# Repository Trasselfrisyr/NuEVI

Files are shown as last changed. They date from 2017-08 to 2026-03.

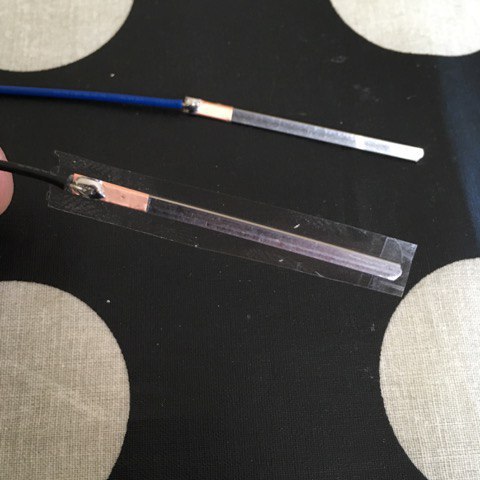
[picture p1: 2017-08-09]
hardware/bitesensor/bitesensor05.jpg

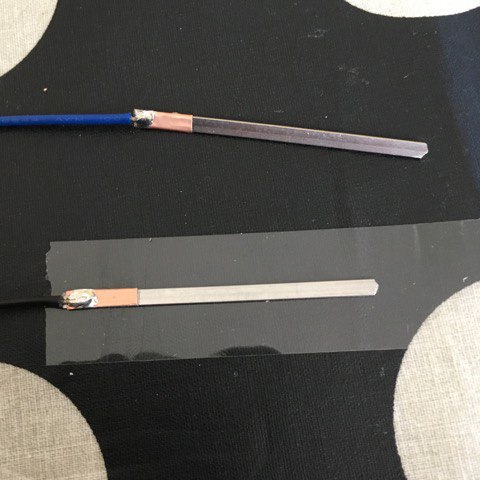
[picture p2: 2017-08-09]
hardware/bitesensor/bitesensor04.jpg

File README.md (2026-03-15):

### ⚠️ ORIGINAL REPO HAS BEEN MOVED TO BERGLUNDINST ORGANISATION ⚠️

This repository exists for archival purposes. Please update any references/links to https://github.com/berglundinst/NuEVI instead.

# NuEVI
A project by wind controller enthusiasts wanting to save the endangered Electronic Valve Instrument.

Follow the project at https://hackaday.io/project/25756-diy-evi-style-windcontroller

## Building NuEVI

NuEVI is easiest to build using the Arduino IDE. You will also need to download and install
[Teensyduino](https://www.pjrc.com/teensy/td_download.html) to build for and upload to the Teensy.

### Libraries

A few libraries need to be added that are not part of the default Arduino install. These can be
added directly via the Library Manager in the Arduino IDE:
* Adafruit MPR121
* Adafruit GFX
* Adafruit SSD1306 (version 1.2.9 or above)
* NuEVI also includes on the [Filters](https://github.com/JonHub/Filters) library by Jonathan Driscoll, but that is no longer an external dependency.

### Compile options

Open NuEVI.ino in the Arduino IDE. Under "Tools -> Board", select "Teensy 3.2 / 3.1". Then set
"Tools -> USB Type" to "MIDI".

### Building and uploading

Connect the NuEVI via USB to your computer, open the Teensy application and make sure the "Auto"
option is selected (the green round icon). In Arduino IDE, select "Sketch -> Verify/Compile" and
once that is complete press the reset button on the Teensy chip (you have to remove the top cover
on the NuEVI to access this). Upon resetting, it should upload the new firmware onto the NuEVI.

After uploading new firmware, you may need to reset the config memory of the NuEVI. To do this, press
and hold the MENU and ENTER buttons while turning on the NuEVI. Note that this resets all sensor calibrations too. For new versions this should not be neccessary, as value and version checks are in place.

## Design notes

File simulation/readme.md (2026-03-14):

# Simulator for NuEVI

This is a simple SDL2 based simulator that runs the NuEVI firmware compiled for MacOS. This is for testing the menu and is not supposed to produce any midi events.

## Requirements

* [SDL2.framework](https://www.libsdl.org/download-2.0.php) must be installed on your machine in /Library/Frameworks/.
* You probably need to have XCode and XCodes command line tools installed as well, but using brew to install make and clang might be enough.

[Dear Imgui](https://github.com/ocornut/imgui) is pulled in as an git submodule. Run `git submodule init --update` to get the code. The code is tested with tag v1.70 of ImGui, so if you run into problems make sure that is the checked out version.

## Know limitations

Currently only some input is simulated, and the default values are not based on real hardware. There is also a limitation on some keyboards on how many buttons can be pressed at the same time. This means that all menu functions cannot be tested.

## Future plans

* Add simulation for all inputs
* Show MIDI status in UI
* Add in-app log window
* Fake real breath input by keypress

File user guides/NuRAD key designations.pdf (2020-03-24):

Key designation chart

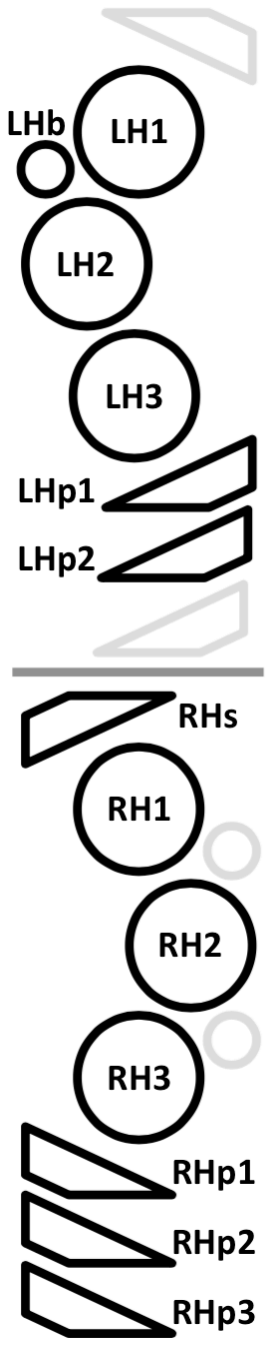
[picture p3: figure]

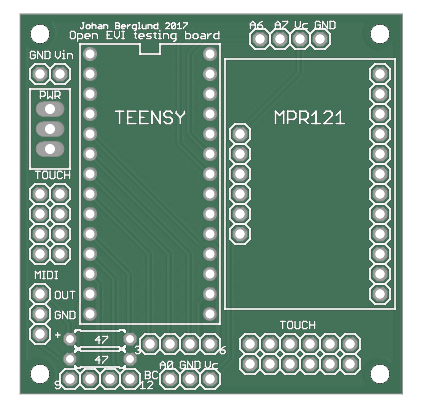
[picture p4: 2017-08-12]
hardware/devboard/devboardprevpic.png

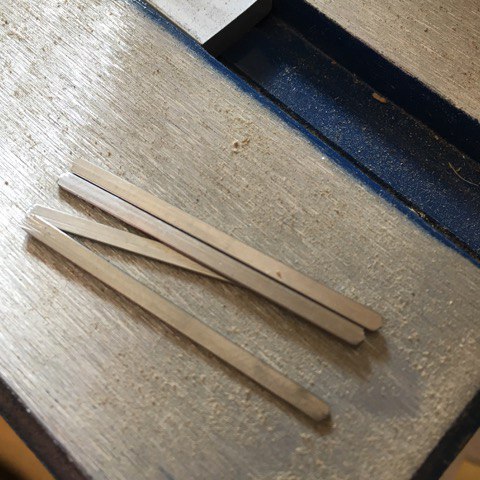
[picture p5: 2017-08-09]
hardware/bitesensor/bitesensor01.jpg

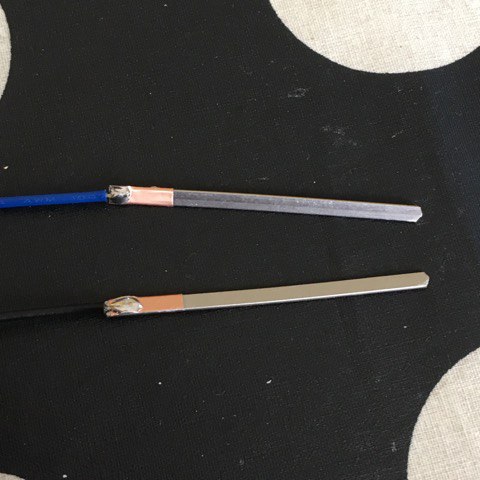
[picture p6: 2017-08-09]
hardware/bitesensor/bitesensor03.jpg

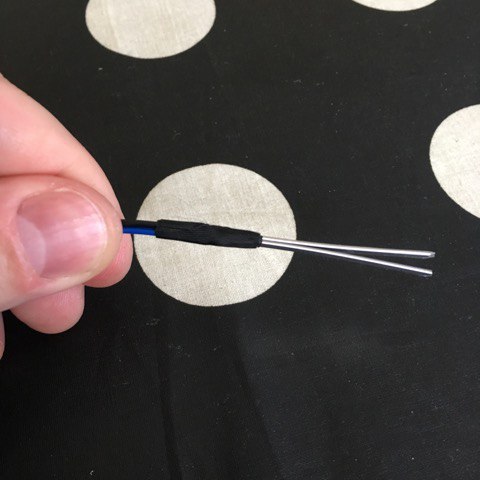
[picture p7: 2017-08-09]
hardware/bitesensor/bitesensor08.jpg

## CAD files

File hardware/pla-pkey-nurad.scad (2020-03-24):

w=8;        //key width, default 8
wc=10;      //mounting end outer diameter, default 10
l=15;       //key length (range normally increase in steps of 5)
hght=3;     //key height, default 3,3.5 and 4
angl=25;    //key end angle, default 25
estp=1.5;    //end step before angle, default 0.5
noext=0;    //set to 1 to get just the round part   

// 20/3,26/3.5,32/4 sk: 15/3 (estp 1.5)

 module prism(l, w, h){
       polyhedron(
               points=[[0,0,0], [l,0,0], [l,w,0], [0,w,0], [0,w,h], [l,w,h]],
               faces=[[0,1,2,3],[5,4,3,2],[0,4,5,1],[0,3,4],[5,2,1]]
               );
   }    
  
difference(){
    translate([0,0,0]) cylinder(h=hght,r=wc/2,,$fn=100);
    translate([0,0,hght-2]) cylinder(h=2.2,r1=1.6,r2=3.2,$fn=100);
    translate([0,0,-1]) cylinder(h=hght+5,r=1.6,$fn=100);
    //translate([-8,-8,0]) cube([16,2,3]);
    
}
if (!noext){
difference(){
    translate([-w/2,-l+1,0]) cube([w,l,hght]);
    translate([0,0,hght-2]) cylinder(h=2.2,r1=1.6,r2=3.2,$fn=100);
    translate([0,0,-1]) cylinder(h=hght+5,r=1.6,$fn=100); 
    translate([w/2-1,-l,hght]) rotate([180,0,90]) prism(l,1,1);  
    translate([-w/2-0.001,-l,hght-1]) rotate([90,0,90]) prism(l,1,1); 
    //translate([-w/2,-l+5.5,hght]) rotate([160,0,0])prism(w,15,15);
    translate([-w/2,-l,estp]) rotate([angl,0,0])cube(40,40,40);
}
}

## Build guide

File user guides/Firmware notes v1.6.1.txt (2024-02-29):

Firmware v1.6.1 notes

* Added min glide level setting GLIDE MIN and renamed GLIDE LMT to GLIDE MAX. Makes it possible to have a minimum glide other than zero. Also enables you to set up a range of glide CC in either direction to work within (setting min level higher than max level makes levels go opposite direction). 

Example for use is with Craftsynth 2.0 where the CC#5 glide control is divided in two ranges on the same CC, on either side of the 63 center value.

* Some improvements to CV portamento handling.

* Added support for a revised circuitry of power switch and charger board on LiPo/WL models. New BAT TYPE setting for this is LP2. If your controller has this revised circuitry, using LP2 instead of LP1 setting (previously named LIP setting) will change battery related messages in the display to make more sense for this setup. To know if your controller has got this revised circuitry, check switch behavior. If back position is ”off”, mid position is ”on” and front position is ”on+wireless” then you should use this new type setting. If positions are ”battery power off/USB power on” (back position), ”charge” (middle position) and ”battery power on” (front position), then the original LP1 setting should be used. 

* Added enable setting for the FastPatch function. Default is off, so if you are already using FastPatch, make sure to set this setting to ON. You find the new setting in EXTRAS – FASTPATCH. The advantage of having this default off is that holding the controller the "wrong way" (i.e. touching keys that control FastPatch) while operating menu buttons will no longer be a problem.

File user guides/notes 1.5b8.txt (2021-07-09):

NuEVI and NuRAD Firmware 1.5b8 Notes

1.5b1:

* Improved polyphonic play functions. Rotator menu is now replaced with a Poly Play menu where you find a variety of harmonization options, including three rotator setups. (Se separate manual page).

* Automatic sensor calibration when performing factory restore (so do mind that you don’t touch sensors when you do the reset).

* I2C communications speed issue solved.

* Adjustable MIDI CC time intervals for the breath messages, from 3ms to 15ms. For wireless play, lower setting than the default 6ms is not recommended. (BR INTERV setting in SETUP BR menu).

* Improved touch sensor reading equalization for NuRAD, for more coherent sensitivity between keys.

* Minor fix for NuRAD SAX fingering (LH2+RH2 now plays Bb).

* Gate hold function now works on NuRAD too.

1.5b2:

* Adjustment setting for thumb lever (for optimizing thumb portamento control). By setting THR (level of push force to activate) and MAX (level of push force to achieve maximum set portamento) values close to eachother at the desired point of activation, the new glide limit setting to desired rate will create a switching type set rate controller (similar to Crumar EVI glide key). With THR and MAX setup with separation to taste, a continous control up to level set by glide limit is achieved.

* Glide setting SWO, SWitching Only, sending only Glide on/off (CC#65) for use with synths where glide rate CC#5 is used in non standard ways, for example some DSI/Sequential synths like the Prophet REV2 or Prophet 12 where glide rates are set individually for each oscillator.

* Glide limit setting for portamento. Doubles as setting for portamento level sent using pinky key/mod key in GLD mode. (Can be changed both in menu and in GLD mode.)

* Setting of level for LVL, LVP and GLD now reqires touching both pinky/mod and third trill/RHp3 for setting mode activation, this to avoid accidental change of setting when pinky/mod key is touched.

* Rate of setting movement up and down for LVL, LVP and GLD has been adjusted. Became very much too fast after the timing issues were solved in 1.5b1

* A short delay before note offs in legato transitions is added to make playback of recorded midi behave correctly (keeping note on and note off from being registered on the same timestamp).

1.5b3:

* AUTOCAL is available for each ADJUST menu page. With cursor on THR or MAX bar, press UP and DOWN buttons at the same time (and keep off the sensors being calibrated). AUTOCAL will be displayed for two seconds, then updated settings will be shown.

1.5b4:

* Changed the destination setup for bite and lever to be less confusing and more powerful (custom CCs now possible). The VIB CTL item in the VIBRATO menu is now removed, and in SETUP CTL menu you will find BITE CTL, BITE CC, LEVER CTL and LEVER CC. 

BITE CTL and LEVER CTL can both be set to any of these destinations:
	OFF - no destination active for this controller
	VIB - vibrato
	GLD - glide/portamento (defined by GLIDE MOD and GLIDE LMT settings)
	CC  - custom CC output (defined in GLIDE CC and LEVER CC settings)

Settings in GLIDE CC and LEVER CC are only used when corresponding control is set to CC in its CTL setting as described above.

1.5b5:

* Changed names for ADJUST page titles (to shorten) and added numerical value readouts for THR and MAX settings.

* Corrected start position for rotators and added reset to first position when activated and on roller release (from top five octaves like for the otf key change).

1.5b6

* Added EVR to NuEVI fingering menu, for reversed roller action.

* Rebooting to program mode now possible when stuck at boot due to wrong version of firmware installed (NuEVI vs NuRAD version).

* Removed possibility to change portamento limit using pinky/mod key when in GLD setting (it was always getting altered in play or handling). This might come back if I find a better way to do it.

* Support for a CME WIDI Master Bluetooth MIDI board connected to Teensy underside pads. With this mod, if present it will be powered up by touching pinky/mod key and pressing enter in MIDI meny (what previously controlled the "slow midi" function that now is replaced by the CC interval menu item). "WIDI" will be indicated in the display below the MIDI channel number and the WIDI board will be powered up. Teensy pad connections: GND to GND (blue) of WIDI, 31 (TX2) via 47 ohm resistor to signal (green) of WIDI, 33 via 47 ohm resistor to power (red) of WIDI. 27 and 28 jumpered to indicate that the WIDI is connected.  

1.5b7:

* Added three new settings in EXTRAS MENU – CV TUNE, CV SCALE and CV EC LFO. The first two allow for software tuning of the CV output for 1V/Oct when using NuEVI CV, NuEVI Plus or NuEVI/NuRAD with external CV box or module. Also makes more simple versions of the CV boards possible (no potentiometers for adjustment). The CV EC LFO setting controls a new CV LFO vibrato function for the extra controller (lip sensor). It can be set to OFF (no extra controller LFO vibrato) or values 1 through 8, which represent vibrato freq from 4.5Hz to 8Hz. Default value is 3 (5.5Hz).

1.5b8:

* New quarter tone setting for Pinky Key (NuEVI) and Mod Key (NuRAD) – QTN. This makes the Pinky/Mod key a key for playing one quarter tone down using pitchbend (MIDI) or directly affecting the built in note CV output (using CV module or NuEVI CV/Plus). Pitch bend range for MIDI synth needs to be two semitones up/dn (or compensated for in pitch bend divider setting in the controller to make the resulting range two semitones up/dn). On NuRAD, it is recommended to set the 3rd LH Pinky key (EXTRA PKEY setting) to mirror MOD key for playablility.

* Changes to extra controller harmonics settings (experimental). Reverse direction options (ending with an ‘R’) available following the ones going up. This can be used with experimental mouthpieces where increased lip tension creates less touched sensor area.

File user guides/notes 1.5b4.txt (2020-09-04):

NuEVI and NuRAD Firmware 1.5b4 Notes

1.5b1:

* Improved polyphonic play functions. Rotator menu is now replaced with a Poly Play menu where you find a variety of harmonization options, including three rotator setups. (Se separate manual page).

* Automatic sensor calibration when performing factory restore (so do mind that you don’t touch sensors when you do the reset).

* I2C communications speed issue solved.

* Adjustable MIDI CC time intervals for the breath messages, from 3ms to 15ms. For wireless play, lower setting than the default 6ms is not recommended. (BR INTERV setting in SETUP BR menu).

* Improved touch sensor reading equalization for NuRAD, for more coherent sensitivity between keys.

* Minor fix for NuRAD SAX fingering (LH2+RH2 now plays Bb).

* Gate hold function now works on NuRAD too.

1.5b2:

* Adjustment setting for thumb lever (for optimizing thumb portamento control). By setting THR (level of push force to activate) and MAX (level of push force to achieve maximum set portamento) values close to eachother at the desired point of activation, the new glide limit setting to desired rate will create a switching type set rate controller (similar to Crumar EVI glide key). With THR and MAX setup with separation to taste, a continous control up to level set by glide limit is achieved.

* Glide setting SWO, SWitching Only, sending only Glide on/off (CC#65) for use with synths where glide rate CC#5 is used in non standard ways, for example some DSI/Sequential synths like the Prophet REV2 or Prophet 12 where glide rates are set individually for each oscillator.

* Glide limit setting for portamento. Doubles as setting for portamento level sent using pinky key/mod key in GLD mode. (Can be changed both in menu and in GLD mode.)

* Setting of level for LVL, LVP and GLD now reqires touching both pinky/mod and third trill/RHp3 for setting mode activation, this to avoid accidental change of setting when pinky/mod key is touched.

* Rate of setting movement up and down for LVL, LVP and GLD has been adjusted. Became very much too fast after the timing issues were solved in 1.5b1

* A short delay before note offs in legato transitions is added to make playback of recorded midi behave correctly (keeping note on and note off from being registered on the same timestamp).

1.5b3:

* AUTOCAL is available for each ADJUST menu page. With cursor on THR or MAX bar, press UP and DOWN buttons at the same time (and keep off the sensors being calibrated). AUTOCAL will be displayed for two seconds, then updated settings will be shown.

[removed for now - needs work] * Experimental breath controlled harmonic series (BRTH HARM and BR HM SEL settings). Like the lip sensor harmonics function, this shifts the fingered note up the harmonic series. For improved switching speed, try turning down the key deglitch time. (If this function is to be kept, I will probably need to tweak it quite a bit. Tongueing into higher notes and releasing them does not work well currently.)

1.5b4:

* Changed the destination setup for bite and lever to be less confusing and more powerful (custom CCs now possible). The VIB CTL item in the VIBRATO menu is now removed, and in SETUP CTL menu you will find BITE CTL, BITE CC, LEVER CTL and LEVER CC. 

BITE CTL and LEVER CTL can both be set to any of these destinations:
	OFF - no destination active for this controller
	VIB - vibrato
	GLD - glide/portamento (defined by GLIDE MOD and GLIDE LMT settings)
	CC  - custom CC output (defined in GLIDE CC and LEVER CC settings)

Settings in GLIDE CC and LEVER CC are only used when corresponding control is set to CC in its CTL setting as described above.

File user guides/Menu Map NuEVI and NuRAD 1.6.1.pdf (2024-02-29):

### Menu Map NuEVI/NuRAD 1.6.1

| | | Values | Default | Comment
TRANSPOSE | | | C> to >C< to <C | >C< | -12 to +12 semitones
OCTAVE | | | -3 to +3 | 0
MIDI CH | | | 1 to 16 | 1
POLY PLAY
| POLY MODE | | OFF | OFF | All poly functions disabled.
| | | MGR | | Major Gospel Root – a gospel type triad voicing
| | | MGD | | Major Gospel Dominant – same as MGR, but with a dominant on V instead of an inversion of the root
| | | MA9 | | Major add9 – pop style add9 harmonization
| | | MND | | minor Dorian – jazz type minor
| | | MNA | | minor Aeolian – classical minor
| | | MNH | | minor 4-voice Hip – a more hip dorian minor
| | | FWC | | Four Way Close – old school block chord harmony
| | | RTA | | Rotator A
| | | RTB | | Rotator B
| | | RTC | | Rotator C
| HMZ KEY | | C to B | C | Selects the key you are playing in for the key based harmonizations.
| OTF KEY | | ON/OFF | OFF | On the fly switching of played key by releasing rollers while not blowing.
| HMZ LIMIT | | 2 to 5 | 5 | Limit number of notes in harmonization. Applies to the key based harmonizations only.
| FWC TYPE | | 6 | 6 | Type of block chord for the Four Way Close harmonization
| | | m6
| | | 7
| | | m7
| FWC LOCKH | | ON/OFF | OFF | "Lock Hands" (double melody) adds another melody note one octave down for the FWC.
| FWC DROP2 | | ON/OFF | OFF | "Drop 2" moves the second note (the one below melody note) one octave down for the FWC.
| PRIORITY | | HI/LO | HI | Sets which note will get priority when playing mono patches
| ROTATOR A
| | RTA PARAL | -24 to +24 | | Fixed interval second note of rotator A
| | RTA ROT 1 | -24 to +24 | | First rotated third note of rotator A
| | RTA ROT 2 | -24 to +24 | | Second rotated third note of rotator A
| | RTA ROT 3 | -24 to +24 | | Third rotated third note of rotator A
| ROTATOR B

| | | Values | Default | Comment
| | RTB PARAL | -24 to +24 | | Fixed interval second note of rotator B
| | RTB ROT 1 | -24 to +24 | | First rotated third note of rotator B
| | RTB ROT 2 | -24 to +24 | | Second rotated third note of rotator B
| | RTB ROT 3 | -24 to +24 | | Third rotated third note of rotator B
| ROTATOR C
| | RTC PARAL | -24 to +24 | | Fixed interval second note of rotator C
| | RTC ROT 1 | -24 to +24 | | First rotated third note of rotator C
| | RTC ROT 2 | -24 to +24 | | Second rotated third note of rotator C
| | RTC ROT 3 | -24 to +24 | | Third rotated third note of rotator C
SETUP BR
| BRTH CC A | | OFF | BR
| | | MW | | Mod Wheel, CC#1
| | | BR | | Breath Controller, CC#2
| | | VL | | Volume, CC#10
| | | EX | | Expression, CC#11
| | | MW+ | | Mod Wheel, Hi-Res MIDI
| | | BR+ | | Breath Controller, Hi-Res MIDI
| | | VL+ | | Volume, Hi-Res MIDI
| | | EX+ | | Expression, Hi-Res MIDI
| | | CF | | Filter Cutoff, CC#74
| | | UNO | | UNO Synth, CC#20
| BRTH CC B | | OFF, 1 to 127 | OFF
| CC B RISE | | 1x to 10x | 1x
| BREATH AT | | ON/OFF | OFF | Aftertouch
| VELOCITY | | DYN, 1 to 127 | | Note on velocity
| CURVE | | -4 to LIN to +4, S1, S2, Z1, Z2 | LIN | Breath curve
| VEL DELAY | | OFF, 1ms to 30ms | 20ms | Wait time before sampling breath level for note on velocity
| VEL BOOST | | OFF, 1 to 9 | | Boost factor to compensate lower vel delay settings than 20ms
| BR INTERV | | 3 to 15 | 6 | MIDI CC send interval for breath. 6ms or higher for WL.
SETUP CTL
| BITE CTL | | OFF | GLD | No destination active for this controller
| | | VIB | | Vibrato

| | Values | Default | Comment
| | GLD | | Glide/portamento (defined by GLIDE MOD and GLIDE LMT settings)
| | CC | | Custom CC output (defined in BITE CC settings)
BITE CC | | 0 to 127 | | CC number for bite (sent if CC is selected in BITE CTL)
LEVER CTL | | OFF | VIB | No destination active for this controller
| | VIB | | Vibrato
| | GLD | | Glide/portamento (defined by GLIDE MOD and GLIDE LMT settings)
| | CC | | Custom CC output (defined in LEVER CC settings)
LEVER CC | | 0 to 127 | | CC number for bite (sent if CC is selected in LEVER CTL)
GLIDE MOD | | OFF | ON | Glide/portamento disabled
| | ON | | Send glide amount CC
| | SW | | Send CC for glide amount and on/of
| | SEL | | Roland SE/02 linear (on/off)
| | SEE | | Roland SE/02 exponential (on/off)
| | SWO | | Glide switching on/off only
GLIDE MAX | | 0 to 127 | | Max level for glide amount CC
GLIDE MIN | | 0 to 127 | | Min level for glide amount CC
VIBRATO
| DEPTH | OFF, 1 to 9 | 4 | Main vibrato level control. OFF disables manual vibrato completely.
| RETURN | 0 to 4 | 2 | Vibrato auto return level (do not use 0 value with PneuBite system)
| DIRECTION | NRM/REV | NRM | Vibrato controller direction, normal or reversed
| SENSE LVR | 1 to 12 | | Lever sensitivity setting for vibrato
| SQUELCH L | 1 to 30 | | Lever squelch setting (noise threshold)
| SENSE BTE | 1 to 12 | | Bite sensitivity setting for vibrato
| SQUELCH B | 1 to 30 | | Bite squelch setting (noise threshold)
EXCT CC A | | OFF | MW
| | MW | | Mod Wheel, CC#1
| | FP | | Foot Pedal, CC#4
| | CF | | Filter Cutoff, CC#74
| | SP | | Sustain Pedal, CC#64
EXCT CC B | | OFF, 1 to 127 | OFF
EXCT HARM | | OFF, 1 to 6 | OFF | Use Extra Controller (Lip Sensor) for going up or down in harmonic series, set range
HARM SEL | | HM1 | HM1 | Harmonics 1

| | Values | Default | Comment
| | HM2 | | Harmonics 2 (7th harmonic not excluded)
| | 5TH | | 5ths and octaves, up
| | OCT | | Octaves, up
| | H1R | | Harmonics 1, down/reverse
| | H2R | | Harmonics 2 (7th harmonic not excluded), down/reverse
| | 5TR | | 5ths and octaves, down/reverse
| | OCR | | Octaves, down/reverse
| DEGLITCH | OFF, 1-70ms | 20 | Fingering deglitch time
| PINKY/MOD KEY | -12 to -1 | PBD | Semitones down
| | PBD | | Pitch bend divider (MIDI EVI legacy function)
| | +1 to +12 | | Semitones up
| | ECB | | Extra controller B CC sent as momentary switch 0/127 value
| | ECS | | Extra controller momentary switching from A to B CC output
| | LVL | | Level setting by pinky key+first or second trill key
| | LVP | | Same as LVL, but stored level value is sent at power on
| | GLD | | Glide control using pinky key. Set level using glide limit setting.
| | ECH | | Momentary extra controller harmonics activation
| | QTN | | Quarter tone down (using MIDI pitch bend)
| LEVEL CC | AT, 1 to 127 | | CC number for level control
| EXTRA KEY (RAD) | OFF, -12 to -1, MOD, 1 to 12 | | Setting for LH pinky key 3 on NuRAD
| FINGERING (EVI) | EVI | EVI | EVI fingering
| | EVR | | EVI fingering with reversed roller action
| | TPT | | Trumpet (experimental) Rollers controlling harmonics, K4 switching between harmonic series version
| | HRN | | Double horn (experimental). Rollers controlling harmonics, K4 switching between horns
| FINGERING (RAD) | EWI | EWI | Standard EWI fingering
| | EWX | | Extended EWI fingering
| | SAX | | Sax fingering (allow low fingers to stay on keys)
| | EVI | | EVI fingering
| | EVR | | EVI fingering with reversed roller action
| ROLLRMODE | 1 to 4 | 2 | 1 = Legacy, 2 = Release mem, 3 = Touched pair+release mem, 4 = Bonus octave on top
| PITCHBEND | OFF, 1/1 to 1/12 | 1/1 | Pitchbend output control, disable or divide output to limit range
ADJUST | | | | UP+DOWN buttons together for automatic calibration when THR or MAX bar is flashing

| | Values | Default | Comment
| BREATH | THR/MAX
| LEVER | THR/MAX
| TOUCH | THR | | (Note reverse sns indicator movement)
| LIP/EC | THR/MAX
| BEND | THR/MAX
| BITE | THR/MAX
EXTRAS
| LEGACY PB | ON/OFF | OFF | Enable MIDI EVI legacy controls using pitchbenders up+down for activation
| LEGACY BR | ON/OFF | OFF | Enable MIDI EVI legacy controls using negative breath (sucking) for activation
| GATE HOLD | ON/OFF | OFF | Enable gate hold function (touch all rollers and switch on/off with pitch bend up/down)
| 3RD TRILL | +4/+3 | 4 | Semitones for EVI third trill key
| BCAS MODE | ON/OFF | OFF | Set legacy instant controls to not require touching pitch bend up for patch change
| DAC OUT | BRTH/PTCH | PTCH | Set DAC output mode. For using built in or external CV board, use PTCH (pitch) setting.
| BAT TYPE | ALK, NMH, LIP, LP2 | ALK | Set battery type for correct indication of battery level
| FAST BOOT | ON/OFF | OFF | Enable faster startup of the NuEVI/NuRAD
| FASTPATCH | ON/OFF | OFF | Enable FastPatch function
| CV TUNE | -99 to +99 | | Set tuning for note CV output
| CV SCALE | -99 to +99 | | Set scaling for note CV output
| CV EC LFO | OFF, 1 to 8 | 3 | Set rate of LFO vibrato controlled by lip sensor (4.5Hz to 8Hz)
| WL POWER | 0, -6, -12, -18 | | Send command to Panda system, 0 is full power
| WL CHAN | 4 to 80 | | Send command to Panda system, start channel search at this channel#
ABOUT | | | | Display version number and battery charge level

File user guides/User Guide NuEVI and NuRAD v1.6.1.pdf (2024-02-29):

# User Guide

## NuEVI and NuRAD Firmware v.1.6.1

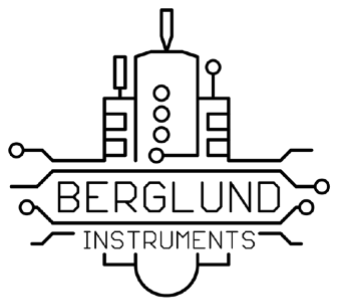
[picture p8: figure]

Johan Berglund
2023-03-29
NuEVI and NuRAD User Guide | 1

## Origins

The Electronic Valve Instrument was invented back in the early 1970s by Nyle Steiner. The first production instruments were using mechanical switches in a handset connected to an analog synthesizer module, and they were sold from 1975 to 1979 by the Steiner-Parker company. When the company had dissolved, the instrument was produced by Crumar.

In the mid 80s, Steiner designed and built a number of instruments with a more complex synthesizer and touch sensing for the keys. They were referred to as Steinerphones, and and came in both brass and woodwind variety.

In 1987 a new type of EVI was licensed and sold by AKAI. This new version together with its woodwind counterpart released at the same time, the EWI, was using touch sensing for the finger controls and a programmable synth module capable of sending MIDI for controlling other synthesizers. The Akai EVI was discontinued due to not selling as well as the EWI that is still made by AKAI in new incarnations.

For a while Nyle Steiner did conversions of then current model EWIs into EVIs, until in 1998 when he started building and selling the MIDI EVI he had developed. The MIDI EVI was built to work as a controller for MIDI equipped synthesizers, with no sound synthesis capability of its own. For several years this has been the controller/instrument of choice for EVI players, even when the newer EWIs got alternative EVI fingering settings.

In recent years the MIDI EVI has become hard to come by. Steiner has moved on to many other projects and interests, and so very few new EVIs are being built. In 2012 he posted a YouTube video demonstrating a prototype for an Arduino based EVI that people could build themselves. In 2017 it was still unclear when the Arduino EVI kit would be available. As the only available EVI would be in kit form and not available as a pre-built instrument, some EVI players started to get a bit concerned about the future of the EVI. With no new instruments being built, the EVI would eventually die. In hope to prevent this, EVI player Steve Anderson initiated a project aiming to create a new EVI. After teaming up with Johan Berglund moving forward with the project, the NuEVI was born.

As popularity of the NuEVI grew, EWI players started to get in touch, wanting an EWI counterpart to the NuEVI. When development was initiated for this new EWI, a number of factors pointed to the RAD EWI as the suitable version to modernize and build for people. The original RAD MIDI EWI was made by Nyle in 2004, for saxophone and EWI player Michael Brecker. The RAD EWI featured a new, radical, redesign putting the keys for left and right hands side by side, and having handles attached so it could be played without the use of a neck strap. Michael Brecker was very pleased with this new controller and used it on tour. No additional RAD EWIs were made though, and the controller could have become just this one-off mythical beast.

Development of the NuRAD was done in parallel with building NuEVIs and while it took more than a year to get it all ready, some ideas for the NuRAD would also be available as optional features for the NuEVI, the PneuBite in particular. The PneuBite is based on the bite sensor in the vintage Steiner Master’s Touch system, and rather than measuring capacitance between two strips of metal, it senses the air pressure in a closed system where squeezing or bending the mouthpiece will alter the pressure. As an improvement over the original, a pressure valve is added, allowing for equalization to ambient air pressure.

## Contents

Instrument overview | 5
Holding and controls | 7
Connections | 11
Power | 12
Settings | 15
TRANSPOSE | 15
OCTAVE | 15
MIDI CH | 15
POLY PLAY | 16
SETUP BR | 19
SETUP CTL | 23
ADJUST | 32
EXTRAS | 36
Patch selection | 40
FastPatch selection | 40
All notes off | 41
Special key | 42
Gate Hold | 44
Legacy instant controls | 45
Nyle’s program button functions | 46
Pitch bend pad adjustment | 48
Pinky Key adjustment (NuRAD) | 48
Battery check | 48
Battery replacement (AAA and AA) | 49
Firmware updates | 49
Factory restore | 50
Fingering charts (NuRAD) | 51
Fingering chart (NuEVI) | 53
Wireless MIDI (option) | 54
Troubleshooting tips | 55

## Instrument Overview

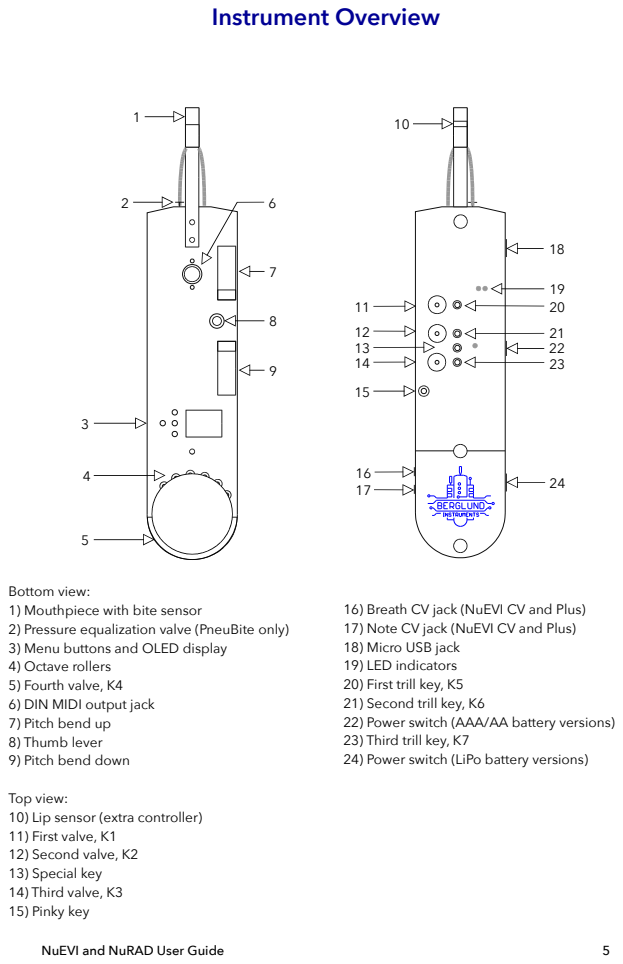
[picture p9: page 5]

Bottom view:
1) Mouthpiece with bite sensor
2) Pressure equalization valve (PneuBite only)
3) Menu buttons and OLED display
4) Octave rollers
5) Fourth valve, K4
6) DIN MIDI output jack
7) Pitch bend up
8) Thumb lever
9) Pitch bend down

16) Breath CV jack (NuEVI CV and Plus)
17) Note CV jack (NuEVI CV and Plus)
18) Micro USB jack
19) LED indicators
20) First trill key, K5
21) Second trill key, K6
22) Power switch (AAA/AA battery versions)
23) Third trill key, K7
24) Power switch (LiPo battery versions)

Top view:
10) Lip sensor (extra controller)
11) First valve, K1
12) Second valve, K2
13) Special key
14) Third valve, K3
15) Pinky key

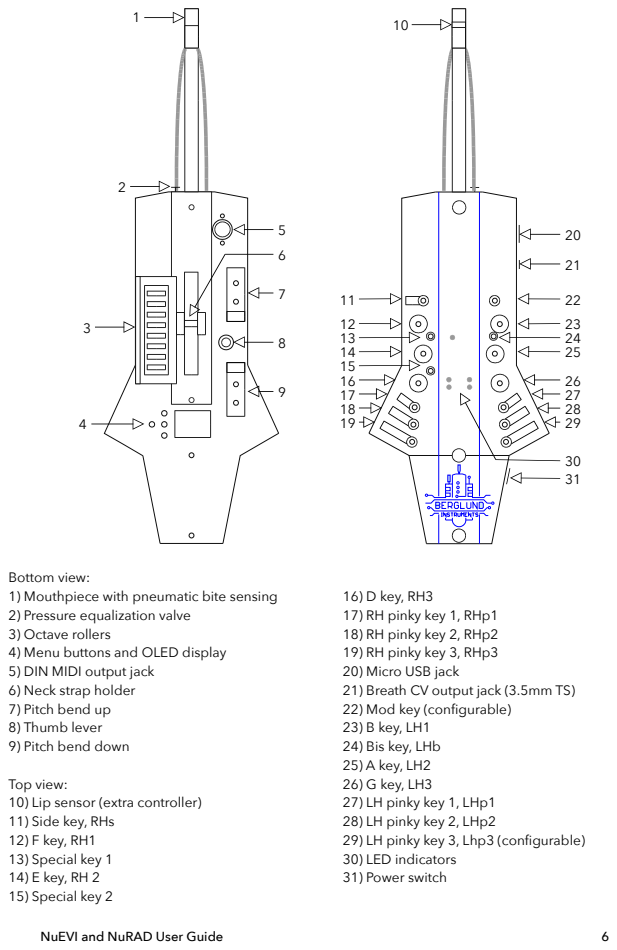
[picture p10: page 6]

Bottom view:
1) Mouthpiece with pneumatic bite sensing
2) Pressure equalization valve
3) Octave rollers
4) Menu buttons and OLED display
5) DIN MIDI output jack
6) Neck strap holder
7) Pitch bend up
8) Thumb lever
9) Pitch bend down

16) D key, RH3
17) RH pinky key 1, RHp1
18) RH pinky key 2, RHp2
19) RH pinky key 3, RHp3
20) Micro USB jack
21) Breath CV output jack (3.5mm TS)
22) Mod key (configurable)
23) B key, LH1
24) Bis key, LHb
25) A key, LH2
26) G key, LH3
27) LH pinky key 1, LHp1
28) LH pinky key 2, LHp2
29) LH pinky key 3, Lhp3 (configurable)
30) LED indicators
31) Power switch

Top view:
10) Lip sensor (extra controller)
11) Side key, RHs
12) F key, RH1
13) Special key 1
14) E key, RH 2
15) Special key 2

## Holding and controls

The way you are holding your instrument will affect both comfort and performance. For both the NuEVI and the NuRAD there are a couple of things to note regarding this. One common mistake for example is to place the thumb controlling the octaves on just one roller at a time, when the correct octave positions are between rollers, touching two at a time. Getting these things right from the beginning will help getting you faster to the point where the instrument feels like an extension of yourself in your musical expression.

The NuEVI canister is held with left hand in a way that the thumb is more or less vertical onto the rollers. Index finger should be free to touch and release the fourth valve, a.k.a. K4, a.k.a. the half octave key that is black arc in the front of the main body. The other fingers grip around the canister without touching the fourth valve.

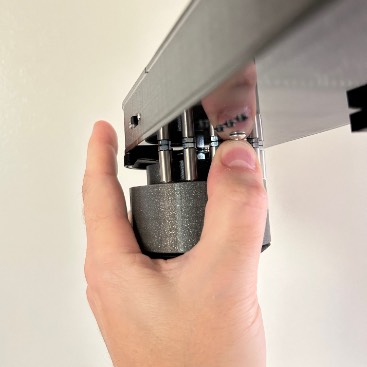
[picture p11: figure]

Right hand thumb is placed between the two pitch bend pads and on top of the (vibrato) lever. Make sure it’s not too easy to be touching the pitch benders inadvertently while playing, yet not too hard to reach the pitch benders when you want to use them.
Loosen the screws and adjust if needed. Be
careful not to over tighten as the benders are

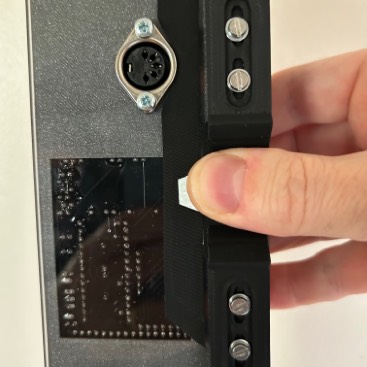
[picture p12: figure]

plastic. In some cases there is an additional pad behind the thumb lever. That’s an extension of the extra controller sensor routing. Usually the extra controller is actuated with the lip sensor, but if using the optional mouthpieces available, the lip sensor is removed and instead this pad can be used. If the standard bite type mouthpiece is installed, both the lip sensor and the touch pad can be used.

The NuRAD can be used either with a neck strap or with handles. The handles can be removed if using neck strap. To remove the handle, put the NuRAD up side down on your lap or on a soft surface. Snap the handle out of the slot in the back of the instrument, then slide the handle out of first one side, then the other. Note the way it is oriented for when you decide to put it back. The handle bends down a bit at the sides. To reinstall the handle, start with the sides, then snap it in place in the slot.

When holding the NuRAD, either with or without the handles, preferably use an angle of about 45° out from the body. This makes the balance right and it also reduces the possibility of liquid (spittle) going onto the instrument body. Like with the NuEVI, the pitch benders should be adjusted so that they are easily reached when playing, but not easily touched by accident. As the hand is moving around more on the NuRAD reaching for keys, the benders usually need to be placed a bit further away from the thumb.

The mouthpiece has three sensors. The primary one is the breath pressure sensor. It controls note on/off and the continuous control value for breath sent to the synthesizer. The breath sensor system is of the closed kind. That means no air is flowing through the instrument when it is played. Instead you let air slip out by the sides of the mouthpiece when blowing into it. The second mouthpiece sensor is the bite sensor. This is configurable to provide bite vibrato like on the Akai EWI or to control portamento (glide). A slight bite or bend to the mouthpiece will increase the glide time. When released, it goes back to zero/no glide. Third, there’s the extra controller sensor on top of the mouthpiece. This is a lip sensor that is touch sensitive and it can be set to control modulation, growl or sustain (hold).

If the PneuBite system is installed (standard on NuRAD and on most NuEVI from late 2022 and forward), make sure to press the valve below the bite sensor tube every time you pick up your instrument to play. This is especially important if you are using the bite sensor for portamento control. The system is sensitive to factors as ambient air pressure and temperature, so pressing the valve button before a playing session ensures the pressure level in the system is right and the bite response is as accurate as possible. After a couple of minutes of playing in normal room temperature, the pressure is slightly higher due to air expansion when mouthpiece is heated by body temperature. Therefore, the calibrated threshold setting in the portamento adjustment menu is set a bit above the pre-warmup reading, allowing it to rise a bit when warmed up without going over the threshold activating the portamento. The bite sensor LED is a good tool for monitoring the bite. If you pressed the valve before the session, but after a minute of playing the LED is glowing faintly even if you are not applying bite pressure or bending to the mouthpiece, you should raise the THR setting for the portamento slightly (see adjustment section).

On the NuEVI the the right hand has controls both on top of the instrument and on the bottom. Topside, there are three main valves (-2, -1 and -3 semitones), three trill keys (+2, +1 and +4 semitones), a ”special key” between two of the trill keys for chord and interval functions, and a configurable pinky key. The keys are all activated by touch. On the bottom there are two touch sensitive pitch bend plates, behind and in front of the thumb. They are proportional and send pitch bend up and down in response to how much you let your thumb press against them. Between the pitch bend pads, there is a vibrato lever. This also sends pitch bend control to your synthesizer, but in a manner focused on vibrato. The lever senses position change. A forward movement triggers a slight pitch bend down followed by a return to zero when the movement stops. The movement back will then trigger a slight pitch bend up, followed by return to zero when movement stops. This creates a very violin like vibrato in a way that will feel natural to the player. A slight shaking hand motion back and forth with your thumb kept on the lever will produce this.

Left hand controls octaves and the fourth valve (perfect fifth, -5 semitones). Octaves are controlled using the thumb rollers. Let your thumb rest between two rollers. Rotate your hand while holding the canister and let your thumb move along the arc of rollers to change octaves. Octaves go from -3 (thumb left of leftmost roller, not touching it), to -2 (touching only the leftmost roller), -1 (between the first two rollers) and all the way up to +3 (between the two last rollers). Your index finger controls the fourth valve (-5 semitones).

On the NuRAD there is a similar, but slightly different setup. Topside, there are three main keys, three pinky keys, a side key and a ”special key” (consisting of two keys to be touched simultaneously to activate) for chord and interval functions. On the bottom there are two pitch bend pads and a lever like on the NuEVI, but for NuRAD it can be useful to have the lever control portamento instead of vibrato.

Left hand top controls are three main keys, a bis key, two standard pinky keys, one configurable pinky key and a configurable side key called the mod key. Octaves are controlled using the thumb rollers on the bottom side. Let your thumb rest between two rollers. Swipe your thumb up and down over the rollers to change octaves.

## Connections

The NuRAD/NuEVI has two main ways of connecting to synthesizers and computers. The first is using the standard DIN MIDI OUT jack, connecting using a standard MIDI cable to the MIDI IN of a hardware synth or computer MIDI interface. The second way is by using the Micro USB port on the side of the NuRAD/NuEVI. Using a standard Micro USB charge/sync cable, you can connect the controller to any computer or MIDI USB host hardware supporting class compliant MIDI over USB. The instrument will be recognized by your system as ”NuRAD MIDI” or ”NuEVI MIDI”. Using a Lightning to USB Camera Adapter, you can even connect your NuRAD/NuEVI directly to an iPad or iPhone and use it with soft synth apps. The Micro USB connection will also power the NuRAD/ NuEVI when the battery switch is in the back most position (battery power off). The low power requirement of the NuRAD/NuEVI makes it possible to run it from any computer USB port, USB charger (please use quality ones and don’t put your instrument at risk) or even from your iPad. Mind that switching between USB power and battery power will switch the controller off and on again.

NuRAD model also features a of 3.5 mm mono jack for supplying breath pressure CV to analog synths. Breath CV is 0V–5V and is produced by the Teensy microcontroller with a fast 0.5ms update interval. Breath THR and MAX adjustment settings do have effect on this output, as it is not coming directly from the sensor.

NuEVI CV and NuEVI Plus has two 3.5 mm mono jacks in the front that will provide 1v/oct pitch CV and 0–10V breath CV (Eurorack levels). Tuning settings for the pitch CV are found in the EXTRAS menu.

## Power

Depending on your model you may have either a battery holder for AAA or AA batteries, or a built in LiPo power system. To monitor the battery power, the battery voltage will be indicated top right in the display when the main menu is activated. Values over 4.9V will indicate that the instrument is powered over USB, and below that it will indicate it as battery voltage. Normal voltage for a set of new alkaline batteries will be about 4.6V. The value will drop as the batteries are being used, giving a hint of the current battery condition. Below 3.8V they are due to be replaced, and the indicator will say BAT LOW. If you are using NiMH rechargeable batteries or the optional LiPo built in rechargeable battery, change the battery type setting in the EXTRAS menu to corresponding type. This will set the right threshold value for BAT LOW indication (3.6V for NiMH and 3.7V for LiPo). Going into the ABOUT menu, you will also see the set battery type and a rough approximation of remaining battery percentage.

To replace alkaline or NiMh batteries, make sure the NuEVI or NuRAD is switched off and disconnected from USB or DIN MIDI, then unscrew the frontmost thumbscrew on top of the controller and loosen the one at the back of the battery compartment slightly. Slide the lid forward and lift it off the controller. Replace the batteries (3xAAA or 3xAA depending on model, alkaline or NiMH) and slide the lid back in place. Get the front thumbscrew in place first, then tighten both screws. Only finger gripping power should be applied. Do not use pliers or similar tools or you will most certainly scratch the plastics of your instrument.

For the LiPo system, here’s the deal. First of all, LiPo batteries can be really nasty if you do bad stuff to them, so don't ever puncture or otherwise put the

LiPo cell in any kind of extreme situation with heat, water, fire, etc. Now, this cell used in the NuEVI is small (1500mAh, 3.7V), and it has protection against over voltage, short circuit and under voltage, and we are charging it with a relatively small current (<430mA), so normal use should be all safe. And of course, the LiPo cell should be recycled in a proper way if for any reason replaced or retired, not ever just thrown in the bin.

With the LiPo battery solution installed, the NuEVI or NuRAD has three positions on the power slide switch instead of two. (Original version, use LP1 setting in EXTRAS – BAT TYPE for correct representation in display.)

The switch positions are:

[ • ] [ ] [ ]

Leftmost position – Power ON from battery, battery time 20+ hrs

[ ] [ • ] [ ]

Mid position – Power OFF, battery charge when USB is connected to a USB power adapter (500mA or higher) Charges to 80% in 3.5hrs, 100% in 5.5–6 hrs. The red LED in the battery compartment is lit until the battery is fully charged.

[ ] [ ] [ • ]

Rightmost position – Battery power off, power ON from USB if connected (no charging, low power consumption)

As of late March 2023 there is also a revised version of the LiPo wiring for charger and power switch. The main advantage of this is having one of the switch positions controlling power to the wireless board (if installed). It can also charge independent of switch setting, but the low current draw USB only power mode is no longer available. (If you have this configuration in your controller, make sure to use LP2 setting in BAT TYPE menu.)

The switch positions for the revised version are:

[ • ] [ ] [ ]

Leftmost position – Power ON, Wireless ON

[ ] [ • ] [ ]

Mid position – Power ON, Wireless OFF

[ ] [ ] [ • ]

Rightmost position – Power OFF

For models with AAA or AA battery holder, the power switch has two positions: Left for battery power and right for USB power if connected. (Use ALK or NMH settings in BAT TYPE menu for correct display of status of alkaline and NiMh batteries respectively.)

## Settings

To simplify configuration, the NuRAD and NuEVI have been equipped with an OLED display and four navigation buttons. The middle buttons are MENU/ BACK (left) and ENTER (right), and the buttons above and below are the buttons for UP and DOWN selection. When not used for configuration or patch viewing, the display will be shut off to conserve power. Pressing MENU will activate the display and the main menu. A flashing cursor will indicate items, and ENTER will select the indicated item. Menu items directly controlling a setting will trigger a square being shown on the right in the display, with the adjustable value flashing inside it. Press UP and DOWN to select the desired value and then press ENTER or MENU to select that value and store it in non-volatile memory. The controller will remember this setting even if it is switched off. To make a temporary change that will not be stored, leave the menu open with the value flashing. After a while, the menu will shut off and the setting will not be stored.

TRANSPOSE
This menu item allows you to transpose the instrument up or down twelve semitones. Factory default transposition is C.

OCTAVE
This menu item changes the octave transposition of the instrument. Values go from -3 to + 3, with +0 as factory default.

MIDI CH
This menu item selects the active MIDI channel, 1 through 16, for both DIN MIDI and USB MIDI. Factory default is MIDI channel 1.

POLY PLAY

In the Poly Play menu you configure everything having to do with polyphonic playing functions.

POLY PLAY – POLY MODE

Here you select harmonization or rotator setup to be activated by holding MOD key (NuRAD) or Pinky Key (NuEVI) and touching Special Key(s). Deactivate by just touching Special Key(s). Chords contributed by Bert Lochs.

OFF – disables all Special Key functionality, including the Parallel Chord, Slur Sustain, Slur Sostenuto and Sub Octave functions (see Special Key section). MGR – Major Gospel Root – a gospel type triad voicing
MGD – Major Gospel Dominant – same as MGR, but with a dominant on V instead of an inversion of the root
MA9 – Major add9 – pop style add9 harmonization
MND – minor Dorian – jazz type minor
MNA – minor Aeolian – classical minor
MNH – minor 4-voice Hip – a more hip dorian minor
FWC – Four Way Close – old school block chord harmony (with additional options further down in the Poly Play menu)
RTA – Rotator A
RTB – Rotator B
RTC - Rotator C

POLY PLAY – HMZ KEY

Selects the key you are playing in for the key based harmonizations.

POLY PLAY – OTF KEY

Enables on the fly key change for the key based harmonizers. To change key on the fly while playing, finger the key (not blowing) and briefly lift your thumb off the rollers (when in octave two or higher). Key change on the fly will not be stored when powered off.

POLY PLAY – HMZ LIMIT

Limits the number of voices to be played, starting elimination from lowest note and up. Applies to the key based harmonizations only, not Rotator, Parallel Chord or Slur Sustain.

POLY PLAY – FWC TYPE

Type of block chord for the Four Way Close harmonization. (6, m6, 7 or m7)

POLY PLAY – FWC LOCKH

"Lock Hands" (double melody) adds another melody note one octave down for the Four Way Close harmonizations. (OFF/ON)

POLY PLAY – FWC DROP2

"Drop 2" moves the second note (the one below melody note) one octave down for the FWC. (OFF/ON)

POLY PLAY – PRIORITY

Sets which note will get priority when playing mono patches (sounds really great to layer a mono patch with a poly patch for use with with the Poly Play functions). HI will play the melody note as the mono lead and LO will play the rotated note or last note of other poly modes.

POLY PLAY – ROTATOR A, ROTATOR B, ROTATOR C

RTx PARAL
RTx ROT 1
RTx ROT 2
RTx ROT 3

This last section of settings the poly play menu is for the three rotators. They create a three note chord using the melody note, a fixed interval parallel note and a third note taken from a rotating selection of four notes. For every new note triggered, the rotation is advanced one step, and a new combination of notes is played. For each af the three selectable rotator setups you can configure the fixed interval with RTx PARAL and the four intervals to be rotated for the third note with RTx ROT 1 to RTx ROT4, where x represents rotators A through C.

Setting an interval to 0 disables the note output for that interval. For the rotated intervals, this also means it is skipped, moving on to the next note. This means you can have rotation between only two or three notes instead of four, or create a set interval or chord with no rotation.

Rotator original idea by Robby Kilgore.

SETUP BR

Menu for settings related to breath control.

SETUP BR - BRTH CC A

Sets the MIDI CC to be sent to represent the breath data.

OFF – No breath CC data is sent.
MW – Breath data is sent as CC#1 (Mod Wheel)
BR – Breath data is sent as CC#2 (Breath, factory default)
VL – Breath data is sent as CC#7 (Volume)
EX – Breath data is sent as CC#11 (Expression)
MW+ – High res breath data is sent on CC#1 and CC#33 (Hi-res Mod Wheel)* BR+ – High resolution breath data is sent on CC#2 and CC#34 (Hi-res Breath)* VL+ – High resolution breath data is sent on CC#7 and CC#39 (Hi-res Volume)* EX+ – High res breath data is sent on CC#11 and CC#43 (Hi-res Expression)* CF – Breath data is sent as CC#74 (Filter Cutoff)
UNO – Breath data is sent as CC#20 (for use with IK Multimedia UNO Synth)

*) Hi-res MIDI is very often not supported in the receiving end, i.e. synths or DAWs. It also uses more MIDI bandwidth. In most cases you are better off with the regular CC signal. In cases where smoothing is not implemented in the receiving end, Hi-res CC can be a way to get less stepping in the filter control. As an example, the Minibrute gets stepping in the sound when the filter cutoff is controlled with Aftertouch, but a smooth sound when the filter is controlled by high resolution Modulation Wheel data.

SETUP BR – BRTHCC B

Secondary MIDI CC for breath data. Can be set to any CC between 1 and 127 and be used together with CC A or on its own with CC A set to OFF.

SETUP BR – CC B RISE

Multiplier to faster reach top value for CC B compared to CC A. For example if you want to control amplifier (VCA) value with CC B and have it reach full value at 25% of full breath, while CC A controls filter (VCF) cutoff in normal fashion, set the CC B RISE to 4x.
1x – 10x (in steps of one)

SETUP BR - BREATH AT

Controls wether or not breath data should be sent as Aftertouch (Channel Pressure).
OFF - No Aftertouch breath data is sent (factory default)
ON - Breath data is sent as Aftertouch.

SETUP BR - VELOCITY

Note velocity can be set to follow the initial breath value dynamically (DYN) or to a fixed value (1 to 127). When fixed value is used, the velocity sample delay is also bypassed for optimal timing of note on vs rising breath signal.

SETUP BR - CURVE

This sets the breath sensor to control signal transfer curve. See curve diagram for a graphical representation of each curve.

-4 to -1 curves are more responsive (faster rising) in the low pressure end.
+1 to +4 curves are more responsive (faster rising) in the high pressure end. LIN is a straight linear signal transfer.
S curves have a faster transition in the middle and is less responsive in the low and high pressure ends.
Z curves have a slower transition in the middle and is more responsive in the low and high pressure ends.

The LIN curve is factory default.

SETUP BR - VEL DELAY

The time it takes for a tongued note to reach its attack peak is generally about 20ms. Normally, that’s the amount of time the NuRAD waits until it samples the breath pressure level to set the note velocity. However, there are situations where we would want to adjust that delay. For example, if we are using a high THR value for the breath sensor, some of the rising time will occur before the THR is reached and the delay time starts. Also, if the connected synthesizer is not responding to velocity, setting the delay shorter will increase the response time. Even if the synth responds to velocity, you can experiment with cutting down the delay time and compensating for lower velocity values with the VEL BIAS setting.

OFF – No velocity sample delay.

1 – Lowest delay setting
20 (factory default)
30 – Highest delay setting

SETUP BR - VEL BOOST

This setting helps boosting velocity values. Useful for compensating short velocity sample delay settings and for situations where you want to reach high velocity levels faster in relation to breath level.

OFF – Velocity bias disabled (factory default) 1 – Lowest setting
9 – Highest setting

SETUP BR - BR INTERV

Interval between breath messages sent. If your synth is not keeping up with the MIDI stream from your controller, try increasing the interval. Values below 6ms are not recommended for wireless use, and this is set as default value. Settings go from 3ms to 15ms.

SETUP CTR

Menu for settings related to controllers in general.

SETUP CTR - BITE CTL

Sets control destination for bite sensor.

OFF – No destination active for this controller
VIB – Vibrato
GLD – Glide/portamento (defined by GLIDE MOD and GLIDE LMT settings) CC – Custom CC output (defined in BITE CC settings)

SETUP CTR - BITE CC

CC number for bite (sent if CC is selected in BITE CTL).

### 0 to 127

SETUP CTR - LEVER CTL

Sets control destination for thumb lever.

OFF – No destination active for this controller
VIB – Vibrato
GLD – Glide/portamento (defined by GLIDE MOD and GLIDE LMT settings) CC – Custom CC output (defined in BITE CC settings)

SETUP CTR - LEVER CC

CC number for lever (sent if CC is selected in LEVER CTL).

### 0 to 127

SETUP CTR - GLIDE MOD

Settings for the portamento/glide function (controlled by the bite sensor).

OFF – No portamento CC data is sent.
ON – Portamento Time (CC#5) is sent.
SW – Portamento Time (CC#5) and Portamento Switch (CC#65) is sent. (default) SEL – Roland SE-02 linear mode.
SEE – Roland SE-02 exponential mode.
SWO – Switching only (CC#65 is sent for glide on/off).

SETUP CTR - GLIDE MAX

Max level for glide amount CC. Especially useful when triggering glide with pinky/mod key.

### 0 to 127

SETUP CTR - GLIDE MIN

MIN level for glide amount CC.

### 0 to 127

SETUP CTR - VIBRATO

Menu for vibrato settings.

SETUP CTR - VIBRATO - DEPTH
Main vibrato level control. OFF disables manual vibrato completely.

OFF – Vibrato lever disabled.
1 – Lowest vibrato depth setting
9 – Highest vibrato depth setting

The factory default setting is 4. Vibrato depth is also depending on the vibrato sensitivity settings. After fine tuning the lever and bite sensitivity for a smooth vibrato response, you may want to revisit the depth setting.

SETUP CTR - VIBRATO - RETURN

This setting lets you adjust the speed of the automatic return to zero for the vibrato. Values go from 0 to 4, where 4 is the fastest return and 0 is no automatic return, i.e. the vibrato lever will work as a conventional pitch stick. Normal EWI/EVI behavior is auto return, and the default setting is 2. Setting 0 is not recommended with bite sensor vibrato.

SETUP CTR - VIBRATO - DIRECTION

This setting lets you set the direction of the vibrato. For most people this should be kept to the default setting NRM (normal), where the pitch will fall in response to thumb movement in direction away from the mouthpiece, or rise in response to bite when bite sensor is used for vibrato. Setting REV will simply switch directions.

SETUP CTR - VIBRATO – SENSE LVR

This setting controls vibrato lever sensitivity. As individual vibrato sensors may vary in values a bit, this setting will help adjusting the sensitivity to get the best result. Setting values go from 1 to 12, where 12 is the most sensitive.

SETUP CTR - VIBRATO – SQUELCH L

This setting helps eliminate pitch bend MIDI chatter for when vibrato is not touched and idle. Setting it too high makes the vibrato lever require an unnecessary amount of movement before initiating vibrato, and with the setting too low the natural sensor noise will cause MIDI chatter around zero. To find the right setting, use a MIDI monitor software on your computer or other device. It should not be showing pitch bend activity when idle, yet be set close enough to this limit to allow good sensitivity when lever is touched slightly. When you are pleased with the setting, press ENTER or MENU to save it. Setting values go from 1 to 30, where 12 is the factory default.

SETUP CTR - VIBRATO – SENSE BTE

This setting controls vibrato sensitivity. As individual vibrato sensors may vary in values a bit, this setting will help adjusting the sensitivity to get the best result. Setting values go from 1 to 12, where 12 is the most sensitive.

SETUP CTR - VIBRATO – SQUELCH B

This setting helps eliminate pitch bend MIDI chatter for when bite vibrato is not touched and idle. Setting it too high makes the bite sensor require an unnecessary amount of movement before initiating vibrato, and with the setting too low the natural sensor noise will cause MIDI chatter around zero. To find the right setting, use a MIDI monitor software on your computer or other device. It should not be showing pitch bend activity when idle. When you are pleased with the setting, press ENTER or MENU to save it. Setting values go from 1 to 30, where 10 is the factory default.

SETUP CTR – EXCT CC A

The extra controller (lip sensor and/or touch pad) can be disabled or set to control transmission of selected MIDI CC data.

OFF – Extra controller is disabled.
MW – Mod Wheel (CC#1) data is sent. Disabled if breath data is sent over CC#1. FP – Foot Pedal (CC#4) data is sent. Growl on some synth patches. (default)
CF – Filter Cutoff (CC#74) data is sent.
SP – Sustain pedal (CC#64). Holds fingered notes until controller is released.

SETUP CTR – EXCT CC B

Secondary CC value to be sent with extra controller. Can be sent together with main CC for extra controller, or switched using mod key (see mod key settings). Values from 1 to 127. Default OFF.

SETUP CTR – EXCT HARM

To use the lip sensor extra controller for going through the harmonic series, set this to the range you want. A larger range makes it harder to control, as the touch sensitivity of the lip sensor is divided into the number of steps added. Values from 1 to 6. Default OFF.

SETUP CTR – HARM SEL

The harmonic series can be set up in a number of ways, going both up (best option for using the lip sensor) or down (useful for example with a custom experimental mouthpiece sensing amount of lip pressed against it).

HM1 – Harmonics 1
HM2 – Harmonics 2 (7th harmonic not excluded)
5TH – 5ths and octaves, up
OCT – Octaves, up
H1R – Harmonics 1, down/reverse
H2R – Harmonics 2 (7th harmonic not excluded), down/reverse 5TR – 5ths and octaves, down/reverse
OCR – Octaves, down/reverse

SETUP CTR - DEGLITCH

To reduce glitching when fingerings are changed, the deglitching function waits some milliseconds before considering a fingering “done” and settled. Beginners will probably feel the need to increase the deglitch setting, while virtuoso players could feel the need to reduce the setting.

OFF – Deglitching disabled

### 1 ms – Lowest deglitch setting

### 20 ms (factory default)

### 70 ms – Highest deglitch setting

SETUP CTR – MOD KEY / PINKY KEY

The mod key (LH side key) is the NuRAD equivalent of the NuEVI pinky key. The standard and legacy behavior of the NuEVI pinky key is to set the pitch bend signal to half its value while the key is pressed. In NuEVI and NuRAD, we have added the possibility to instead use this key for instant transposition (an adjustable trill key if you like) or as a control for synth volume or portamento, as well as some other functions.

- 12 – Transpose one octave down when mod key is held
- 1 – Transpose one semitone down when mod key is held
PBD – Pitch Bend Divide, PB and vibrato level is half value when mod key is held +1 – Transpose one semitone up when mod key is held
+ 12 – Transpose one octave up when mod key is held
ECB – Send on/off (0/127) for CC set in Extra Controller CC B setting
ECS – Switch between main and secondary CC to be sent using Extra Controller LVL – Level control. Set with 1st and 2nd RH pinky keys (RAD) or trill keys (EVI) LVP – Like above but current level is transmitted on power up.
GLD – Momentarily sends the the set glide limit amount as static glide level. ECH – Momentary extra controller harmonics activation.
QTN – Quarter tone down (using MIDI pitch bend)

When setting LVL/LVP, the breath and glide LEDs crossfade between them to indicate setting. All breath LED is 127 (max) and all glide LED is 0 (min).

PBD is factory default pinky key setting, as it is the legacy function of this key.

SETUP CTR – LEVEL CC

CC to be sent using pinky key level controls LVL and LVP. 1 to 127, default OFF.

SETUP CTR – EXTRA PKEY (NuRAD only)

Settings for the customizable extra LH pinky key, the LHp3.

OFF – LHp3 disabled
-12 – 12 semitones (1 octave) down
-1 – One semitone down
MOD – Use LHp3 as a secondary mod key (see MOD KEY above) +1 – One semitone up
+12 – 12 semitones (1 octave) up

SETUP CTR – FINGERING

Selects fingering mode. (See separate charts for details on NuRAD fingerings.)

EWI – Standard EWI fingering. Flexible, as it allows all keys to affect pitch at all times.
EWX – Extended EWI fingering. Releasing LH1 or touching RHp3 does octave shift where applicable, increasing range above and below the octave breaks. SAX – Saxophone fingering. Keys below relevant specified fingerings do not have effect on note selection. (Only LHp2 and RHs are always active for -1 and +1)
EVI – Electronic Valve Instrument fingering adapted for EWI. EVR – EVI fingering with reversed octave rollers.

On the NuEVI, the fingering menu offers the possibility of reversed roller action or a couple of experimental harmonic series based settings.

EVI – EVI fingering
EVR – EVI fingering with reversed roller action
TPT – Trumpet (experimental) Rollers controlling harmonics, K4 switching between harmonic series version
HRN – Double horn (experimental). Rollers controlling harmonics, K4 switching between horns

SETUP CTR – ROLLRMODE

Sets the way the controller handles octave rollers. Mode 1 = Highest touched roller, no release memory (legacy style); Mode 2 = Highest touched roller, release memory (default); Mode 3 = Touched roller pair, release memory. Mode 4 = Touched roller pair, release memory, bonus octave on top.

SETUP CTR - PITCH BEND

The pitch bend signal can be divided to work with synthesizers that are not able to set the pitch bend range low enough to fit this kind of instrument. As an example, if a synth has a set pitch bend range of 12 semitones up and down, setting the pitch bend divider to 1/12 will limit the range to just a semitone up and down. The OFF setting will disable the pitch bend pads. Vibrato depth follows the pitch bend divider setting. If the pitch bend pads are disabled, the vibrato will still work at 1/1 range.

OFF – No pitch bend data is sent.
1/1 – Full pitch bend range. (factory default) 1/2 – Half pitch bend range. ..
1/12 - A twelfth of the pitch bend range.

ADJUST

Selecting this menu item enters the sensor adjustment screen. Here you can monitor sensor reading values and change the threshold and maximum (sensitivity) values for the sensors. Scroll through the various sensors using UP and DOWN buttons and press ENTER to move the cursor to THR and MAX items, where UP and DOWN buttons increase and decrease the values (the indicator bar for the setting is moved right or left). Note that the MAX setting can never be set lower than the THR setting. A moving pixel (SNS) indicates the current sensor reading. Where several sensors are involved, a pixel for each sensor will be shown. Also note that the intensive updating of the OLED display while using the SETUP menu will interfere with the transmission of MIDI CC data. For that reason, the ADJUST menu is to be used for setup only, not to be activated during normal play. To perform an automatic calibration of any sensor page, press enter to move the cursor to THR or MAX bar, then press up and down buttons simultaneously. Make sure to keep fingers off the sensors when doing this.

ADJUST - BREATH

THR level sets the amount of pressure needed to trigger a note and start sending breath MIDI data. The breath indicator LED (blue) will light up when pressure is over threshold. If the LED is always lit, even when you are not blowing into the mouthpiece, you need to raise the THR setting until the LED turns off.

MAX sets the pressure level that should correspond to full signal output. This setting is of course to your individual preference, and with different settings of the breath to signal transfer curve (SETUP BR - CURVE) you may want to adjust this too.

ADJUST - LEVER

THR level sets the amount of forward thumb pressure on the lever needed to start sending control data. The portamento indicator LED (red) will light up when input is over threshold in case the lever is set up to control portamento. If the LED is always lit, even when you are not actuating the lever, you need to raise the THR setting until the LED turns off.

MAX sets the actuation level corresponding to full signal output.

ADJUST - TOUCH

THR sets the threshold for the keys and the octave rollers. When all keys and rollers are untouched, the SNS dots should all be to the right of the THR line. Keys touched one at a time, one of the dots should go left of the THR line. This both verifies connectivity and correctly set THR level.

ADJUST - LIP/EC

The extra controller, activated in the SETUP CTR menu, is the lip or embouchure sensor on top of the mouthpiece. It is a proportional touch controller, working much in the same fashion as the pitch bend pads.

THR sets the threshold for the lip touch sensor. Make sure the SNS indicator dot is to the left of the THR line when sensor is not touched.

MAX sets the lip touch corresponding to full controller signal output.

ADJUST - BEND

THR sets the threshold for the pitch bend touch pads. Make sure both of the SNS indicator dots are to the left of the THR line, or you will have issues with your pitch bend signal.

MAX sets the amount of finger pressure against pitch bend touch pads required for full signal output. When adjusting this setting, move your thumb up and down onto the pads to find a good setting. Note that what should be sent as full pitch bend signal is controlled in the SETUP CTR - PITCH BEND menu.

The sensor MAX setting should always be set so the SNS reading is reaching the MAX line when the pads are fully touched.

ADJUST - BITE

THR level sets the amount of bite or bend action on the mouthpiece needed to start sending portamento control data. The portamento indicator LED (red) will light up when bite input is over threshold in case the bite sensor is set up to control portamento. If the LED is always lit, even when you are not biting or bending the mouthpiece, you need to raise the THR setting until the LED turns off. If PneuBite system is installed, remember to press the valve button before calibration and put the THR level a bit higher than just right of the idle sensor reading to have some margin for rising value due to temperature change.

MAX sets the bite or bending level corresponding to full portamento signal output.

When using bite for vibrato, the bite adjustment is not relevant, but the SNS dot can still be a good indicator to check proper bite sensor response.

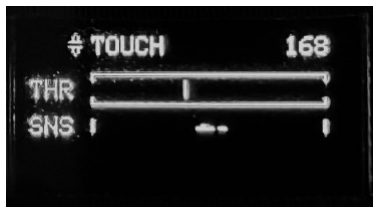
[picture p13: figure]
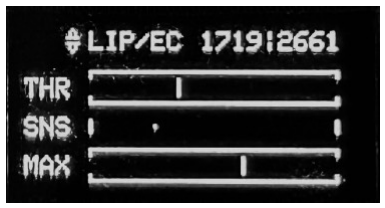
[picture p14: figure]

Typical settings. Note that for the touch sensor adjustment the THR bar is to the left of the sensor dot cluster, as the values go lower when sensors are touched. For the other sensors the dots move right on actuation, and the THR and MAX bars should be on the right of idle reading sensor dots.

EXTRAS

Various settings.

EXTRAS – LEGACY PB

ON/OFF switching for the legacy instant controls where both pitch benders are used. (See Legacy Controls section.)

EXTRAS – LEGACY BR

ON/OFF switching for the legacy instant controls where negative breath is used. (See Legacy Controls section.)

EXTRAS – GATE HOLD

Setting to disable the Gate Hold functionality to avoid accidental activation. (See Gate Hold section for details on using the Gate Hold function.)

EXTRAS – 3RD TRILL (NuEVI)

This setting controls the behavior of the 3rd trill key. Available options are +3 or +4 (default) semitones. As a hidden extra, the interval that is not selected here can be achieved by touching third valve key and third trill key at the same time. A mechanical mod making this practical is to mount a metal lip onto the trill key, making it protrude just above and behind the third valve key.

EXTRAS – BCAS MODE

This setting changes the behavior of the legacy instant controls, to not require touching pitch bend up for patch change. Only has effect when LEGACY BR is ON.

EXTRAS – DAC OUT

This setting controls the DAC output channel. The available options are:

BRTH - Output the breath sensor signal.
PTCH - Output note pitch (v/Oct).

For NuEVI Plus, NuEVI CV or standard NuEVI or NuRAD with CV box or module, the PTCH option should be selected.

EXTRAS – BAT TYPE

To have the battery voltage monitoring correctly representing the battery type used in the controller, use the corresponding setting.

ALK – Alkaline batteries (100% at 4.6V, LOW BAT at 3.8V)
NMH – NiMH rechargeable batteries (100% at 3.9V, LOW BAT at 3.6V)
LP1 – LiPo rechargeable battery (100% at 4.3V, LOW BAT at 3.7V)
LP2 – LiPo with revised wiring, this setting allows indication of charge status in menu and about screen.

EXTRAS – FAST BOOT

Enabling this setting will make the NuEVI start up as fast as possible when powered on.

EXTRAS – FASTPATCH

This setting enables use of the FastPatch function (see section on FastPatch selection).

EXTRAS – CV TUNE

Tuning of the CV output for 1V/Oct when using NuEVI CV, NuEVI Plus or NuEVI/NuRAD with external CV box or module. Modules usually ship with a suggested tuned value to enter here.

EXTRAS – CV SCALE

Scaling of the CV output for 1V/Oct when using NuEVI CV, NuEVI Plus or NuEVI/NuRAD with external CV box or module. Modules usually ship with a suggested tuned value to enter here.

EXTRAS – CV EC LFO

The CV EC LFO setting controls a CV LFO vibrato function for the extra controller (lip sensor). It can be set to OFF (no extra controller LFO vibrato) or values 1 through 8, which represent vibrato frequency from 4.5Hz to 8Hz. Default value is 3 (5.5Hz).

EXTRAS – WL POWER

To set the radio power of the optional midiBeam wireless kit, select a value in this menu and press enter. This should be done with the wireless receiver linked up (steady glowing LEDs on TX and RX). The available values are 0, -6, -12 and -18 dBm. 0 is the highest setting, and is the default setting in the midiBeam. NuEVI does not store the setting (it is only kept in the midiBeam) so the menu will always start on 0 when selected.

EXTRAS – WL CHANNEL

To set the radio channel of the midiBeam wireless transmitter, select a value in this menu and press enter. Available values are 4-80. After changing this, the transmitter and receiver will need to be paired again as the connection will be lost. Note that this is just an “initial channel” that the midiBeam will use, during pairing it will determine what the best channel is. The value is also not stored by NuEVI, so the menu will always start at 4 (the default midiBeam channel).

Before changing any of the wireless settings, please read through the midiBeam user guide describing these settings. This is available at http://pandamidi.com/support.

## Patch selection

Pressing the ENTER button when the display is off will show the currently selected patch number on the display for a couple of seconds. Pressing UP or DOWN changes the patch number. You can hold the button pressed to get a faster scrolling through the numbers. Pressing the UP or DOWN button when the display is switched off will directly enter the patch view mode and step the patch number up or down.

The patch number will be remembered by the controller even when powered off. Holding ENTER button while powering up the NuEVI/NuRAD will have it send a program change for the current patch selected.

## FastPatch selection

You can store up to seven patch numbers that can be instantly recalled by holding a combination of trill keys (NuEVI) or LH1, LH2 and LH3 keys (NuRAD) when pressing any of the buttons ENTER, UP or DOWN from display sleep or patch view state. (Just reach with your LH thumb without looking.) If no patch number is stored for the selected memory slot, the selection will be ignored, and the current patch number will be displayed.

To use this function, first make sure it is enabled in the EXTRAS – FASTPATCH setting. It is disabled by factory default.

To save a patch number into a memory slot, use UP and DOWN to select the patch you want to store (no trill keys touched). From display sleep, finger the key combination you want to use as memory slot, press and hold MENU, then immediately press ENTER while still holding MENU. The display will briefly indicate that the FastPatch has been set.
To clear a FastPatch memory slot, finger the key combination for the slot, press and hold MENU, then immediately press UP while still holding MENU. The display will briefly indicate that the FastPatch slot has been cleared.

Mind that accidentally touching trill keys/LH keys when using UP, DOWN or ENTER for patch selection will recall a FastPatch or just display the current patch if no FastPatch is set for that slot, so keep fingers off the trills if you are just doing regular patch selection.

## All notes off

Should a situation of stuck notes occur, a ”midi panic” or “all notes off” can be sent by pressing and holding the ENTER button, then the MENU button while still holding ENTER, from display off state. Big friendly letters on the display will also tell you not to panic.

## Special key

Introduced with the Steiner MIDI EVI, the special key added the possibility to play chords and intervals. This has been implemented in the NuEVI and NuRAD too. On NuRAD the special key has been divided into two keys to be touched at the same time, to lessen the risk of accidental activation.

To use special key functions, make sure POLY MODE in the POLY PLAY menu is not set to OFF.

The first function is slur sustain. To activate this, touch the Special key while holding a finger on LH pinky key 1 (NuRAD) or K4 (NuEVI arc key, fourth valve). Slur sustain will send a sustain (hold) pedal on command when a new note is tongued, keep it held as long as new notes are slurred, building chords by slurring and holding them until breath is released. A new chord can then be started by tonguing a new note. The latest chord or interval played will be stored for use with the parallel chord or interval function.

Parallel chord or interval is activated by touching the Special key while holding RH pinky key 1 (NuRAD) or K5 (NuEVI, first trill key). If no chord or interval has been stored by slur sustain, a default interval of a perfect fifth below the played note is used. Activating slur sustain will switch the parallel chord function off and any intervals or chords slurred will then overwrite the previously stored chord.

The sub octave double function is activated by touching the Special key while holding RH pinky key 2 (NuRAD) or K1 (NuEVI, first valve). This adds a note played one octave down from played note(s). This can be used in combination with slur sustain or parallel chord functions.

A new addition to the special key functions is slur sostenuto. It is activated by touching the Special key while holding LH pinky key 2 (NuRAD) or K2 (NuEVI, second valve). When activated, first note (or chord) will be locked in by MIDI sostenuto pedal and sound as long as following notes are slurred. Note that not all synthesizers support MIDI sostenuto. The slur sostenuto can be combined with parallel chord, sub octave double or harmonizer/rotator.

Last but not least there is the configurable poly play function that is activated by touching/holding MOD key (NuRAD) or Pinky Key (NuEVI) and then touching Special Key(s). In the POLY PLAY menu you can set this up to a number of alternative harmonizers and rotators. See the settings section for POLY PLAY for all the different options here.

When in any of these polyphonic modes, the orange LED on the Teensy will be flashing instead of glowing steadily.

Touching only the special key(s) will switch off any active special key functions.

## Gate Hold

A trick for getting smooth attacks on some synths, where you don’t need velocity values, is to keep notes always on and control the volume/filter with breath only. A way to do this is to change the breath THR value to be just slightly below the idle reading. This is a bit unpractical though, so we put in a little bonus thing to make it easier.

First make sure GATE HOLD setting in EXTRAS menu is ON, then continue below.

To activate Gate Hold on the NuEVI, grab the canister like a door knob, touching the side key and the bottom three rollers at the same time. Then touch the pitch bend up pad. On NuRAD, fold your thumb in to reach over all the uppermost rollers and touch pitch bend up pad. The Teensy LED will flicker fast to indicate activation, then keep flashing until deactivated.

To deactivate Gate Hold, do the same thing but with touching the pitch bend down pad. The LED will flicker three times to confirm.

## Legacy instant controls

The MIDI EVI was using fingering combinations to alter settings and send patch change commands. For advanced users this can still be a desired thing, so there’s support in the NuEVI for the most important parts.

Set this functionality on and off (default off) using the LEGACY PB setting in the EXTRAS menu.

When the legacy instant controls are activated, you can instantly recall a patch number by its respective MIDI note number. For example, by fingering middle C (any transpositions set are not active here) while not playing, you are selecting patch number 72. Touch both pitch bend pads at the same time to send the patch change command for the patch number you are fingering. The Teensy LED will flash once to confirm. Note that if that patch number is already the patch known as active in the NuEVI/NuRAD, the command will not be sent. To select patch numbers in the top and bottom end of the range 1 to 127, add the pinky/MOD key to your fingering.

Using MIDI channel switching can be useful for switching between synths or patches in performances. To instantly select a MIDI channel number, you can finger it using middle C and upwards chromatically, where mid C represents MIDI channel #1, touch the lip sensor with your lip, then touch both pitch bend pads at the same time. The Teensy LED will flash once to confirm. Note that a MIDI setting selected this way will not be remembered after powering off, unless you go into the MIDI CH menu to confirm the change. This way, if you have no idea why you suddenly can’t get a sound (because you accidentally managed to switch to some other MIDI channel) a power cycle will get you back in business.

Another way to trig the instant controls is to apply a gentle sucking (negative air pressure) to the mouthpiece, while touching pitch bend up, instead of touching both PB pads. To activate this functionality, go to LEGACY BR setting in the EXTRAS menu. Using the sucking together with pitch bend down, Nyle has added the legacy program button control (see below).

Yet another alternative way for patch number selection is to finger the number like above, then lock it in by momentarily touching the pinky key. Send mid range values by touching first valve and first trill keys at the same time, top and bottom range values by touching second valve and second trill keys at the same time.

## Nyle’s program button functions

I have added the equivalent of the vintage MIDI EVI programming button. It is activated by holding the down pitch bend and sucking. The legacy breath activate feature must be on for this to work.

Implemented so far:
1. Middle octave position (c72). Ability to assign midi breath parameters, midi volume, midi aftertouch, midi breath, midi expression and velocity.
1v - midi volume
2v - midi aftertouch
3v - midi breath controller
side button (4v) - midi expression

1tr - note on velocity
2. Lowest octave position (c36). Ability to increment - decrement and send midi patch change commands.
F29 - decrement and send patch change
G31 - increment and send patch change
E28 - subtract 10 and send patch change
F#30 - add 10 and send patch change
When NuEVI is turned on, Incr - Decr starts from whatever patch number is stored in EEPROM.
3v - send reverb amount cc91, value determined by pinky pitch latch. C36 equals zero. Vintage EVI never had this reverb send feature; I put it in here just because my own setup takes advantage of it.

I still want to add a C36 (open with no keys) All Notes OFF command but have not done it yet.

Pinky pitch latch works exactly the same as it does on the vintage midi evi. When not blowing, just press pinky key momentarily while holding a note fingering. The note and octave position will determine a value and store it in ram memory (latch). This value can then be assigned to a parameter using the programming button.

Note: Calling patch changes randomly by fingering is not part of this programming button feature and does not use the pitch latch. You simply suck with no pitch bend applied and a patch is sent according to which note you are holding. This simulates the missing patch change button that is also on the vintage midi EVI.

Nyle

## Pitch bend pad adjustment

The pitch bend pads can be loosened using a screwdriver and slightly shifted in distance from the thumb rest. Find the placement that makes most sense to you and tighten the screws. Don’t over-tighten, as you could cause damage to the conductive plastic of the pitch bend pads if you do. If the pad is not moving or wiggling when pressed against from the thumb rest position, you should be good to go.

## Pinky key adjustment (NuRAD)

The pinky keys can be also be loosened using a screwdriver (Philips) and rotated into favored positions. They can also be replaced with slightly longer or shorter keys, thinner/wider ones or ”blind” keys if you want to remove a key that you are not using. The keys are printed in conductive PLA plastic from a parametric 3D model where these values can easily be altered for printing of custom sized keys. The design file will be available for free on demand if you want to print your own keys, or Berglund Instruments can supply these keys already printed.

## Battery check

When the main menu is activated, the battery voltage will be indicated top right of the display. Values over 4.9V will indicate that the instrument is
powered over USB, and below that it will indicate it as battery voltage. Normal voltage for a set of new alkaline batteries will be about 4.6V. The value will drop as the batteries are being used, giving a hint of the current battery condition.

Below 3.8V they are due to be replaced, and the indicator will say BAT LOW. If you are using NiMH rechargeable batteries or the optional LiPo built in rechargeable battery , change the battery type setting in the EXTRAS menu to corresponding type. This will set the right threshold value for BAT LOW indication (3.6V for NiMH and 3.7V for LiPo).

Going into the ABOUT menu, you will also see the set battery type and a rough approximation of remaining battery percentage.

## Battery replacement (AAA and AA)

With the NuRAD/NuEVI switched off and disconnected from USB or DIN MIDI, unscrew the frontmost thumbscrew on top of the controller and loosen the one at the back of the battery compartment slightly. Slide the lid forward and lift it off the controller. Replace the batteries (3xAAA or 3xAA, Alkaline or NiMH type) and slide the lid back in place. Get the front thumbscrew in place first, then tighten both screws. Only finger gripping power should be applied. Do not use pliers or similar tools or you will most certainly scratch the plastics of your instrument.

## Firmware updates

Updates for the NuRAD/NuEVI firmware are supplied in .hex format when new features or bug fixes are released. The current firmware version is shown in the NuRAD/NuEVI display while powering on. Firmware upload is done using a software tool called Teensy Loader. It can be downloaded from https://www.pjrc.com/teensy/loader.html, where you also find instructions for using the Teensy Loader to upload the .hex file. To restart the NuRAD/NuEVI in program mode, making it visible to the Teensy software, press all four buttons by the display simultaneously while the display is not active (or open the case slightly and press the program button on the Teensy). If you get a message in the Teensy loader app that the hex file you selected is too big, just ignore it and put your instrument in program mode. The board version will be recognized and the hex file can be uploaded. If the app is in Auto mode it will upload as soon as you get the instrument in program mode, otherwise you need to click Program and Reboot after the Teensy chip has been recognized and the Teensy picture in the app has gone from faded to normal. Firmware update releases for NuEVI and NuRAD (they have separate .hex files for update) are found at https://github.com/Trasselfrisyr/NuEVI/releases

## Factory restore

Only if you are sure this is what you need to do – to restore the factory default settings, including sensor adjustments, hold ENTER and MENU buttons when switching on the NuRAD. Do not touch keys/sensors. Release buttons when the orange LED glows steadily. Make sure you take notes or take photos of settings and sensor adjustments before doing this. Your sensor calibrations will be off target when reset, and you have to set them right to have a well performing controller. Note that some older instructions for firmware update mentions doing a factory reset. This is not needed anymore and should better be avoided.

## Fingering charts (NuRAD)

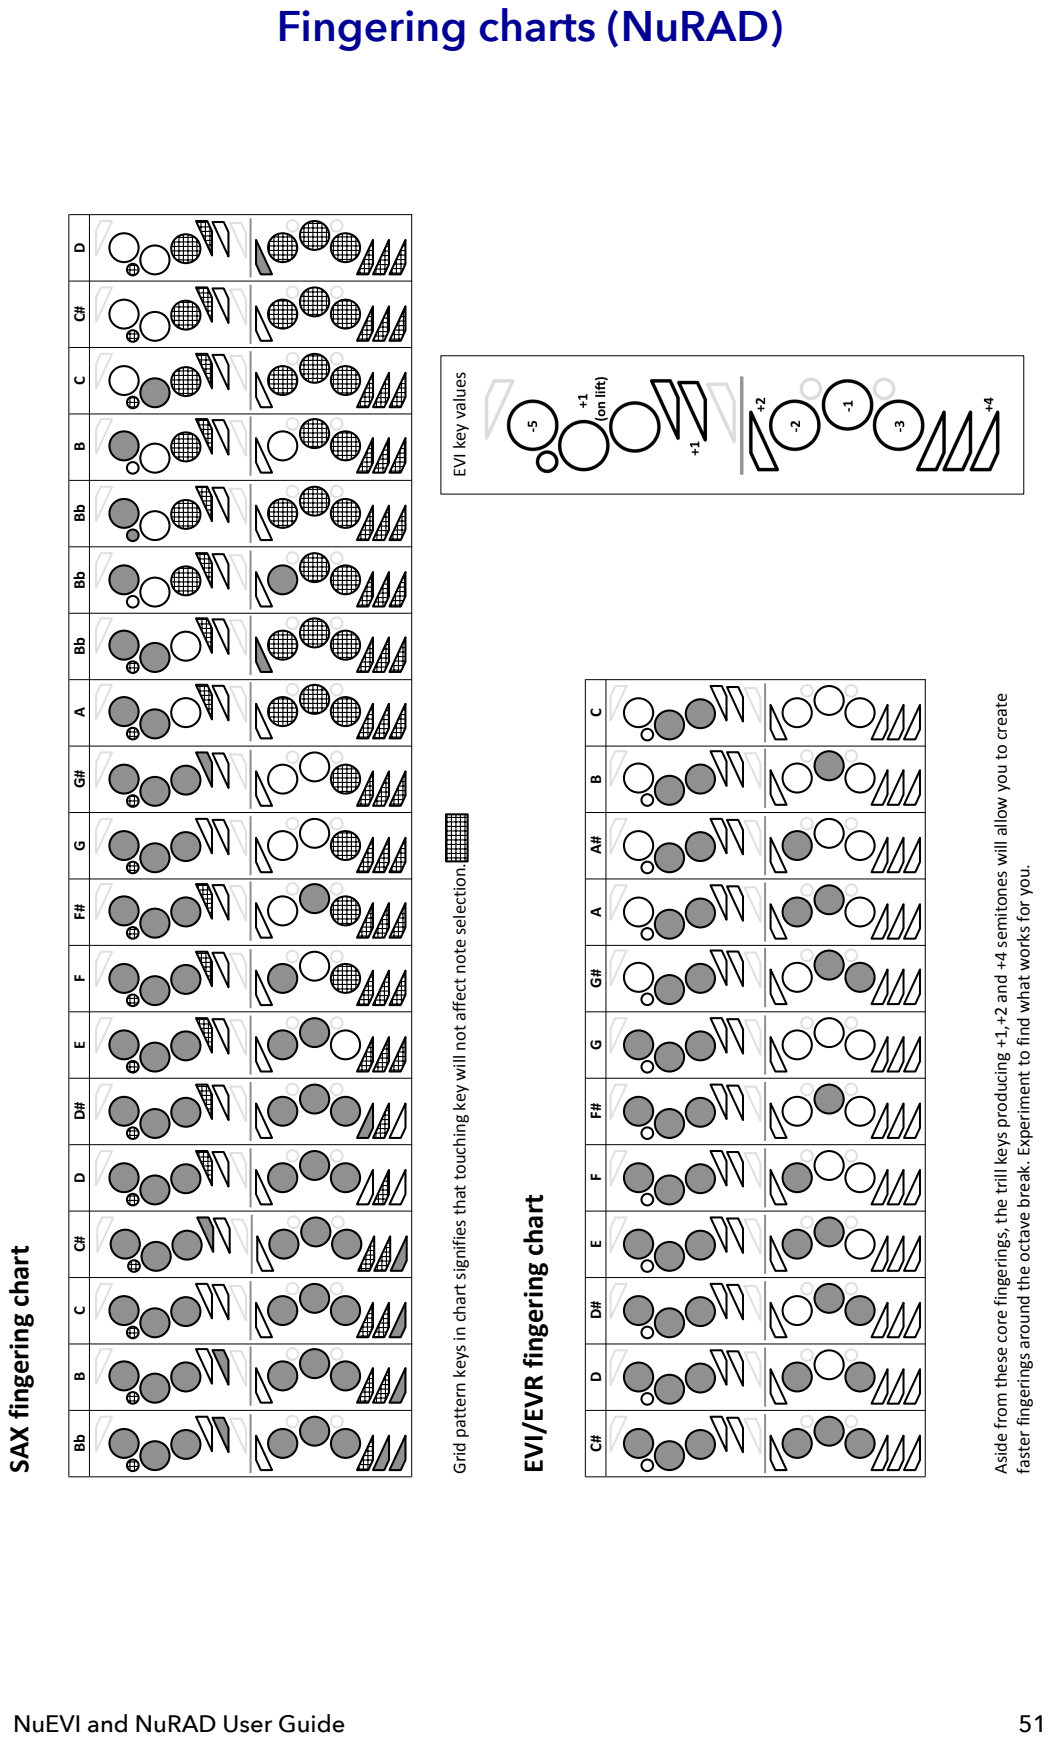
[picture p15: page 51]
NuEVI and NuRAD User Guide; 51 SAX fingering chart; Grid pattern keys in chart signifies that touching key will not affect note selection. EVI key values; EVI/EVR fingering chart; Aside from these core fingerings, the trill keys producing +1,+2 and +4 semitones will allow you to create faster fingerings around the octave break. Experiment to find what works for you.

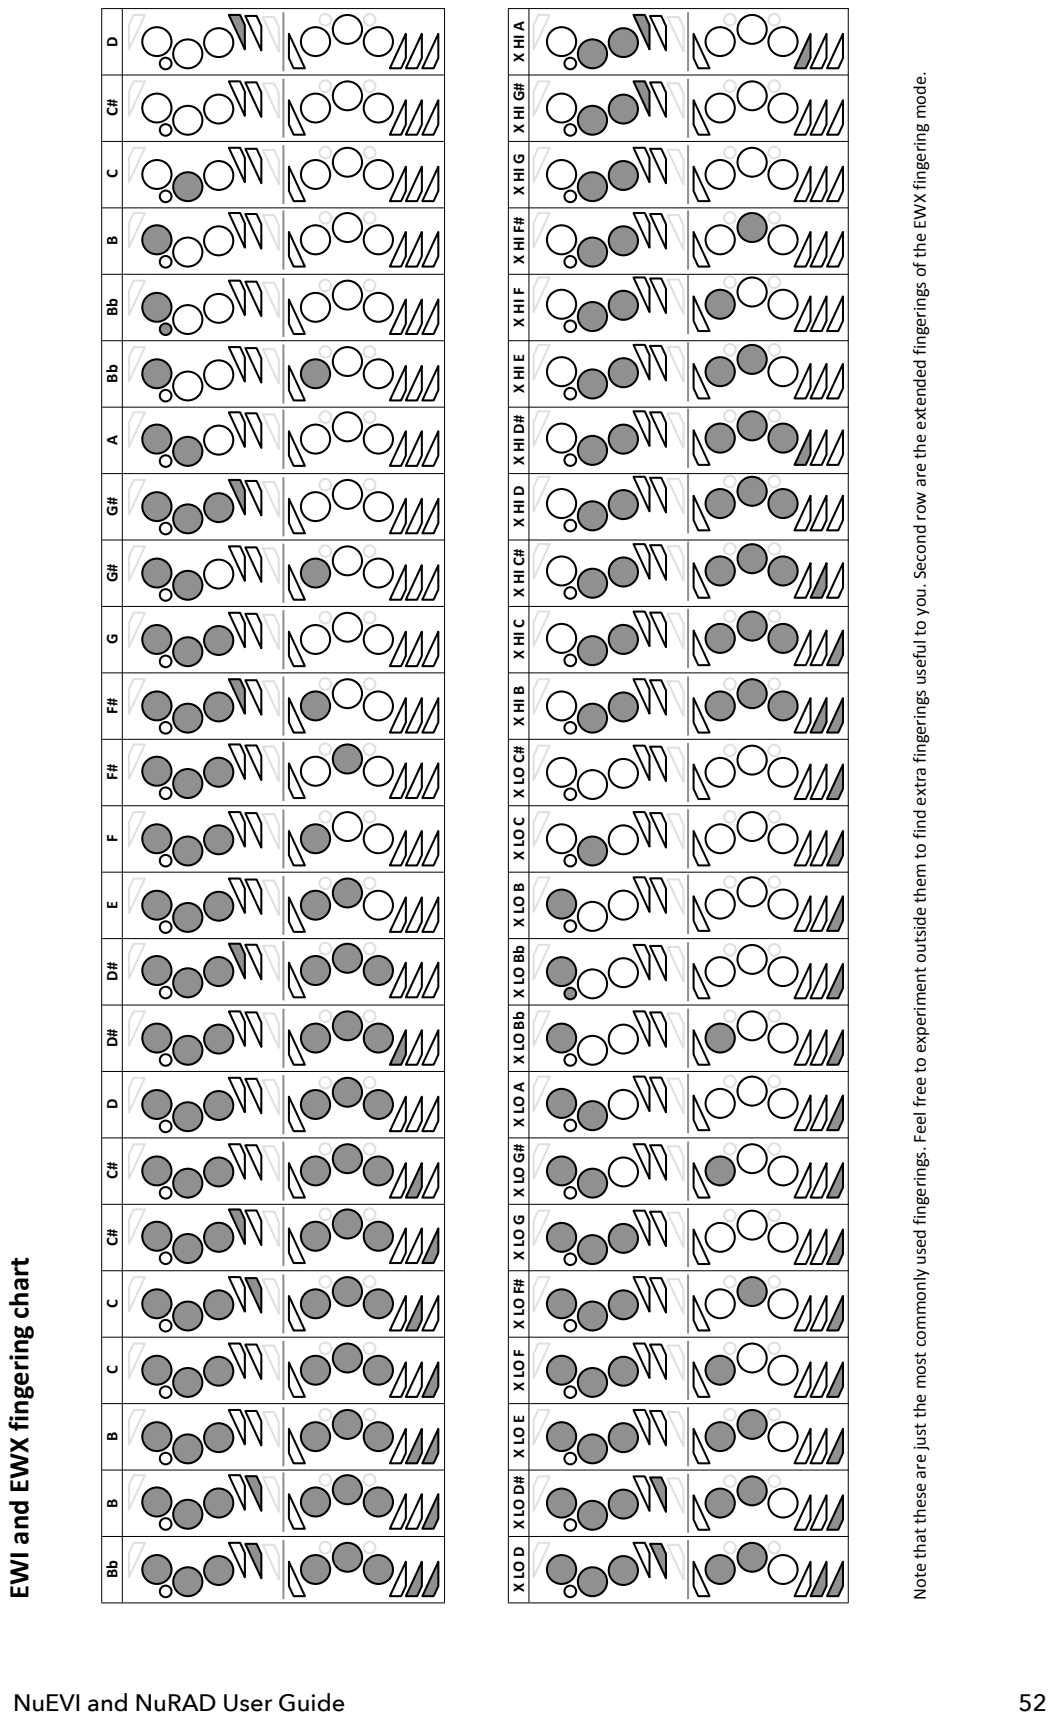
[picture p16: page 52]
NuEVI and NuRAD User Guide; 52 EWI and EWX fingering chart; Note that these are just the most commonly used fingerings. Feel free to experiment outside them to find extra fingerings useful to you. Second row are the extended fingerings of the EWX fingering mode.

## Fingering chart (NuEVI)

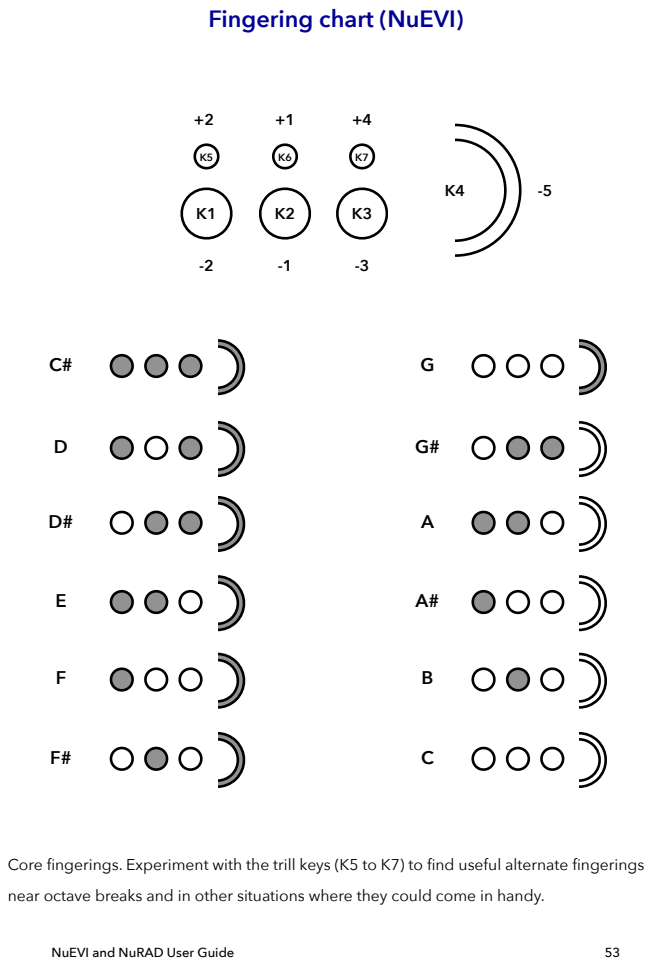
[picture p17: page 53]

Core fingerings. Experiment with the trill keys (K5 to K7) to find useful alternate fingerings
near octave breaks and in other situations where they could come in handy.

## Wireless MIDI (option)

The built-in wireless MIDI system that comes as an option for the NuRAD and NuEVI is the PandaMidi midiBeam. Just power the receiver using USB (from computer or standard USB charger) and switch the NuRAD on to get that link up (steady glowing LEDs on transmitter and receiver). MIDI is output both to the USB port (when connected to computer or tablet) and to the MIDI OUT DIN jack on the receiver box.

For NuRAD, if your mouthpiece protector has a little magnet on the top, the wireless card has been modded to feature a reed switch for pairing. To set the wireless to pairing mode, swipe the magnet over the position of the wireless card in the NuRAD (blinking red LED under LH keys) to make the LED blink faster, indicating pairing mode. Otherwise, if pairing should be needed, the top is easily opened using the back most thumb screw (press down onto top near the screw to relieve tension onto the screw and it will be easier). For NuEVI, to press the button on the transmitter, loosen the mid top screw a bit and then unscrew the back top screw. Tilt the lid up a bit and reach in with a finger to press the button on the receiver. The receiver is positioned at the back of the NuEVI, to the right seen from mouthpiece end.

## Troubleshooting tips

Problem: Intermittent small pitch bend messages are sent, especially when blowing into the mouthpiece.

Solution: The vibrato squelch is set too tight. Up the settings value a step or two. Also check pitch bend adjustment settings and make sure the idle sensor readings are not above THR line.

—

Problem: When using the optional wireless kit, some keys don’t respond properly.

Solution: With the handle loop removed and no natural ground through a cable, the lesser amount of reference grounding may be affecting the capacitive touch readings. Make sure you keep your thumb on the thumb lever and the metal strip on the roller assembly (both are ground points) while playing wirelessly, for better touch response. On NuEVI ground points are thumb lever and canister (bottom or grounding square). Also check the touch sense adjustments, and maybe try bringing the THR bar closer to the cluster of dots. You can use the touch sensor dots to monitor the touch response of each key and roller, to see how they respond with and without grounding.

—

Problem: I’m getting dropouts and hung notes when playing, or it stops sending MIDI completely.

Solution: Check your battery level and make sure you have fresh batteries.

—

Problem: When using wireless MIDI, the patches start randomly changing or notes get dropped. Or connection is lost, with the receiver LED blinking.

Solution: Batteries are getting low and not providing enough current for the transmission bursts. This can happen before LOW BAT is indicated for some battery types. Switch to fresh good quality batteries. Try re-pairing the MidiBeam set to find a channel with less interference. To enter pairing mode on the NuRAD, swipe a magnet over the area where the red MidiBeam LED is seen. On NuEVI, open the top just enough to reach the blue pairing button on the MidiBeam transmitter.

—

Problem: Bite vibrato or portamento stopped working since last time, and I didn’t do anything!

Solution: Ambient air pressure has probably changed since, shifting the bite sensor input out of range. Press the little valve button under the bite sensor tube where it enters the housing to equalize the pressure. It’s a good idea to do this before every playing session, just to make sure it’s right.

—

Problem: Using CV on NuEVI Plus, NuEVI CV or standard NuEVI or NuRAD with CV Box or module, both CV jacks send breath CV.

Solution: Check DAC MODE setting in EXTRAS menu. It should be set to PTCH, not BRTH.

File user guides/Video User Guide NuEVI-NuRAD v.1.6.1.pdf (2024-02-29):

# Video User Guide

## NuEVI and NuRAD

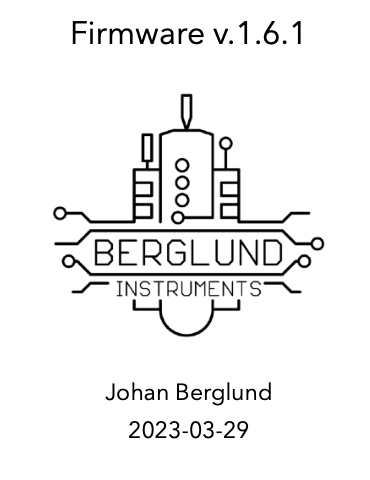
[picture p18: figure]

We recommend watching the Video User Guide (https://youtu.be/6Dkjk3b4stY&t=00) and following along with your instrument. It will help familiarize you with the menu and controls of the NuEVI and NuRAD; and give you insight into the many features and possibilities.

The entire video is about an hour and twenty minutes; You will find timestamps for each chapter in the video description.
(You may view it a chapter or two at a time.)

You can search specific topics by clicking the subjects in the menu below and going directly to that topic in the Video User Guide. (https://youtu.be/6Dkjk3b4stY&t=00)

Video Manual Written by Johan Berglund

Video Produced by Curt Sipe

NuEVI and NuRAD User Guide | 1

## Origins (https://youtu.be/6Dkjk3b4stY&t=00) Table of Content / Instrument Overview (https://youtu.be/6Dkjk3b4stY&t=250s) Holding and Controls (https://youtu.be/6Dkjk3b4stY&t=275s)

Roller Technique (https://youtu.be/6Dkjk3b4stY&t=287s)
NuEVI Playing Position (https://youtu.be/6Dkjk3b4stY&t=309s)
NuRAD / Handles or Neck Strap (https://youtu.be/6Dkjk3b4stY&t=384s) Mouthpiece Sensors (https://youtu.be/6Dkjk3b4stY&t=451s)
Pneubite System (https://youtu.be/6Dkjk3b4stY&t=508s)
NuEVI Controls Top & Bottom (https://youtu.be/6Dkjk3b4stY&t=585s) NuRAD Controls Top & Bottom (https://youtu.be/6Dkjk3b4stY&t=705s)

## Connections (https://youtu.be/6Dkjk3b4stY&t=758s)

Synthesizers and Computer (https://youtu.be/6Dkjk3b4stY&t=757s)
Analog Synthesizers
NuRAD (https://youtu.be/6Dkjk3b4stY&t=843s)
NuEVI (https://youtu.be/6Dkjk3b4stY&t=868s)

## Power (https://youtu.be/6Dkjk3b4stY&t=891s)

AAA & AA Battery Replacement (https://youtu.be/6Dkjk3b4stY&t=968s) Lip System (https://youtu.be/6Dkjk3b4stY&t=1012s)
LP1 System and Switch (https://youtu.be/6Dkjk3b4stY&t=1058s)
LP2 System and Switch (https://youtu.be/6Dkjk3b4stY&t=1114s)
AAA & AA System and Switch (https://youtu.be/6Dkjk3b4stY&t=1160s)

## Settings / OLED Display (https://youtu.be/6Dkjk3b4stY&t=1170s)

TRANSPOSE (https://youtu.be/6Dkjk3b4stY&t=1241s)
OCTAVE (https://youtu.be/6Dkjk3b4stY&t=1251s)

MIDI CHANNEL (https://youtu.be/6Dkjk3b4stY&t=1262s)

## POLY PLAY (https://youtu.be/6Dkjk3b4stY&t=1273s)

POLY MODE SETTINGS (https://youtu.be/6Dkjk3b4stY&t=1299s)
HMZ KEY (https://youtu.be/6Dkjk3b4stY&t=1374s)
OTF KEY (https://youtu.be/6Dkjk3b4stY&t=1383s)
HMZ LIMIT (https://youtu.be/6Dkjk3b4stY&t=1403s)
FWC TYPE (https://youtu.be/6Dkjk3b4stY&t=1418s)
FWC LOCKH (https://youtu.be/6Dkjk3b4stY&t=1428s)
FWC DROP2 (https://youtu.be/6Dkjk3b4stY&t=1441s)
PRIORITY (https://youtu.be/6Dkjk3b4stY&t=1454s)
ROTATOR A, ROTATOR B, ROTATOR C (https://youtu.be/6Dkjk3b4stY&t=1477s)

## SETUP BR (https://youtu.be/6Dkjk3b4stY&t=1544s)

BRTH CC A (https://youtu.be/6Dkjk3b4stY&t=1546s)
BRTH CC B (https://youtu.be/6Dkjk3b4stY&t=1677s)
CC B RISE (https://youtu.be/6Dkjk3b4stY&t=1694s)
BREATH AT (https://youtu.be/6Dkjk3b4stY&t=1727s)
VELOCITY (https://youtu.be/6Dkjk3b4stY&t=1745s)
CURVE (https://youtu.be/6Dkjk3b4stY&t=1769s)
VEL DELAY (https://youtu.be/6Dkjk3b4stY&t=1813s)
VEL BOOST (https://youtu.be/6Dkjk3b4stY&t=1876s)
BR INTERV (https://youtu.be/6Dkjk3b4stY&t=1903s)

## SETUP CTR (https://youtu.be/6Dkjk3b4stY&t=1925s)

BITE CTL (https://youtu.be/6Dkjk3b4stY&t=1931s)
BITE CC (https://youtu.be/6Dkjk3b4stY&t=1958s)
LEVER CTL (https://youtu.be/6Dkjk3b4stY&t=1968s)

LEVER CC (https://youtu.be/6Dkjk3b4stY&t=1994s)
GLIDE MOD (https://youtu.be/6Dkjk3b4stY&t=2005s)
GLIDE MAX (https://youtu.be/6Dkjk3b4stY&t=2047s)
GLIDE MIN (https://youtu.be/6Dkjk3b4stY&t=2061s)

## SET UP CTR - VIBRATO (https://youtu.be/6Dkjk3b4stY&t=2070s)

DEPTH (https://youtu.be/6Dkjk3b4stY&t=2076s)
RETURN (https://youtu.be/6Dkjk3b4stY&t=2108s)
DIRECTION (https://youtu.be/6Dkjk3b4stY&t=2138s)
SENSE LVR (https://youtu.be/6Dkjk3b4stY&t=2166s)
SQUELCH L (https://youtu.be/6Dkjk3b4stY&t=2188s)
SENSE BTE (https://youtu.be/6Dkjk3b4stY&t=2234s)
SQUELCH B (https://youtu.be/6Dkjk3b4stY&t=2254s)
EXCT CC A (https://youtu.be/6Dkjk3b4stY&t=2296s)
EXCT CC B (https://youtu.be/6Dkjk3b4stY&t=2342s)
EXCT HARM (https://youtu.be/6Dkjk3b4stY&t=2362s)
HARM SEL (https://youtu.be/6Dkjk3b4stY&t=2384s)
DEGLITCH (https://youtu.be/6Dkjk3b4stY&t=2435s)
MOD KEY / PINKY KEY (https://youtu.be/6Dkjk3b4stY&t=2467s)
LEVEL CC (https://youtu.be/6Dkjk3b4stY&t=2602s)
EXTRA PINKY KEY (NuRAD Only) (https://youtu.be/6Dkjk3b4stY&t=2616s) FINGERINGS (NuRAD) (https://youtu.be/6Dkjk3b4stY&t=2653s)
FINGERING (NuEVI) (https://youtu.be/6Dkjk3b4stY&t=2708s)
ROLLRMODE (https://youtu.be/6Dkjk3b4stY&t=2744s)
PITCH BEND (https://youtu.be/6Dkjk3b4stY&t=2774s)

## ADJUST (https://youtu.be/6Dkjk3b4stY&t=2824s)

BREATH (https://youtu.be/6Dkjk3b4stY&t=2900s)
LEVER (https://youtu.be/6Dkjk3b4stY&t=2938s)

TOUCH (https://youtu.be/6Dkjk3b4stY&t=2970s)
LIP / EC (https://youtu.be/6Dkjk3b4stY&t=2994s)
BEND (https://youtu.be/6Dkjk3b4stY&t=3027s)
BITE (https://youtu.be/6Dkjk3b4stY&t=3070s)

## EXTRAS

LEGACY PB (https://youtu.be/6Dkjk3b4stY&t=3153s)
LEGACY BR (https://youtu.be/6Dkjk3b4stY&t=3165s)
GATE HOLD (https://youtu.be/6Dkjk3b4stY&t=3175s)
3rd TRILL (https://youtu.be/6Dkjk3b4stY&t=3189s) (NuEVI)
BCAS MODE (https://youtu.be/6Dkjk3b4stY&t=3222s)
DAC OUT (https://youtu.be/6Dkjk3b4stY&t=3237s)
BAT TYPE (https://youtu.be/6Dkjk3b4stY&t=3266s)
FAST BOOT (https://youtu.be/6Dkjk3b4stY&t=3315s)
FAST PATCH (https://youtu.be/6Dkjk3b4stY&t=3322s)
CV TUNE (https://youtu.be/6Dkjk3b4stY&t=3333s)
CV SCALE (https://youtu.be/6Dkjk3b4stY&t=3355s)
CV EC LFO (https://youtu.be/6Dkjk3b4stY&t=3376s)
WL POWER (https://youtu.be/6Dkjk3b4stY&t=3406s)
WL CHANNEL (https://youtu.be/6Dkjk3b4stY&t=3443s)

Patch Selection (https://youtu.be/6Dkjk3b4stY&t=3490s) FastPatch Selection (https://youtu.be/6Dkjk3b4stY&t=3527s) ALL NOTES OFF (https://youtu.be/6Dkjk3b4stY&t=3624s) Special Key (https://youtu.be/6Dkjk3b4stY&t=3644s) Gate Hold (https://youtu.be/6Dkjk3b4stY&t=3844s) Legacy Instant Controls (https://youtu.be/6Dkjk3b4stY&t=3912s)

Nyle’s Program Button Functions (https://youtu.be/6Dkjk3b4stY&t=4079s) Pitch Bend Pad Adjustment (https://youtu.be/6Dkjk3b4stY&t=4242s) Pinky Key Adjustment (NuRAD) (https://youtu.be/6Dkjk3b4stY&t=4268s) Battery Check (https://youtu.be/6Dkjk3b4stY&t=4307s) Battery Replacement (AAA and AA) (https://youtu.be/6Dkjk3b4stY&t=4374s) Firmware Updates (https://youtu.be/6Dkjk3b4stY&t=4415s) Factory Restore (https://youtu.be/6Dkjk3b4stY&t=4520s) Fingering Charts (https://youtu.be/6Dkjk3b4stY&t=4566s) Troubleshooting Tips (https://youtu.be/6Dkjk3b4stY&t=4573s) www.curtsipe.com

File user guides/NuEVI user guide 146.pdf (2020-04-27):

# NuEVI

# user guide

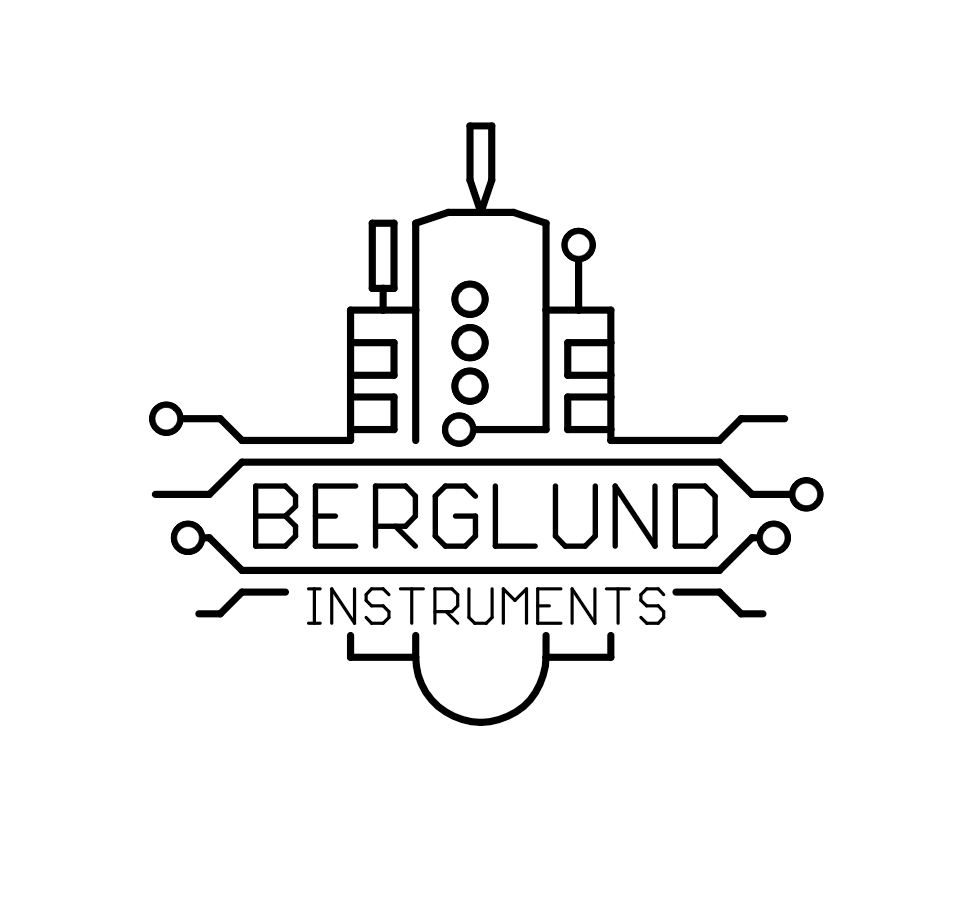
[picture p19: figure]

Firmware version 1.4.6
Johan Berglund 2020

Short history

The Electronic Valve Instrument was invented back in the early 1970s by Nyle Steiner. The first production instruments were using mechanical switches in a handset connected to an analog synthesizer module, and they were sold from 1975 to 1979 by the Steiner-Parker company. When the company had dissolved, the instrument was produced by Crumar.

In the mid 80s, Steiner designed and built a number of instruments with a more complex synthesizer and touch sensing for the keys. They were referred to as Steinerphones, and and came in both brass and woodwind variety.

In 1987 a new type of EVI was licensed and sold by AKAI. This new version together with its woodwind counterpart released at the same time, the EWI, was using touch sensing for the finger controls and a programmable synth module capable of sending MIDI for controlling other synthesizers. The Akai EVI was discontinued due to not selling as well as the EWI that is still made by AKAI in new incarnations.

For a while Nyle Steiner did conversions of then current model EWIs into EVIs, until in 1998 when he started building and selling the MIDI EVI he had developed. The MIDI EVI was built to work as a controller for MIDI equipped synthesizers, with no sound synthesis capability of its own. For several years this has been the controller/instrument of choice for EVI players, even when the newer EWIs got alternative EVI fingering settings.

In recent years the MIDI EVI has become hard to come by. Steiner has moved on to many other projects and interests, and so very few new EVIs are being built. In 2012 he posted a YouTube video demonstrating a prototype for an Arduino based EVI that people could build themselves. In 2017 it was still unclear when the Arduino EVI kit would be available. As the only available EVI would be in kit form and not available as a pre-built instrument, some EVI players started to get a bit concerned about the future of the EVI. With no new instruments being built, the EVI would eventually die. In hope to prevent this, EVI virtuoso Steve Anderson initiated a project aiming to create a new EVI.

Overview

The NuEVI is a valve instrument MIDI wind controller heavily based on Nyle Steiner’s MIDI EVI. While as far as possible being true to the playing aspects of the original, efforts have been made to take it further when it comes to ease of adjustment and setup. It is also able to send MIDI over USB, in addition to the standard DIN MIDI, making it easier to use with computers and tablets.

Controls

The mouthpiece has three sensors. The primary one is the breath pressure sensor. It controls note on/off and the continuos control value for breath sent to the synthesizer. The breath sensor system is of the closed kind. That means no air is flowing through the instrument when it is played. Instead you let air slip out by the sides of the mouthpiece when blowing into it. The second mouthpiece sensor is the bite sensor. This controls portamento (glide). A slight bite or bend to the mouthpiece will increase the glide time. When released, it goes back to zero/no glide. Third, there’s the extra controller sensor on top of the mouthpiece. This is a lip sensor that is touch sensitive and it can be set to control modulation, growl or sustain (hold).

The right hand has controls both on top of the instrument and on the bottom. Topside, there are three main valves (-2, -1 and -3 semitones), three trill keys (+2, +1 and +4 semitones), a ”special key” between two of the trill keys for chord and interval functions, and a 1/2 pitch bend key that will set pitch bend and vibrato values sent to 50% when held (can be configured to act as an adjustable trill key/transposition key instead). The keys are all activated by touch. On the bottom there are two touch sensitive pitch bend plates, behind and in front of the thumb. They are proportional and send pitch bend up and down in response to how much you let your thumb press against them. Between the pitch bend pads, there is a vibrato lever. This also sends pitch bend control to your synthesizer, but in a manner focused on vibrato. The lever senses position change. A forward movement triggers a slight pitch bend down followed by a return to zero when the movement stops. The movement back will then trigger a slight pitch bend up, followed by return to zero when movement stops. This creates a very violin like vibrato in a way that will feel natural to the player. A slight shaking hand motion back and forth with your thumb kept on the lever will produce this.

Left hand controls octaves and the fourth valve (perfect fifth, -5 semitones). Octaves are controlled using the thumb rollers. Let your thumb rest between two rollers. Rotate your hand while holding the canister and let your thumb move along the arc of rollers to change octaves. Octaves go from -3 (thumb left of leftmost roller, not touching it), to -2 (touching only the leftmost roller), -1 (between the first two rollers) and all the way up to +3 (between the two last rollers). Your index finger controls the fourth valve (-5 semitones), aka the side key. It is the arc in the front of the instrument, just above the canister.

Settings

To simplify configuration, the NuEVI has been equipped with an OLED display and four navigation buttons. The middle buttons are MENU/BACK (left) and ENTER (right), and the buttons above and below are the buttons for UP and DOWN selection. When not used for configuration or patch viewing, the display will be shut off to conserve power. Pressing MENU will activate the display and the main menu. A flashing cursor will indicate items, and ENTER will select the indicated item. Menu items directly controlling a setting will trigger a square being shown on the right in the display, with the adjustable value flashing inside it. Press UP and DOWN to select the desired value and then press ENTER or MENU to select that value and store it in non-volatile memory. The controller will remember this setting even if it is switched off. To make a temporary change that will not be stored, leave the menu open with the value flashing. After a while, the menu will shut off and the setting will not be stored.

TRANSPOSE

This menu item allows you to transpose the instrument up or down 12 semitones. Factory default transposition is C, +0 semitones.

OCTAVE

This menu item changes the octave transposition of the instrument. Values go from -3 to + 3, with +0 as factory default.

MIDI CH

This menu item selects the active MIDI channel, 1 through 16, for both DIN MIDI and USB MIDI. Factory default is MIDI channel 1.

If your synth can’t keep up with the density of breath CC from the NuEVI, you can reduce the density of those MIDI signals by touching the pinky key when pressing ENTER here. An ”S” in the lower right corner will indicate that this slower mode is activated.

ADJUST

Selecting this menu item enters the sensor adjustment screen. Here you can monitor sensor reading values and change the threshold and maximum (sensitivity) values for the sensors. Scroll through the various sensors using UP and DOWN buttons and press ENTER to move the cursor to THR and MAX items, where UP and DOWN buttons increase and decrease the values (the indicator bar for the setting is moved right or left). Note that the MAX setting can never be set lower than the THR setting. A moving pixel (SNS) indicates the current sensor reading. Where several sensors are involved, a pixel for each sensor will be shown. Also note that the intensive updating of the OLED display while using the SETUP menu will interfere with the transmission of MIDI CC data. For that reason, the ADJUST menu is to be used for setup only, not to be activated during normal play.

ADJUST - BREATH

THR level sets the amount of pressure needed to trigger a note and start sending breath MIDI data. The breath indicator LED will light up when pressure is over threshold. If the LED is always lit, even when you are not blowing into the mouthpiece, you need to raise the THR setting until the LED turns off.

MAX sets the pressure level that should correspond to full signal output. This setting is of course to your individual preference, and with different settings of the breath to signal transfer curve (SETUP BR - CURVE) you may want to adjust this too.

ADJUST - BITE

THR level sets the amount of bite or bend action on the mouthpiece needed to start sending portamento control data. The portamento indicator LED will light up when bite input is over threshold. If the LED is always lit, even when you are not biting or bending the mouthpiece, you need to raise the THR setting until the LED turns off.

MAX sets the bite or bending level corresponding to full portamento signal output.

On NuEVI plus model or special models with the pneumatic bite sensor, press the valve to equalize pressure, then set THR two or three millimeters higher than idle reading to compensate for thermal expansion of the air in the system when played.

ADJUST - PITCH BEND

THR sets the threshold for the pitch bend touch pads. Make sure both of the SNS indicator dots are to the left of the THR line, or you will have issues with your pitch bend signal.

MAX sets the amount of finger pressure against pitch bend touch pads required for full signal output. When adjusting this setting, move your thumb up and down onto the pads to find a good setting. Note that what should be sent as full pitch bend signal is controlled in the SETUP CTR - PITCH BEND menu. The sensor MAX setting should always be set so the SNS reading is reaching the MAX line when the pads are fully touched.

ADJUST - EXTRA CTR

The extra controller, activated in the SETUP CTR menu, is the lip or embouchure sensor on top of the mouthpiece. It is a proportional touch controller, working much in the same fashion as the pitch bend pads.

THR sets the threshold for the lip touch sensor. Make sure the SNS indicator dot is to the left of the THR line when sensor is not touched.

MAX sets the lip touch corresponding to full controller signal output.

ADJUST - TOUCH

THR sets the threshold for the main keys (K1 through K7) and the octave rollers. When all keys and rollers are untouched, the SNS dots should all be to the right of the THR line. Keys touched one at a time, one of the dots should go left of the THR line. This both verifies connectivity and correctly set THR level.

SETUP BR

Submenu for settings related to breath control.

SETUP BR - BRTH CC A

Sets the MIDI CC to be sent to represent the breath data.

OFF – No breath CC data is sent.
MW – Breath data is sent as CC#1 (Mod Wheel)
BR – Breath data is sent as CC#2 (Breath, factory default)
VL – Breath data is sent as CC#7 (Volume)
EX – Breath data is sent as CC#11 (Expression)
MW+ – High resolution breath data is sent on CC#1 and CC#33 (Hi-res Mod Wheel)* BR+ – High resolution breath data is sent on CC#2 and CC#34 (Hi-res Breath)*
VL+ – High resolution breath data is sent on CC#7 and CC#39 (Hi-res Volume)* EX+ – High resolution breath data is sent on CC#11 and CC#43 (Hi-res Expression)* CF – Breath data is sent as CC#74 (Filter Cutoff)
UNO – Breath data is sent as CC#20 (for use with IK Multimedia UNO Synth)

*) Hi-res MIDI is very often not supported in the receiving end, i.e. synths or DAWs. It also uses more MIDI bandwidth. In most cases you are better off with the regular CC signal. In cases where smoothing is not implemented in the receiving end, Hi-res CC can be a way to get less stepping in the filter control. As an example, the Minibrute gets stepping in the sound when the filter cutoff is controlled with Aftertouch, but a smooth sound when the filter is controlled by high resolution Modulation Wheel data.

SETUP BR – BRTH CC B

Secondary MIDI CC for breath data. Can be set to any CC between 1 and 127 and be used together with CC A or on its own with CC A set to OFF.

SETUP BR – CC B RISE

Multiplier to faster reach top value for CC A compared to CC B. For example if you want to control amplifier (VCA) value with CC B and have it reach full value at 25% of full breath, while CC A controls filter (VCF) cutoff in normal fashion, set the CC B RISE to 4x.

1x – 10x in steps of one.

SETUP BR - BREATH AT

Controls wether or not breath data should be sent as Aftertouch (Channel Pressure).

OFF - No Aftertouch breath data is sent (factory default)
ON - Breath data is sent as Aftertouch.

SETUP BR - VELOCITY

Note velocity can be set to follow the initial breath value dynamically (DYN) or to a fixed value (1 to 127). When fixed value is used, the velocity sample delay is also bypassed for optimal timing of note on vs rising breath signal.

SETUP BR - CURVE

This sets the breath sensor to control signal transfer curve. See curve diagram for a graphical representation of each curve.

-4 to -1 curves are more responsive (faster rising) in the low pressure end.
+1 to +4 curves are more responsive (faster rising) in the high pressure end.
LIN is a straight linear signal transfer.
S curves have a faster transition in the middle and is less responsive in the low and high pressure ends.
Z curves have a slower transition in the middle and is more responsive in the low and high pressure ends.

The LIN curve is factory default.

SETUP BR - VEL DELAY

The time it takes for a tongued note to reach its attack peak is generally about 20ms. Normally, that’s the amount of time the NuEVI waits until it samples the breath pressure level to set the note velocity. However, there are situations where we would want to adjust that delay. For example, if we are using a high THR value for the breath sensor, some of the rising time will occur before the THR is reached and the delay time starts. Also, if the connected synthesizer is not responding to velocity, setting the delay shorter will increase the response time. Even if the synth responds to velocity, you can experiment with cutting down the delay time and compensating for lower velocity values with the VEL BIAS setting. The value number is arbitrary, and 20ms is generally at setting 15.

OFF – No velocity sample delay.
1 – Lowest delay setting
2
3
15 (factory default)
30 – Highest delay setting

SETUP BR - VEL BOOST

This setting helps boosting velocity values. Useful for compensating short velocity sample delay settings and for situations where you want to reach high velocity levels faster in relation to breath level.

OFF – Velocity bias disabled (factory default)
1 – Lowest setting
9 – Highest setting

SETUP CTR

Submenu for settings related to controllers in general.

SETUP CTR - PORT/GLIDE

Settings for the portamento/glide function (controlled by the bite sensor).

OFF – No portamento CC data is sent.
ON – Portamento Time (CC#5) is sent.
SW – Portamento Time (CC#5) and Portamento Switch (CC#65) is sent. (factory default)

SETUP CTR – EXCT CC A

The extra controller can be disabled or set to control transmission of selected MIDI CC data.

OFF – extra controller is disabled.
MW – Modulation Wheel (CC#1) data is sent. Disabled if breath data is sent over CC#1. FP – Foot Pedal (CC#4) data is sent. Growl on some wind synth patches. (factory default) CF – Filter Cutoff (CC#74) data is sent.

SP – Sustain pedal (CC#64). Holds fingered notes until controller is released.

SETUP CTR – EXCT CC B

Secondary CC value to be sent with extra controller. Can be sent together with main CC for extra controller, or switched using pinky key (see pinky key settings). Values from 1 to 127. Default OFF.

SETUP CTR – EXCT HARM

To use the lip sensor extra controller for going through the harmonic series, set this to the range you want. A larger range makes it harder to control, as the touch sensitivity of the lip sensor is divided into the number of steps added. Values from 1 to 60. Default OFF.

SETUP CTR – HARM SEL

As default, the lip sensor harmonics are set up to use the natural harmonic series (omitting the first ”pedal” note), so for a C, it would go up G, C, E, G, Bb and C. This is the HMS setting. Alternative settings are 5TH (going up fifths and octaves), OCT (going up octaves), 5DN (going down fifths and octaves) and ODN (going down octaves).

SETUP CTR - VIBRATO

Menu for vibrato settings.

SETUP CTR - VIBRATO - CONTROL

This setting selects the controller to use for vibrato. Default it is set to use the thumb lever (LVR). Switching to bite sensor (BIT) will also move the portamento control to the thumb lever. They can both be controlling vibrato at the same time (BTH), in which case none of them controls portamento.

SETUP CTR - VIBRATO - DEPTH

This setting controls the vibrato depth.

OFF – Vibrato lever disabled.
1 – Lowest vibrato depth setting
9 – Highest vibrato depth setting

The factory default setting is 4.

Vibrato depth is also depending on the vibrato sensitivity setting. After fine tuning the sensitivity for a smooth vibrato response, you may want to revisit the depth setting.

SETUP CTR - VIBRATO - RETURN

This setting lets you adjust the speed of the automatic return to zero for the vibrato.

Values go from 0 to 4, where 4 is the fastest return and 0 is no automatic return, i.e. the vibrato lever will work as a conventional pitch stick. Normal EVI behaviour is auto return, and the default setting is 2.

SETUP CTR - VIBRATO - DIRECTION

This setting lets you set the direction of the vibrato. For most people this should be kept to the default setting NRM (normal), where the pitch will fall in response to thumb movement in direction away from the mouthpiece, or rise in response to bite when CONTROL is set to use the bite sensor.

SETUP CTR - VIBRATO – SENSE LVR

This setting controls vibrato lever sensitivity. As individual vibrato sensors may vary in values a bit, this setting will help adjusting the sensitivity to get the best result.

Setting values go from 1 to 12, where 12 is the most sensitive.

SETUP CTR - VIBRATO – SQUELCH L

This setting helps eliminate pitchbend MIDI chatter for when vibrato is not touched and idle. Setting it too high makes the vibrato lever require an unnecessary amount of movement before initiating vibrato, and with the setting too low the natural sensor noise will cause MIDI chatter around zero. To find the right setting, use a MIDI monitor software on your computer or other device. It should not be showing pitch bend activity when idle, yet be set close enough to this limit to allow good sensitivity when lever is touched slightly. When you are pleased with the setting, press ENTER or MENU to save it.

Setting values go from 1 to 30, where 12 is the factory default.

SETUP CTR - VIBRATO – SENSE BTE

This setting controls vibrato sensitivity. As individual vibrato sensors may vary in values a bit, this setting will help adjusting the sensitivity to get the best result.

Setting values go from 1 to 12, where 12 is the most sensitive.

SETUP CTR - VIBRATO – SQUELCH B

This setting helps eliminate pitchbend MIDI chatter for when bite vibrato is not touched and idle. Setting it too high makes the bite sensor require an unnecessary amount of movement before initiating vibrato, and with the setting too low the natural sensor noise will cause MIDI chatter around zero. To find the right setting, use a MIDI monitor software on your computer or other device. It should not be showing pitch bend activity when idle. When you are pleased with the setting, press ENTER or MENU to save it.

Setting values go from 1 to 30, where 10 is the factory default.

SETUP CTR - DEGLITCH

To reduce glitching when fingerings are changed, the deglitching function waits some milliseconds before considering a fingering “done” and settled. Beginners will probably feel the need to increase the deglitch setting, while virtuoso players could feel the need to reduce the setting.

OFF – Deglitching disabled
1 ms – Lowest deglitch setting
2 ms
20 ms (factory default)
70 ms – Highest deglitch setting

SETUP CTR – PINKY KEY

The standard and legacy behaviour of the pinky key is to set the pitch bend signal to half its value while the key is pressed. In the NuEVI, we have added the possibility to instead use the pinky key for instant transposition, or an adjustable trill key if you like.

- 12 – transpose one octave down when pinky key is held
- 1 – transpose one semitone down when pinky key is held
PBD – Pitch Bend Divide, PB and vibrato level is half value when pinky key is held +1 – transpose one semitone up when pinky key is held
+ 12 – transpose one octave up when pinky key is held
EC2 – send on/off (0/127) for CC set in Extra Controller CC2 setting
ECS – switch between main and secondary CC to be sent using Extra Controller LVL – Level control using pinky key. Change level with first and second trill keys.
LVP – Like above but current level is transmitted on power up.
GLD – Momentarily sends the the set level amount as static glide/portamento level.

When setting LVL/LVP or GLD level, the breath and glide LEDs crossfade between them to indicate setting. All breath LED is 127 (max) and all glide LED is 0 (min).

PBD is factory default pinky key setting, as it is the legacy function of this key.

SETUP CTR – LEVEL CC

CC to be sent using pinky key level controls LVL and LVP. 1 to 127, default OFF.

SETUP CTR - PITCH BEND

The pitch bend signal can be divided to work with synthesizers that are not able to set the pitch bend range low enough to fit this kind of instrument. As an example, if a synth has a set pitch bend range of 12 semitones up and down, setting the pitch bend divider to 1/12 will limit the range to just a semitone up and down. The OFF setting will disable the pitch bend pads. Vibrato depth follows the pitch bend divider setting. If the pitch bend pads are disabled, the vibrato will still work at 1/1 range.

OFF – No pitch bend data is sent.
1/1 – Full pitch bend range. (factory default)
1/2 – Half pitch bend range.
1/12 - A twelfth of the pitch bend range.

ROTATOR

Menu for setting the intervals of the rotator function. See separate section.

EXTRAS

Various settings.

EXTRAS – LEGACY PB

ON/OFF switching for the legacy instant controls where both pitch benders are used. (See Legacy Controls section).

EXTRAS – LEGACY BR

ON/OFF switching for the legacy instant controls where negative breath is used. (See Legacy Controls section).

EXTRAS – GATE HOLD

Setting to disable the Gate Hold functionality to avoid accidental activation.

EXTRAS – SPEC KEY

Setting to disable the Special Key functionality to avoid accidental activation.

EXTRAS – 3RD TRILL

This setting controls the behaviour of the 3rd trill key. Available options are +3 or +4 (default) semitones. As a hidden extra, the interval that is not selected here can be achieved by touching third valve key and third trill key at the same time. A mechanical mod making this practical is to mount a metal lip onto the trill key, making it protrude just above and behind the third valve key.

EXTRAS – BCAS MODE

This setting changes the behaviour of the legacy instant controls, to not require touching pitch bend up for patch change. Only has effect when LEGACY BR is ON.

EXTRAS – DAC MODE

This setting controls the DAC output channel. The available options are
BRTH - Output the breath sensor signal.
PTCH - Output note pitch (v/Oct). In this case, the breath signal will be output as a PWM signal on pin 20.

For NuEVI Plus, NuEVI CV or standard NuEVI with NuEVI CV Box, the PTCH option should be selected.

EXTRAS – BAT TYPE

To have the battery voltage monitoring correctly representing the battery type used in the controller, use the corresponding setting.

ALK – Alkaline batteries (100% at 4.6V, LOW BAT at 3.8V)
NMH – NiMH rechargable batteries (100% at 3.9V, LOW BAT at 3.6V)
LIP – LiPo rechargable battery (100% at 4.3V, LOW BAT at 3.7V)

At the time of writing LiPo power is not availabe yet for the NuEVI.

EXTRAS – FAST BOOT

Enabling this setting will make the NuEVI start up as fast as possible when powered on. Note that this will also make some of the sensor calibration routines less precise, and should only be used when you need to be able to restart quickly.

EXTRAS – WL POWER

To set the radio power of the optional midiBeam wireless kit, select a value in this menu and press enter. This should be done with the wireless receiver linked up (steady glowing LEDs on TX and RX). The available values are 0, -6, -12 and -18 dBm. 0 is the highest setting, and is the default setting in the midiBeam. NuEVI does not store the setting (it is only kept in the midiBeam) so the menu will always start on 0 when selected.

EXTRAS – WL CHANNEL

To set the radio channel of the midiBeam wireless transmitter, select a value in this menu and press enter. Available values are 4-80. After changing this, the transmitter and receiver will need to be paired again as the connection will be lost. Note that this is just an “initial channel” that the midiBeam will use, during pairing it will determine what the best channel is. The value is also not stored by NuEVI, so the menu will always start at 4 (the default midiBeam channel).

Before changing any of the wireless settings, please read through the midiBeam user guide describing these settings. This is available at http://pandamidi.com/support.

Patch selection

Pressing the ENTER button when the display is off will show the currently selected patch number on the display for a couple of seconds. Pressing UP or DOWN changes the patch number. You can hold the button pressed to get a faster scrolling through the numbers. Pressing the UP or DOWN button when the display is switched off will directly enter the patch view mode and step the patch number up or down.

The patch number will be remembered by the controller even when powered off. Holding ENTER button while powering up the NuEVI will have it send a program change for the current patch selected.

FastPatch selection

You can store up to seven patch numbers that can be instantly recalled by holding a combination of trill keys when pressing any of the buttons ENTER, UP or DOWN from display sleep or patch view state. (Just reach with your LH thumb without looking.) If no patch number is stored for the selected memory slot, the selection will be ignored, and the current patch number will be displayed.

To save a patch number into a memory slot, use UP and DOWN to select the patch you want to store (no trill keys touched). From display sleep, finger the trill key combination you want to use as memory slot, press and hold MENU, then immediatly press ENTER while still holding MENU. The display will briefly indicate that the FastPatch has been set.

To clear a FastPatch memory slot, finger the trill key combination for the slot, press and hold MENU, then immediatly press UP while still holding MENU. The display will briefly indicate that the FastPatch slot has been cleared.

Mind that accidentally touching trill keys when using UP, DOWN or ENTER for patch selection will recall a FastPatch or just display the current patch if no FastPatch is set for that slot, so keep fingers off the trills if you are just doing regular patch selection.

All notes off

Should a situation of stuck notes occur, a ”midi panic” or “all notes off” can be sent by pressing and holding the ENTER button, then the MENU button while still holding ENTER, from display off state. Big friendly letters on the display will also tell you not to panic.

Special key

Introduced with the Steiner MIDI EVI, the special key added the possibility to play chords and intervals. This has been implemented in the NuEVI too.

To use special key functions, make sure SPEC KEY is enabled in the EXTRAS menu.

The first function is slur sustain. To activate this, touch the Special key while holding a finger on K4 (side key or arc key). Slur sustain will send a sustain (hold) pedal on command when a new note is tongued, keep it held as long as new notes are slurred, building chords by slurring and holding them until breath is released. A new chord can then be started by tongueing a new note. The latest chord or interval played will be stored for use with the parallel chord or interval function.

Parallel chord or interval is activated by touching the Special key while holding K5 (first trill key). If no chord or interval has been stored by slur sustain, a default interval of a perfect fifth below the played note is used.

Activating slur sustain will switch the parallel chord function off and any intervals or chords slurred will then overwrite the previously stored chord.

The sub octave double function is activated by touching the Special key while holding K1 (first valve). This adds a note played one octave down from played note(s). This can be used in combination with slur sustain or parallel chord functions.

When in any of these polyphonic modes, the orange LED on the Teensy will be flashing instead of glowing steadily.

Touching only the special key will switch off any active special key functions.

Rotator

As an additional chord playing feature, we have added a ”rotator” that will bring some extra magic into the chord playing. It creates a three note chord using your base note, a fixed interval parallel note and a third note taken from a rotating selection of four notes. For every new note triggered, the rotation is advanced one step, and a new combination of notes is played.

To activate the rotator, touch the special key while holding the mod key. This will at the same time switch off any other special key functions.

When in rotator play, the orange LED on the Teensy will be flashing, as with the other chord playing functions.

Touching only the special key then will turn the rotator playing off.

Setup of the rotator note intervals can be done in the ROTATOR menu in the main menu. PARALLEL sets the fixed parallel note and ROTATE 1 – 4 sets each of the four intervals being rotated for the third note. PRIORITY sets which note will get priority when playing mono patches (sounds really great to layer a mono patch with a poly patch for use with rotator/chord play). MEL will play the base note as the mono lead and ROT will play the rotated note. This setting also affects playing with parallel chord and interval, where you can choose from having the base note or the last note of the chord as the lead voice.

Setting an interval to 0 disables the note output for that interval. For the rotated intervals, this also means it is skipped, moving on to the next note. This means you can have rotation between only two or three notes instead of four, or create a set interval or chord with no rotation.

Legacy instant controls

The MIDI EVI was using fingering combinations to alter settings and send patch change commands. For advanced users this can still be a desired thing, so there’s support in the NuEVI for the most important parts.

Set this functionality on and off (default off) using the LEGACY PB setting in the EXTRAS menu.

When the legacy instant controls are activated, you can instantly recall a patch number by its respective MIDI note number. For example, by fingering middle C (any transpositions set are not active here) while not playing, you are selecting patch number
72. Touch both pitch bend pads at the same time to send the patch change command for the patch number you are fingering. The Teensy LED will flash once to confirm. Note that if that patch number is already the patch known as active in the NuEVI, the command will not be sent. To select patch numbers in the top and bottom end of the range 1 to 127, add the pinky key to your fingering.

Using MIDI channel switching can be useful for switching between synths or patches in performances. To instantly select a MIDI channel number, you can finger it using middle C and upwards cromatically, where mid C represents MIDI channel #1, touch the lip sensor with your lip, then touch both pitch bend pads at the same time. The Teensy LED will flash once to confirm. Note that a MIDI setting selected this way will not be remembered after powering off, unless you go into the MIDI CH menu to confirm the change. This way, if you have no idea why you suddenly can’t get a sound (because you accidentally managed to switch to some other MIDI channel) a power cycle will get you back in business.

Another way to trig the instant controls is to apply a gentle sucking (negative air pressure) to the mouthpiece, while touching pitch bend up, instead of touching both PB pads. To activate this functionality, go to LEGACY BR setting in the EXTRAS menu. Using the sucking together with pitch bend down, Nyle has added the legacy program button control to the NuEVI. For notes on that, see last page.

Yet another alternative way for patch number selection is to finger the number like above, then lock it in by momentarily touching the pinky key. Send mid range values by touching first valve and first trill keys at the same time, top and bottom range values by touching second valve and second trill keys at the same time.

Gate Hold

A trick for getting smooth attacks on some synths, where you don’t need velocity values, is to keep notes always on and control the volume/filter with breath only. A way to do this is to change the breath THR value to be just slightly below the idle reading. This is a bit unpractical though, so we put in a little bonus thing to make it easier.

First make sure GATE HOLD setting in EXTRAS menu is ON, then continue below.

To activate Gate Hold, grab the canister like a door knob, touching the side key and the bottom three rollers at the same time. Then touch the pitch bend up pad. The Teensy LED will flicker fast to indicate activation, then keep flashing until deactivated.

To deactivate Gate Hold, do the same thing but with touching the pitch bend down pad. The LED will flicker three times to confirm.

While Gate Hold is on, some setting changes (like MIDI channel or patch number) will not take effect until Gate Hold is switched off again.

Connections

The NuEVI has two ways of connecting to synthesizers and computers. The first is using the standard DIN MIDI OUT jack, connecting using a standard MIDI cable to the MIDI IN of a hardware synth or computer MIDI interface. The second way, new to the EVI world, is by using the Micro USB port on the side of the NuEVI. Using a standard Micro USB charge/sync cable, you can connect the controller to any computer or MIDI USB host hardware supporting class compliant MIDI over USB. The NuEVI will be recognized as ”NuEVI MIDI” by your system. Using a Lightning to USB Camera Adapter, you can even connect your NuEVI directly to an iPad or iPhone and use it with softsynth apps.

The Micro USB connection will also power the NuEVI when the battery switch is in the backmost position (battery power off). The low power requirement of the NuEVI makes it possible to run it from any computer USB port, USB charger (please use quality ones and don’t put your instrument at risk) or even from your iPad. Mind that switching between USB power and battery power will switch the controller off and on again.

NuEVI Plus model also features a pair of 3.5 mm mono jacks for supplying breath and note pitch CV to analog synths. Breath CV is 0V to 10V and note pitch CV is 1V/octave in eight octaves. (CV signals also output on the two unused pins of the MIDI jack.)

Pitch bend pad adjustment

The pitch bend pads can be loosened using a screwdriver and slightly shifted in distance from the thumb rest. Find the placement that makes most sense to you and tighten the screws. Don’t over-tighten, as you could cause damage to the conductive plastic of the pitch bend pads if you do. If the pad is not moving or wiggling when pressed against from the thumb rest position, you should be good to go.

Battery check

When the main menu is activated, the battery voltage will be indicated top right of the display. Values over 4.9V will indicate that the instrument is powered over USB, and below that it will indicate it as battery voltage. Normal voltage for a set of new alkaline batteries will be about 4.6V. The value will drop as the batteries are being used, giving a hint of the current battery condition. Below 3.7V they are due to be replaced, and the indicator will say BAT LOW. If you are using NiMH rechargeable batteries, change the battery type setting in the EXTRAS menu to NMH. This will set the right threshold value for BAT LOW indication.

Going into the ABOUT menu, you will also see the set battery type and a rough approximation of remaining battery percentage.

Battery replacement

With the NuEVI switched off and disconnected from USB or DIN MIDI, unscrew the frontmost thumbscrew on top of the controller and loosen the one at the back of the battery compartment slightly. Slide the lid forward and lift it off the controller. Replace the batteries (3xAAA 1.5V alkaline or 1.2V NiMH for NuEVI, 3xAA for NuEVI Plus and NuEVI CV) and slide the lid back in place. Get the front thumbscrew in place first, then tighten both screws. Only finger gripping power should be applied. Do not use pliers or similar tools or you will most certainly scratch the plastics of your instrument.

Firmware updates

Updates for the NuEVI firmware are supplied in .hex format when new features or bug fixes are released. The current firmware version is shown in the NuEVI display while powering on. Firmware upload is done using a software tool called Teensy Loader. It can be downloaded from https://www.pjrc.com/teensy/loader.html, where you also find instructions for using the Teensy Loader to upload the .hex file. To restart the NuEVI in program mode, making it visible to the Teensy software, press all four buttons by the NuEVI display simultaneously while the display is not active (or open the case slightly and press the program button on the Teensy). If you get a message in the Teensy loader app that the hex file you selected is too big, just ignore it and put your EVI in program mode. The board version will be recognized and the hex file can be uploaded. If the app is in Auto mode it will upload as soon as you get the EVI in program mode, otherwise you need to click Program and Reboot after the Teensy chip has been recognized and the Teensy picture in the app has gone from faded to normal.

Mind that major updates to the firmware will often reset the NuEVI to default settings, including sensor adjustments (updating 1.0.5 or higher will keep the sensor adjustments). You will be required to set it up again to your liking after the update. Please take notes (or pictures) of your custom settings if you are unsure.

Firmware update releases are found at https://github.com/Trasselfrisyr/NuEVI/releases

Factory restore

Only if you are sure this is what you need to do – to restore the factory default settings, including sensor adjustments, hold ENTER and MENU buttons when switching on the NuEVI. Release when the orange LED glows steadily. Make sure you take notes or take photos of settings and sensor adjustments before doing this. Your sensor calibrations will be off target when reset, and you have to set them right to have a well performing controller.

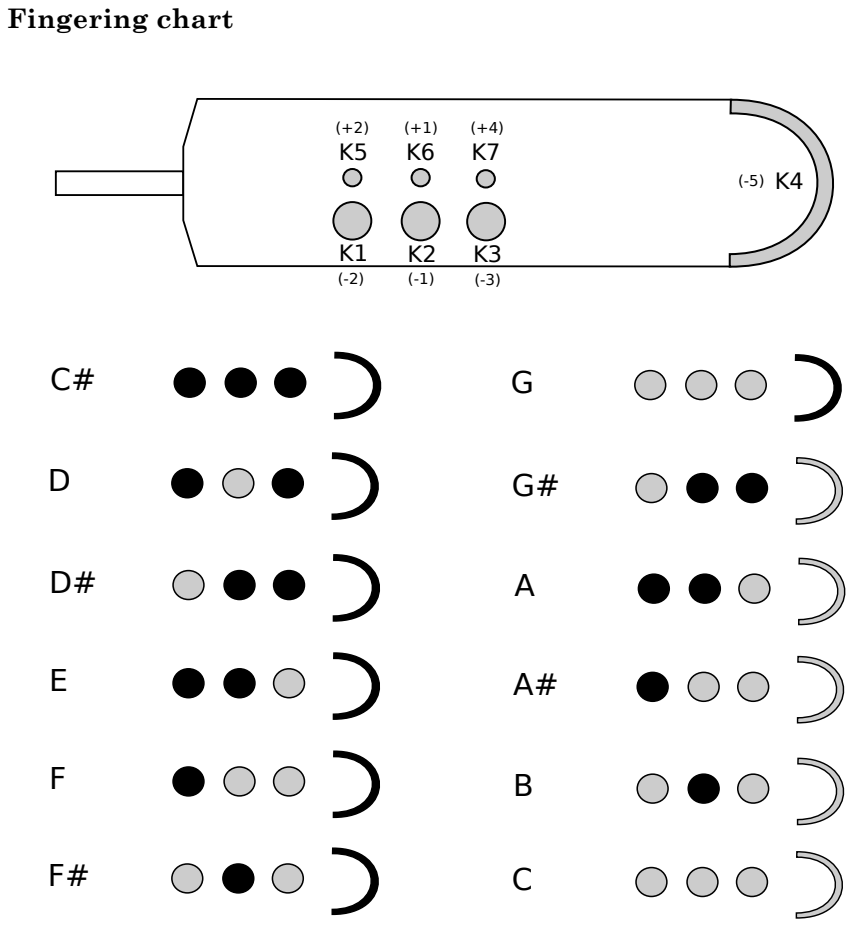
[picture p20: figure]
Fingering chart

These are just the core fingerings. Experiment with the trill keys (K5 to K7) to find useful alternate fingerings near octave breaks and in other situations where they could come in handy.

Breath CV output

There is a control voltage output for breath level on one of the unused pins of the DIN MIDI jack on the NuEVI. The pin is the same as it was for the MIDI EVI (looking at the jack, with the arch of holes going the ”rainbow” way, it’s the leftmost pin). A special breakout cable or breakout box will be needed to get access to this, and the DAC MODE should be set to BRTH. The CV goes through the D/A converters of the Teensy microcontroller in the NuEVI. It nevertheless provides a smooth signal at a fast rate, ranging from 0 to 3.3 volts. Those 3.3 volts are enough to fully open many modular filters, but others will need amplification to a 0 to 5V CV signal using a CV scaler or a breakout box with this kind of amplification built in.

With optional CV box or built in CV board (NuEVI plus and NuEVI CV), the DAC
MODE setting in EXTRAS menu should be set to PTCH. Using CV box with the NuEVI, the pin otherwise used for breath CV is then carrying note pitch CV, and the other pin is carrying PWMed breath CV (filtered in the box). On the NuEVI plus, the scaled CV signals are output both to dedicated 3.5mm jacks and to the unused MIDI pins. (Do not use NuEVI plus or NuEVI CV with the active CV box.)

Nyle’s program button notes

I have added the equivalent of the vintage midi evi programming button.
It is activated by holding the down pitch bend and sucking.
The legacy breath activate feature must be toggled on for this to work. Press MENU button while holding extra controller and pinky key as per instruction manual.

Implemented so far:
1. Middle octave position (c72). Ability to assign midi breath parameters, midi volume, midi aftertouch, midi breath, midi expression and velocity.
1v - midi volume
2v - midi aftertouch
3v - midi breath controller
side button - midi expression
1tr - note on velocity
2. Lowest octave position (c36). Ability to increment - decrement and send midi patch change commands.
F29 - decrement and send patch change
G31 - increment and send patch change

E28 - subtract 10 and send patch change
F#30 - add 10 and send patch change
When NuEVI is turned on, Incr - Decr starts from whatever patch number is stored in EEPROM.

3v - send reverb amount cc91, value determined by pinky pitch latch. C36 equals zero. Vintage evi never had this reverb send feature; I put it in here just because my own setup takes advantage of it.

I still want to add a C36 (open with no keys) All Notes OFF command but have not done it yet.

Pinky pitch latch works exactly the same as it does on the vintage midi evi. When not blowing, just press pinky key momentarily while holding a note fingering. The note and octave position will determine a value and store it in ram memory (latch). This value can then be assigned to a parameter using the programming button.

Note: Calling patch changes randomly by fingering is not part of this programming button feature and does not use the pitch latch. You simply suck with no pitch bend applied and a patch is sent according to which note you are holding. This simulates the missing patch change button that is also on the vintage midi EVI.

Nyle

Troubleshooting tips

Problem: Intermittent small pitch bend messages are sent, especially when blowing into the mouthpiece.

Solution: The vibrato squelch is set too tight. Up the settings value a step or two. Also check pitch bend adjustment settings and make sure the idle sensor readings are not above THR line.

Problem: When using the optional wireless kit, some keys don’t respond properly.

Solution: Make sure you keep your thumb on the grounding square on the canister while playing wirelessly, for better touch response. Also check the touch sense adjustments, and maybe try bringing the THR bar closer to the cluster of dots. You can use the touch sensor dots to monitor the touch response of each key and roller, to see how they respond with and without thumb grounding.

Problem: I’m getting dropouts and hung notes when playing, or it stops sending MIDI completely.

Solution: Check your battery level and make sure you have fresh batteries.

Problem: When using wireless MIDI, the patches start randomly changing or notes get dropped. Or connection is lost, with the receiver LED blinking.

Solution: Batteries are getting low and not providing enough current for the transmission bursts. This can happen before LOW BAT is indicated for some battery types. Switch to fresh good quality batteries.

Problem: Using CV on NuEVI Plus, NuEVI CV or standard NuEVI with NuEVI CV Box, both CV jacks send breath CV.

Solution: Check DAC MODE setting in EXTRAS menu. It should be set to PTCH, not BRTH.

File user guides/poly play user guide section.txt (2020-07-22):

POLY PLAY

In the Poly Play menu you configure everything having to do with polyphonic playing functions. 

POLY PLAY – POLY MODE

Here you select which type of harmonization or which rotator setup will be activated by touching/holding MOD key (NuRAD) or Pinky Key (NuEVI) and then touching Special Key(s). Deactivate by just touching Special Key(s).

OFF – disables all Special Key functionality, including the Parallel Chord, Slur Sustain and Sub Octave functions
MGR – Major Gospel Root – a gospel type triad voicing
MGD – Major Gospel Dominant – same as MGR, but with a dominant on V instead of an inversion of the root
MA9 – Major add9 – pop style add9 harmonization
MND – minor Dorian – jazz type minor
MNA – minor Aeolian – classical minor
MNH – minor 4-voice Hip – a more hip dorian minor
FWC – Four Way Close – old school block chord harmony (with additional options further down in the Poly Play menu)
RTA – Rotator A
RTB – Rotator B
RTC - Rotator C

POLY PLAY – HMZ KEY

Selects the key you are playing in for the key based harmonizations. 

POLY PLAY – OTF KEY

Enables on the fly key change for the key based harmonizers. To change key on the fly while playing, finger the key (not blowing) and briefly lift your thumb off the rollers (when in octave two or higher). Key change on the fly will not be stored when powered off. 

POLY PLAY – HMZ LIMIT

Limits the number of voices to be played, starting elimination from lowest note and up. Applies to the key based harmonizations only, not Rotator, Parallel Chord or Slur Sustain.

POLY PLAY – FWC TYPE

Type of block chord for the Four Way Close harmonization. (6, m6, 7 or m7)

POLY PLAY – FWC LOCKH

"Lock Hands" (double melody) adds another melody note one octave down for the Four Way Close harmonizations. (OFF/ON)

POLY PLAY – FWC DROP2

"Drop 2" moves the second note (the one below melody note) one octave down for the FWC. (OFF/ON)

POLY PLAY – PRIORITY

Sets which note will get priority when playing mono patches (sounds really great to layer a mono patch with a poly patch for use with with the Poly Play functions). MEL will play the melody note as the mono lead and ROT will play the rotated note or last note of other poly modes.

POLY PLAY – RTA PARAL
POLY PLAY – RTA ROT 1
POLY PLAY – RTA ROT 2
POLY PLAY – RTA ROT 3
POLY PLAY – RTA ROT 4

POLY PLAY – RTB PARAL
POLY PLAY – RTB ROT 1
POLY PLAY – RTB ROT 2
POLY PLAY – RTB ROT 3
POLY PLAY – RTB ROT 4

POLY PLAY – RTC PARAL
POLY PLAY – RTC ROT 1
POLY PLAY – RTC ROT 2
POLY PLAY – RTC ROT 3
POLY PLAY – RTC ROT 4

This last section of settings is for the three rotators. They create a three note chord using the melody note, a fixed interval parallel note and a third note taken from a rotating selection of four notes. For every new note triggered, the rotation is advanced one step, and a new combination of notes is played. For each uf the three selectable rotator setups you can configure the fixed interval with RTx PARAL and the four intervals to be rotated for the third note with RTx ROT 1 to RTx ROT4, where x represents rotators A through C.

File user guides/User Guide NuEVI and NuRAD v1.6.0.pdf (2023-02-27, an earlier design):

# User Guide

## NuEVI and NuRAD Firmware v.1.6.0


Johan Berglund
2022-10-17
NuEVI and NuRAD User Guide | 1

## Origins

The Electronic Valve Instrument was invented back in the early 1970s by Nyle Steiner. The first production instruments were using mechanical switches in a handset connected to an analog synthesizer module, and they were sold from 1975 to 1979 by the Steiner-Parker company. When the company had dissolved, the instrument was produced by Crumar.

In the mid 80s, Steiner designed and built a number of instruments with a more complex synthesizer and touch sensing for the keys. They were referred to as Steinerphones, and and came in both brass and woodwind variety.

In 1987 a new type of EVI was licensed and sold by AKAI. This new version together with its woodwind counterpart released at the same time, the EWI, was using touch sensing for the finger controls and a programmable synth module capable of sending MIDI for controlling other synthesizers. The Akai EVI was discontinued due to not selling as well as the EWI that is still made by AKAI in new incarnations.
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

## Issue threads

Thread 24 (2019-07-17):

Sensor adjustment menus do not work

jstck, 2019-07-17:
The "touch sense" menu works well, but the other adjustment menus do not. The line isn't blinking or moving, but it seems calibration values are being changed (after exiting and refreshing menu, lines have moved and stuff is written to EEPROM).

blind, 2019-07-17:
It seems display.display() is not called when changing adjust values. I'll look into it.

blind, 2019-07-17:
Found the bug, fix incoming.

Closed 2019-07-17.

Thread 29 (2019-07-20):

Reduce memory footprint by removing lambdas

blind, 2019-07-20:
Ordinary functions+function pointers should be used instead.

jstck, 2019-07-22:
a) How would functions + function pointers look in this case? A separately defined `updateThisParticularMenuThing` function for each MenuEntry?

b) How do you determine memory footprint for these things? Particularly, how would one tell on the Teensy?

blind, 2019-07-22:
a) The rotator menu already does this, by having two separate functions as you said.

```
static void rotatorPrioOptionGet(SubMenuRef __unused, char* out, const char** __unused) {
    if (priority) strncpy(out, "ROT", 4);
    else strncpy(out, "MEL", 4);
}

static void rotatorPrioSave(SubMenuRef __unused) {
  writeSetting(PRIO_ADDR,priority);
}

const MenuEntrySub rotatorPrioMenu = {
  MenuType::ESub, "PRIORITY", "MONO PRIO", &priority, 0,1, MenuEntryFlags::EMenuEntryWrap,
  rotatorPrioOptionGet, rotatorPrioSave, nullptr,
};
```

b) I've been keeping track of global memory use from the build result when compiling via the Arduino app. It seems the lambdas are constructed in runtime, so the structs are stored in RAM when lambas are used, but with normal function pointer they can be kept in ROM.

I did a quick test by extracting the lambdas for the pinky menu, and 40 bytes were saved when both lambdas were converted to normal functions. Now the question is if it's worth the effort if we are going to continue refactoring the menu with classes and stuff anyway.

jstck, 2019-07-22:
If it is worth doing I guess depends entirely on if we hit the RAM or ROM (flash) limit first, and if either of them will ever happen.

Closed 2024-07-31.

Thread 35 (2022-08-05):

What hardware is used for the pneumatic bite sensor

tommaier123, 2022-08-05:
Hello,
I want to build my own NuEvi. Most of the components I can figure out by looking at the schematic or in the code.
But I am not sure what hardware is used for the pneumatic pressure sensor.
Going for the capacitive bite sensor is probably a bit easier but I'd like to try out the pneumatic version.

Trasselfrisyr, 2022-08-05:
Hi,

The pressure sensor used for PneuBite is the same as for the breath, MP3V5004GP. Fork the tubing and put a car tire valve core in place to make it possible to equalize pressure to ambient air pressure. It’s very important that the system is 100% air tight. I use clear bathroom silicone on joints to keep tight. Also important for the same reason that the mouthpiece bite sensor side is air tight (common problem).

Attaching gerber for PneuBite board. Goes over NuEVI board resistors (double sided tape under the small board is good) and onto pins marked 11 and 12 (if I remember correctly). Put a jumper on those pins also to keep board in place and to ensure connection between those pins (telling the code that the board is installed. Output from the board goes to pin marked A7.

Best,
Johan

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

tommaier123, 2022-08-06:
Thanks for the info. Sounds tricky to get everything airtight but I'll give it a try.
Can't wait to start building once I get my hands on a Teensy :)

Closed 2022-08-06.

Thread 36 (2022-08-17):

What hardware is used for vibrato lever

tommaier123, 2022-08-17:
Hello,
I've got almost all of the hardware now but I am missing the vibrato lever.
From looking at the code it seems to be a variable capacitor. Is there an off the shelf component that has a lever or did you build one yourself?

Trasselfrisyr, 2022-10-11:
It’s a bracket bent from 0.4 mm brass sheet/strip with a long M2 screw in place for making the lever. Lip of the bracket is insulated with tape and moving the flexing strip to change capacitance.

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

Closed 2024-07-31.

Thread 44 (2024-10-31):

idea - MOD KEY KeyBitMask Mode

jdiercks, 2024-10-31:
I'm toying with this idea but haven't started coding yet.
Anyone have any thoughts/suggestions?
Is this something you would use?

# idea - MOD KEY KeyBitMask Mode

## description
* add new option in menu under SETUP CTR > MOD KEY: KBM (KeyBitMask mode)
* uses CC# configured for Extra Controller CC B, referred to here as CCB

## program logic
* if KBM mode is configured and a new MOD KEY press is detected:
  * if any RH keys are held:
    * send CCB+1=RH keys status as 7-bit bitmask (1,2,3,p1,p2,p3,side)
  * if any LH keys are held:
    * send CCB+2=LH keys status as 7-bit bitmask (1,2,3,p1,p2,p3,bis)
  * send CCB with value=
    * 1-bit flag=1 for MOD pressed (so active value will always be >=64)
    * 1-bit value for special-key status
    * 1-bit zero placeholder (reserved for future use?)
    * 4-bit octave roller position value
  * until MOD KEY is released:
    * if any changes occur in keys/rollers status:
      * send CCB=mod+special+octave as above
      * send CCB+1=RH keys status as above
      * send CCB+2=LH keys status as above
  * send CCB=0 to signal MOD KEY released

## benefits
* enables hundreds of unique trigger messages with quick one-shot fingerings
* infinite combinations of complex multi-key sequences possible
* receiving host can detect all relevant press _and_ release events
* could be combined with PbUp/Dn or other sensors to intuitively adjust values
* possible to send certain triggers even while notes are being played
* could be useful for testing/troubleshooting hardware
* does not require modifying NVRAM data structure for storing settings

## caveats
* requires allocating a group of 3 sequential CC numbers that do not conflict with anything else in host setup
* host may need sophisticated scripting to process some messages (binary math)
* some risk of accidental triggering if MOD key gets bumped
* host may need to account for glitchy multi-key fingerings and check timing between messages to interpret intent correctly
  * wait for MOD release signal then look at the most recent CC values to determine intended message
  * or could require a specific pause (50-100ms) before/after certain press/release events to commit
* indiscriminate configuration could result in unintended consequences (with great power ...)
  * might be wise for host script to reserve one fingering for a “cancel” signal, to disregard any preceding messages
  * or maybe assume cancel if all other keys are released before MOD
  * scripts should not blindly pass through messages that are not expected
  * AUM channels/nodes should ignore unneeded CCs

## possible variations to consider
* KB1=KeyBitMask One-shot: similar to KBM, but:
  * only works if MOD pressed with no other LH/RH initially (rollers/special are OK and reported)
  * only sends one CCB when MOD pressed and one RH and/or LH (whichever are held) + CCB=0 when MOD released
  * lowest risk of accidental triggers, but very limited compared to other modes
  * still hundreds of possible unique triggers with combined roller/special/RH/LH inputs
  * still allows for combining with Pb/other sensors while MOD held
* KCC=Keys2CCs mode: send a different CC# for each key
  * assign each individual key an offset value (k)
  * if MOD is held, send CCB+k=127 for press, CCB+k=0 for release
  * more friendly to synths with MIDI Learn that expect triggers in this form
  * provides up to 16 possible unique CCs (MOD key alone, 14 RH/LH keys, special key)
  * scripts could still listen for multi-key sequences
  * need to prevent sending “reserved” CCs such as breath to avoid conflicts (skip them in range when calculating CCB+k)
    * setting CC# for CCB to 102 sstarts at a relatively “safe” range of non-reserved CCs (102-119)
  * possible to send messages as momentary on/off or one-shots for toggles
    * only send CCB=127 if MOD pressed with no other RH/LH held
    * only send CCB=0 if MOD released with no other RH/LH held
    * only send CCB+k=0 if MOD held when k released
* KCO=Key2CC+Octave: Like KCC, but instead of 127 for press, set value according to octave roller position:
  * 1=thumb off rollers
  * 2=lowest octave
  * 64=middle?
  * 127=highest roller
  * also check rollermode, make sure bonus top octave is 127 if active, and make top roller 96
* KCP=Key2CC+PitchBend: Like KCC but pitchbend sets CC value
  * value=64 if Pb centered/normal
  * value=0 Pb full down
  * value=127 Pb full up
  * do not send CCB+k=0 on release
* KBC=KeyBitMask Continuous: CCs are _always_ sent like KBM on _any_ change, regardless of MOD status

KBC would mostly be useful for diagnostic purposes, but it could be used in insanely powerful ways. For example, a script could completely override standard note fingering modes - ignore note-on/off pitch values from NuRAD and have Mozaic replace them based on its own fingering rules reading the KeyBitMask CCs. And even in KBC mode, MOD key could still act as a command/function trigger if the script interprets it that way.

Realistically, most of the practical use cases that I have in mind for this would probably work best in KBM mode.

It should be possible to write mozaic scripts intended primarily for use in KB1 mode, and also designed to effectively ignore any additional unneeded traffic that might be generated by the other modes.

## use case examples/ideas
* patch changes - faster than “fastpatch” :-)
* control effects like reverb & delay
* toggle internal patch settings/features
* host transport start/stop / looper controls
* quick host-side transpose (octave/semitone)
* host-based harmonizer/rotator
* “drum machine” mode
* sheet music / chord chart page-turner
* lighting cue triggers

jdiercks, 2024-10-31:
The more I think about it, the more I think KCC is the best model for me to try implementing first. Easier to understand than the others, and easier to use directly with synths / DAWs that expect functions to be mapped by CC number and not value. Less likely to require sophisticated middleware scripting on the host.

jdiercks, 2024-10-31:
superseding this with [this](https://github.com/Trasselfrisyr/NuEVI/issues/45)

Closed 2024-10-31.

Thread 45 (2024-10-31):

idea - MOD KEY Keys2CCs Mode

jdiercks, 2024-10-31:
(this idea supersedes [this one](https://github.com/Trasselfrisyr/NuEVI/issues/44))

Any thoughts/suggestions on this?

# idea - MOD KEY Keys2CCs Mode
* add new option in menu under SETUP CTR > MOD KEY: KCC (Keys2CCs mode)
* sends selectable CC messages when/while MOD KEY pressed
* uses a range of 16 CCs starting with CC# configured for Extra Controller CC B, referred to here as CCB

## logic
* assign each individual key a CC offset value (k)
  * e.g., RHside=1,RH1=2, ... RHp3=7, special=8, LHbis=9, LH1=10, ... LHp3=15
* on new MOD key press event:
  * if any RH/LH held:
    * send CCB+k=127 for each held key (lowest k numbers first)
  * else:
    * send CCB=127
  * while MOD still held:
    * if any new RH/LH key event detected:
      * send CCB+k=127 for each new press
      * send CCB+k=0 for each new release
  * if no other RH/LH still held:
    * send CCB=0

## benefits
* enables up to 16 unique CC trigger messages with quick one-shot fingerings
* friendly to synths/DAWs with MIDI Learn functions
* possible to send messages as momentary on/off or one-shots for toggles
* infinite combinations of complex multi-key sequences possible with host scripting
* receiving host can detect all relevant press _and_ release events
* could be combined with PbUp/Dn or other sensors to intuitively adjust values
* could be useful for testing/troubleshooting hardware
* does not require modifying NVRAM data structure for storing settings

## caveats
* some risk of accidental triggering if MOD key gets bumped
* need to prevent sending “reserved” CCs such as breath to avoid conflicts (skip them in range when calculating CCB+k)
  * setting CC# for CCB to 102 sstarts at a relatively “safe” range of non-reserved CCs (102-119)

## use case examples/ideas
* patch changes - faster than “fastpatch” :-)
* control effects like reverb & delay
* toggle internal patch settings/features
* host transport start/stop / looper controls
* quick host-side transpose (octave/semitone)
* host-based harmonizer/rotator
* “drum machine” mode
* sheet music / chord chart page-turner
* lighting cue triggers

jdiercks, 2024-11-02:
I've started coding this, and rewrote the description above to reflect the actual implementation I'm landing on.

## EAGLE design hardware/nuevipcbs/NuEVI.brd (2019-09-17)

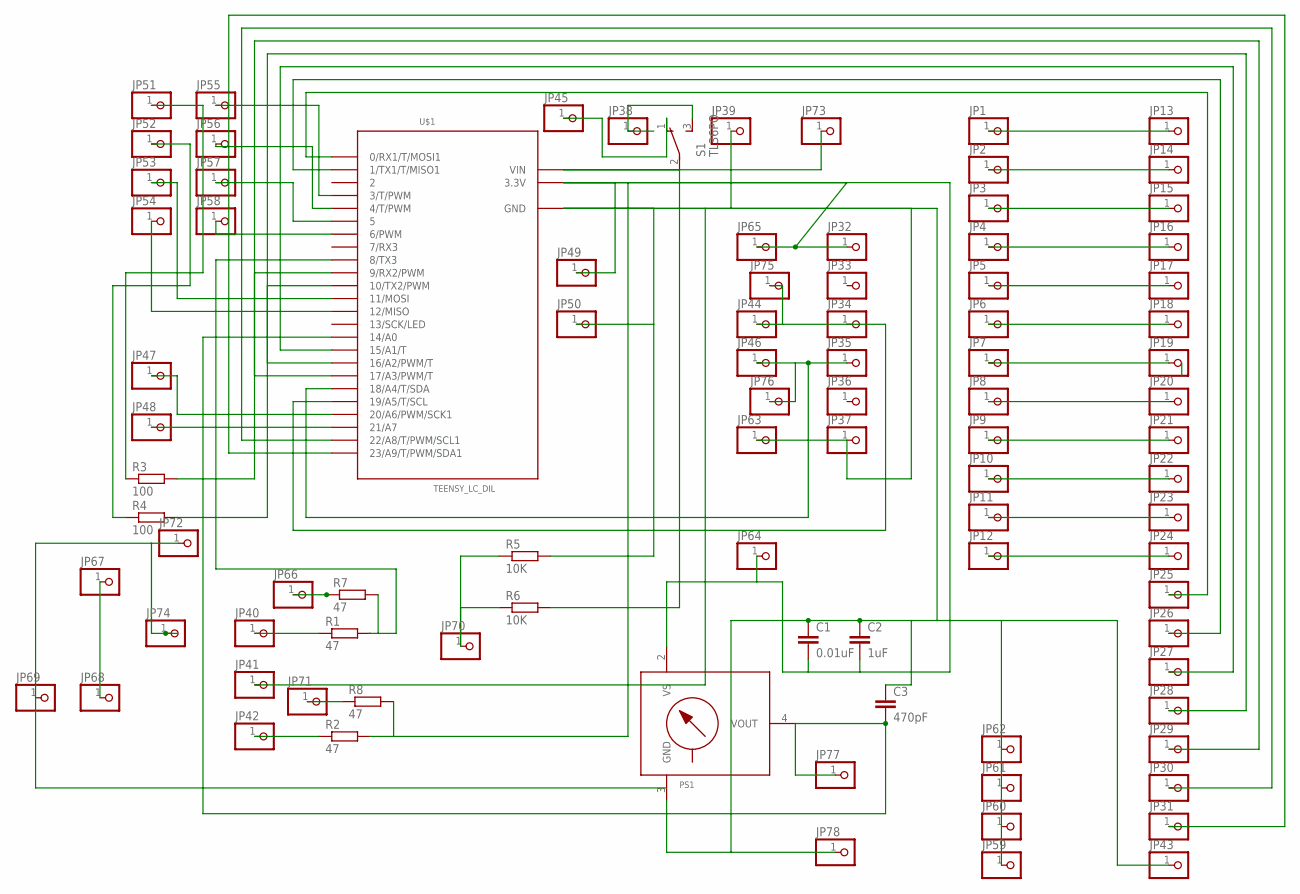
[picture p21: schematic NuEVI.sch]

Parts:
C1: 0.01uF; C050-024X044
C2: 1uF; C050-024X044
C3: 470pF; C050-024X044
JP1, JP2, JP3, JP4, JP5, JP6, JP7, JP8, JP9, JP10, JP11, JP12, JP13, JP14, JP15, JP16, JP17, JP18, JP19, JP20, JP21, JP22, JP23, JP24, JP25, JP26, JP27, JP28, JP29, JP30, JP31, JP32, JP33, JP34, JP35, JP36, JP37, JP38, JP39, JP40, JP41, JP42, JP43, JP44, JP45, JP46, JP47, JP48, JP49, JP50, JP51, JP52, JP53, JP54, JP55, JP56, JP57, JP58, JP59, JP60, JP61, JP62, JP63, JP64, JP65, JP66, JP67, JP68, JP69, JP70, JP71, JP72, JP73, JP74, JP75, JP76, JP77, JP78: PINHD-1X1; 1X01
PS1: MPX-1369; 1369
R1, R2, R7, R8: 47; 0207/7
R3, R4: 100; 0207/7
R5, R6: 10K; 0207/7
S1: TL36PO; TL3XPO
U$1: TEENSY_LC_DIL; TEENSY_3.0-3.2&LC_DIL

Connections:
GND: C1.1, C2.1, C3.1, JP37.1, JP39.1, JP41.1, JP43.1, JP50.1, JP59.1, JP60.1, JP61.1, JP62.1, JP63.1, JP69.1, JP72.1, JP74.1, JP78.1, PS1.3 (GND), R5.2, U$1.AGND (GND), U$1.GND
unnamed: JP1.1, JP13.1
unnamed: JP2.1, JP14.1
unnamed: JP3.1, JP15.1
unnamed: JP4.1, JP16.1
unnamed: JP5.1, JP17.1
unnamed: JP6.1, JP18.1
unnamed: JP7.1, JP19.1
unnamed: JP8.1, JP20.1
unnamed: JP9.1, JP21.1
unnamed: JP10.1, JP22.1
unnamed: JP11.1, JP23.1
unnamed: JP25.1, U$1.0 (0/RX1/T/MOSI1)
unnamed: JP12.1, JP24.1
unnamed: JP26.1, U$1.1 (1/TX1/T/MISO1)
unnamed: JP27.1, U$1.15/A1 (15/A1/T)
unnamed: JP28.1, U$1.16/A2 (16/A2/PWM/T)
unnamed: JP29.1, U$1.17/A3 (17/A3/PWM/T)
unnamed: JP30.1, U$1.22/A8 (22/A8/T/PWM/SCL1)
unnamed: JP31.1, U$1.23/A9 (23/A9/T/PWM/SDA1)
unnamed: C1.2, C2.2, JP32.1, JP49.1, JP64.1, JP65.1, PS1.2 (VS), R2.2, R8.2, U$1.3.3V
unnamed: JP47.1, U$1.20/A6 (20/A6/PWM/SCK1)
unnamed: JP34.1, JP44.1, JP75.1, U$1.19/A5 (19/A5/T/SCL)
unnamed: JP35.1, JP46.1, JP76.1, U$1.18/A4 (18/A4/T/SDA)
unnamed: JP38.1, S1.3 (S)
unnamed: R1.2, R7.2, U$1.8 (8/TX3)
unnamed: JP40.1, R1.1
unnamed: JP42.1, R2.1
unnamed: C3.2, JP77.1, PS1.4 (VOUT), U$1.14/A0
unnamed: JP73.1, R6.2, S1.2, U$1.VIN
unnamed: JP48.1, U$1.21/A7
unnamed: JP51.1, R3.1
unnamed: JP52.1, R4.1
unnamed: JP53.1, U$1.11 (11/MOSI)
unnamed: JP54.1, U$1.12 (12/MISO)
unnamed: JP55.1, U$1.3 (3/T/PWM)
unnamed: JP56.1, U$1.4 (4/T/PWM)
unnamed: JP57.1, U$1.5
unnamed: JP58.1, U$1.6 (6/PWM)
unnamed: JP45.1, S1.1 (O)
unnamed: R4.2, U$1.10 (10/TX2/PWM)
unnamed: JP67.1, JP68.1
unnamed: R3.2, U$1.9 (9/RX2/PWM)
unnamed: JP70.1, R5.1, R6.1
unnamed: JP71.1, R8.1
unnamed: JP66.1, R7.1

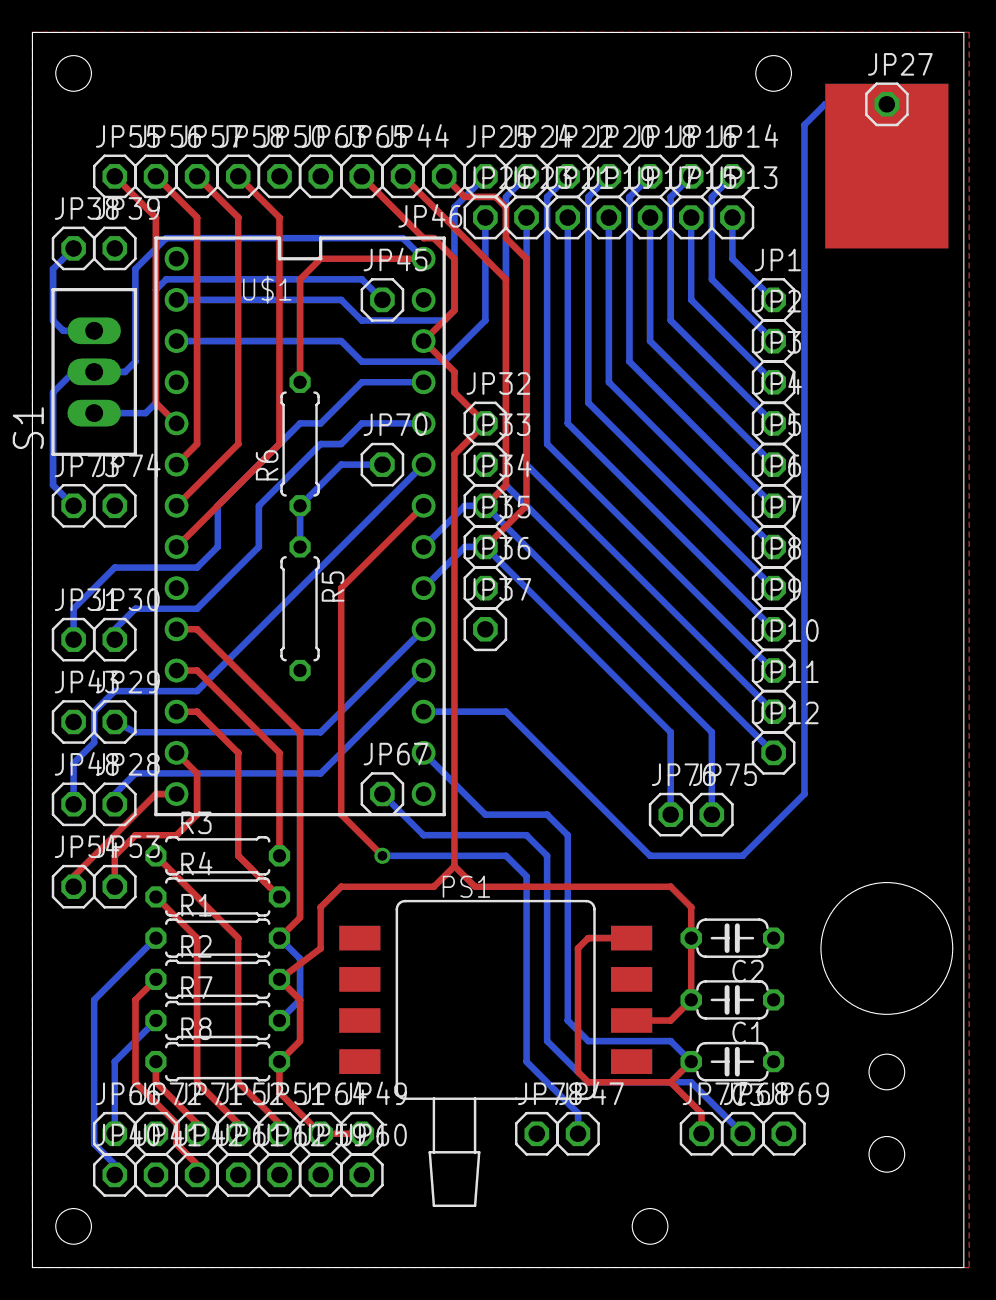
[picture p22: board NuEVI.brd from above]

Board: 2 copper layers, 57.5 x 76.2 mm, 92 parts (0 on the bottom side), 46 nets.

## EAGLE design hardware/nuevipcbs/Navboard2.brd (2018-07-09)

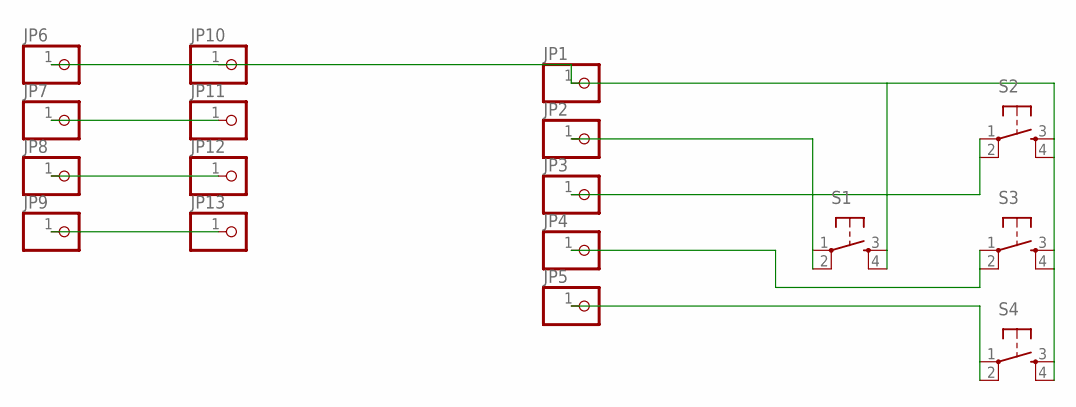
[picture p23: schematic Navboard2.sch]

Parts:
JP1, JP2, JP3, JP4, JP5, JP6, JP7, JP8, JP9, JP10, JP11, JP12, JP13: PINHD-1X1; 1X01
S1, S2, S3, S4: TAC_SWITCHPTH; TACTILE-PTH

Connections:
GND: JP1.1, JP6.1, JP10.1, S1.3, S1.4, S2.3, S2.4, S3.3, S3.4, S4.3, S4.4
unnamed: JP2.1, S1.1, S1.2
unnamed: JP3.1, S2.1, S2.2
unnamed: JP4.1, S3.1, S3.2
unnamed: JP5.1, S4.1, S4.2
unnamed: JP7.1, JP11.1
unnamed: JP8.1, JP12.1
unnamed: JP9.1, JP13.1

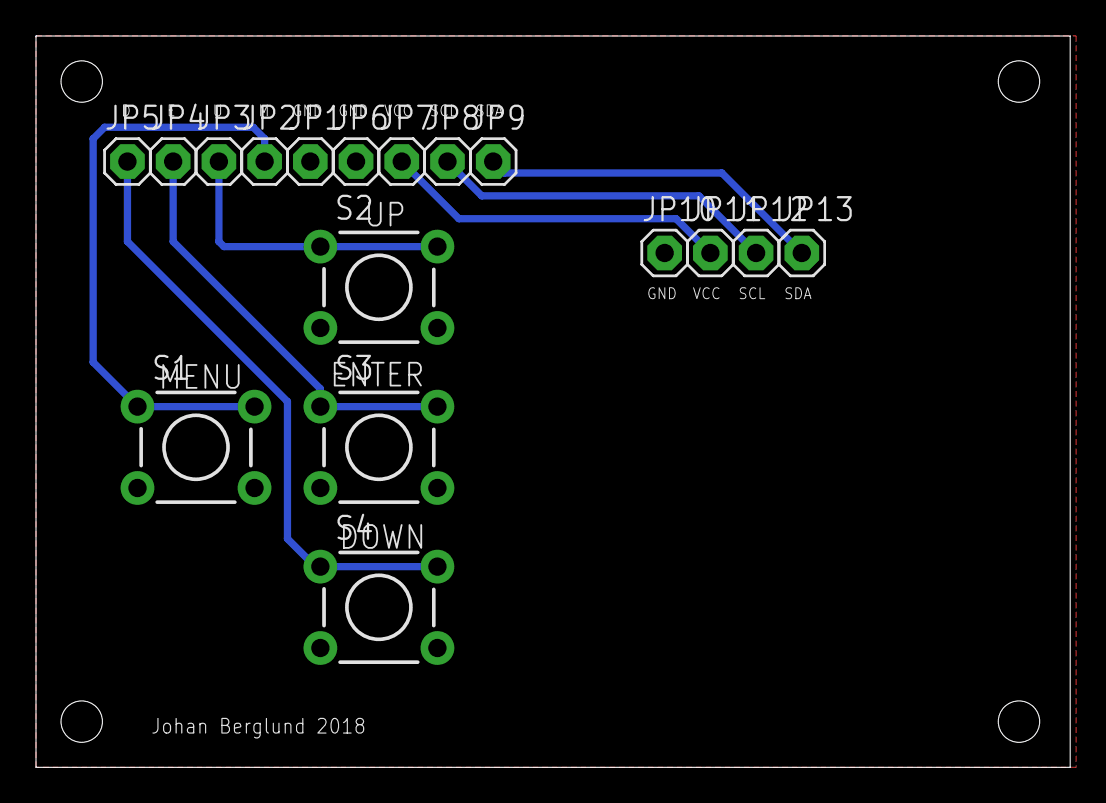
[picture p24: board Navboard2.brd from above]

Board: 2 copper layers, 57.5 x 40.6 mm, 17 parts (0 on the bottom side), 8 nets.

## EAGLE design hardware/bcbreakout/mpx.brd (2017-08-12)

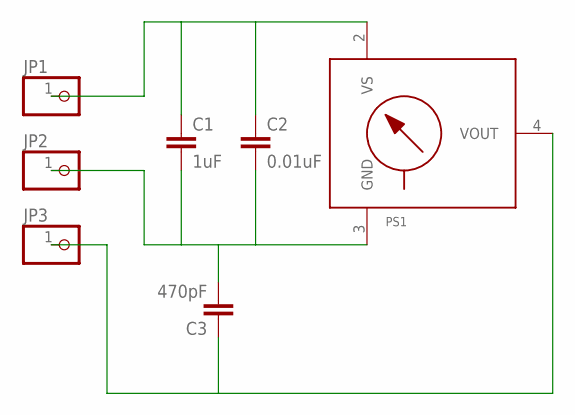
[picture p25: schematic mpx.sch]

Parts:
C1: 1uF; C050-024X044
C2: 0.01uF; C050-024X044
C3: 470pF; C050-024X044
JP1, JP2, JP3: PINHD-1X1; 1X01
PS1: MPX-1369; 1369

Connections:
GND: C1.2, C2.2, C3.2, JP2.1, PS1.3 (GND)
unnamed: C3.1, JP3.1, PS1.4 (VOUT)
unnamed: C1.1, C2.1, JP1.1, PS1.2 (VS)

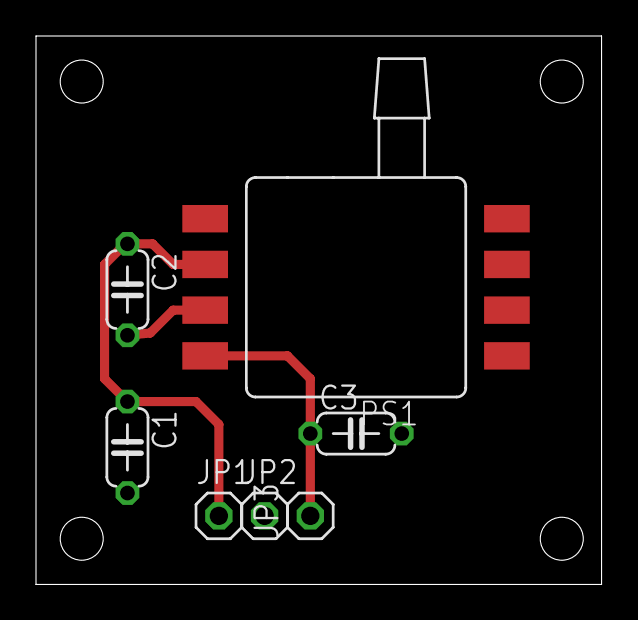
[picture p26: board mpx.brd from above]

Board: 2 copper layers, 31.4 x 30.5 mm, 7 parts (0 on the bottom side), 3 nets.

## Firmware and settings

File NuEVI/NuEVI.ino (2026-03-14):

#include <Wire.h>
#include <Adafruit_MPR121.h>
#include <SPI.h>
#include <EEPROM.h>

#include "FilterOnePole.h"  // for the breath signal low-pass filtering, from https://github.com/JonHub/Filters
#include "globals.h"
#include "hardware.h"
#include "midi.h"
#include "menu.h"
#include "config.h"
#include "settings.h"
#include "led.h"

/*
NAME:                 NuEVI
WRITTEN BY:           JOHAN BERGLUND
DATE:                 2018-04-19
FILE SAVED AS:        NuEVI.ino
FOR:                  PJRC Teensy 3.2 and a MPR121 capactive touch sensor board.
                      Uses an SSD1306 controlled OLED display communicating over I2C.
PROGRAMME FUNCTION:   EVI Wind Controller using the Freescale MP3V5004GP breath sensor
                      and capacitive touch keys. Output to both USB MIDI and DIN MIDI.

*/

/*
but hey, it's also...

NAME:                 NuRAD
WRITTEN BY:           JOHAN BERGLUND
DATE:                 2019-08-09
FILE SAVED AS:        n/a
FOR:                  PJRC Teensy 3.2 and three MPR121 capactive touch sensor boards.
                      Uses an SSD1306 controlled OLED display communicating over I2C.
PROGRAMME FUNCTION:   EWI Wind Controller using the Freescale MP3V5004GP breath sensor
                      and capacitive touch keys. Output to both USB MIDI and DIN MIDI.

...if you just uncomment the #define NURAD in hardware.h
*/


//Make sure compiler is set to the appropriate platform
#if !defined(__MK20DX256__) && !defined(__IMXRT1062__)
  #error "Wrong target platform. Please set to Teensy 3.1/3.2 (MK20DX256) or Teensy 4.0 (IMXRT1062)."
#endif

#if !defined(USB_MIDI) && !defined(USB_MIDI_SERIAL)
  #error "USB MIDI not enabled. Please set USB type to 'MIDI' or 'Serial + MIDI'."
#endif



//_______________________________________________________________________________________________ DECLARATIONS

//variables setup

unsigned short breathThrVal;// = 350;
unsigned short breathMaxVal;// = 1000;
unsigned short portamThrVal;// = 1730;
unsigned short portamMaxVal;// = 3300;
unsigned short pitchbThrVal;// = 1200;
unsigned short pitchbMaxVal;// = 2400;
unsigned short extracThrVal;// = 1200;
unsigned short extracMaxVal;// = 2400;
unsigned short ctouchThrVal;// = 120;
unsigned short leverThrVal;
unsigned short leverMaxVal;
unsigned short transpose;
unsigned short MIDIchannel;
unsigned short breathCC;  // OFF:MW:BR:VL:EX:MW+:BR+:VL+:EX+:CF
unsigned short breathCC2;  // OFF:1-127
unsigned short breathCC2Rise;  // 1X:2X:3X:4X:5X
unsigned short breathAT;
unsigned short velocity;
unsigned short portamento;// switching on cc65? just cc5 enabled? SW:ON:OFF
unsigned short portLimit; // 0-127
unsigned short portLoLimit; // 0-127
unsigned short PBdepth;   // OFF:1-12 divider
unsigned short extraCT;   // OFF:MW:FP:CF:SP
unsigned short vibrato;   // OFF:1-9
unsigned short deglitch;  // 0-70 ms in steps of 5
unsigned short patch;     // 1-128
unsigned short octave;
unsigned short curve;
unsigned short velSmpDl;  // 0-30 ms
unsigned short velBias;   // 0-9
unsigned short pinkySetting; // 0 - 11 (QuickTranspose -12 to -1), 12 (pb/2), 13 - 24 (QuickTranspose +1 to +12), 25 (EC2), 26 (ECSW), 27 (LVL), 28 (LVLP)
unsigned short dipSwBits; // virtual dip switch settings for special modes (work in progress)
unsigned short priority; // mono priority for rotator chords
unsigned short extraSrc;   // LIP:GLS
unsigned short extraCT2; // OFF:1-127
unsigned short levelCC; // 0-127
unsigned short levelVal; // 0-127
unsigned short fingering; // 0-4 EWI,EWX,SAX,EVI,EVR
unsigned short rollerMode; //0-2
unsigned short lpinky3; // 0-25 (OFF, -12 - MOD - +12)
unsigned short batteryType; // 0-2 ALK,NIM,LIP
unsigned short harmSetting; // 0-7
unsigned short harmSelect; // 0-5
unsigned short brHarmSetting; // 0-7
unsigned short brHarmSelect; // 0-3
PolySelect polySelect; // OFF, MGR, MGD, MND, MNH, FWC, RTA, RTB or RTC
unsigned short fwcType; // 6, m6, 7, m7
unsigned short fwcLockH; // OFF:ON
unsigned short fwcDrop2; // OFF:ON
unsigned short hmzKey; // 0-11 (0 is C)
unsigned short hmzLimit; // 2-5
unsigned short otfKey; //OFF:ON
unsigned short breathInterval = 6; // 3-15

unsigned short vibSens = 2; // vibrato sensitivity
unsigned short vibRetn = 2; // vibrato return speed
unsigned short vibSquelch = 12; //vibrato signal squelch
unsigned short vibDirection = DNWD; //direction of first vibrato wave UPWD or DNWD
unsigned short vibSensBite = 2; // vibrato sensitivity (bite)
unsigned short vibSquelchBite = 12; //vibrato signal squelch (bite)
unsigned short vibControl = 0;
unsigned short biteControl = 0; // OFF, VIB, GLD, CC
unsigned short leverControl = 0; // OFF, VIB, GLD, CC
unsigned short stripControl = 0; // OFF, GLD, CC
unsigned short biteCC = 0; // 0 - 127
unsigned short leverCC = 0; // 0 -127
unsigned short stripCC = 0; // 0 -127

unsigned short cvTune;  // 1 - 199 representing -99 to +99 in menu (offset of 100 to keep postitive)
unsigned short cvScale; // 1 - 199 representing -99 to +99 in menu (offset of 100 to keep postitive)
unsigned short cvVibRate; // OFF, 1 - 8 CV extra controller LFO vibrato rate 4.5Hz to 8Hz

unsigned short fastPatch[7] = {0,0,0,0,0,0,0};
unsigned short fastPatchEnable = 0;

uint16_t bcasMode; //Legacy CASSIDY compile flag
uint16_t trill3_interval;
uint16_t fastBoot;
uint16_t dacMode;

byte rotatorOn = 0;
byte currentRotation = 3;

Rotator rotations_a;
Rotator rotations_b;
Rotator rotations_c;

byte gateOpen = 0; // setting for gate always open, note on sent for every time fingering changes, no matter the breath status
uint16_t gateOpenEnable = 0;

uint16_t specialKeyEnable = 0;

int touch_Thr = 1300;
int patchKeyThrEVI = 0;
int lockGlideKeyThr = 0;

byte ccList[11] = {0,1,2,7,11,1,2,7,11,74,20};  // OFF, Modulation, Breath, Volume, Expression (then same sent in hires), CC74 (cutoff/brightness), CC20 (UNO Cutoff)

int pbDepthList[13] = {8192,8192,4096,2731,2048,1638,1365,1170,1024,910,819,744,683};

#if defined(NURAD)
#if defined(SEAMUS)
int calOffsetRollers[6] = {-70,20,20,20,20,120};
int calOffsetRH[12] = {0,0,0,0,0,-50,121,0,0,50,0,120};
int calOffsetLH[12] = {120,0,120,0,50,115,118,0,50,0,0,0};
#else
int calOffsetRollers[6] = {16,10,8,21,24,41};
int calOffsetRH[12] = {-88,-68,-31,13,4,120,121,-68,-85,-34,23,87};
int calOffsetLH[12] = {90,-13,-33,-93,-82,115,118,2,4,-40,-75,-94};
#endif
#endif
#if defined(EVIR2)
int calOffsetRollers[12] = {0,0,0,0,0,0,-120,-120,-120,-120,-120,-120};
int calOffsetRH[12] =      {0,0,0,0,0,0,0,0,0,0,0,0};
#endif

int battMeasured[50];
int battAvg = 0;
byte battCheckPos = 0;

// the following variables are unsigned longs because the time, measured in
// milliseconds, will quickly become a bigger number than can be stored in an int.

static unsigned long pixelUpdateTime = 0;
static const unsigned long pixelUpdateInterval = 80;

unsigned long lastDeglitchTime = 0;         // The last time the fingering was changed
unsigned long ccSendTime = 0L;              // The last time we sent CC values
unsigned long ccSendTime2 = 0L;             // The last time we sent CC values 2 (slower)
unsigned long ccSendTime3 = 0L;             // The last time we sent CC values 3 (and slower)
unsigned long cvpTrigTime = 0L;
unsigned long lvlTime = 0L;
unsigned long ccBreathSendTime = 0L;        // The last time we sent breath CC values
unsigned long breath_on_time = 0L;          // Time when breath sensor value went over the ON threshold
unsigned long currentTime;
unsigned long glideLockDeglitchTime = 0L;

int lastFingering = 0;             // Keep the last fingering value for debouncing

int mainState;                         // The state of the main state machine

int initial_breath_value;          // The breath value at the time we observed the transition

byte activeMIDIchannel;          // MIDI channel
byte activePatch=0;
byte doPatchUpdate=0;

byte cvPortaTuneCount = 0;
byte cvpTrig = 0;

uint16_t legacy = 0;
uint16_t legacyBrAct = 0;
byte halfTime = 0;
boolean programonce = false;
boolean oneroll;
boolean glideLockOnce;
boolean glideLockOn;
boolean lastlockGlideKey;
byte widiOn = 0;

int breathLevel=0;   // breath level (smoothed) not mapped to CC value
int oldbreath=0;
int oldbreathcc2=0;
unsigned int oldbreathhires=0;
float filterFreq = 30.0;
float piezoFilterFreq = 6.0;
int piezoSens = 20;
int piezoSquelch = 5;
int piezoVib = 0;

 int allPiezo = 1;

float filterVal = 0.15;
float smoothedVal;
int pressureSensor;  // pressure data from breath sensor, for midi breath cc and breath threshold checks
int lastPressure;
byte velocitySend;   // remapped midi velocity from breath sensor (or set to static value if selected)
int breathCalZero;

int leverPortZero;
#if defined(NURAD)
int leverPortThr = 70;
#else
int leverPortThr = 70;
#endif
int leverPortRead;
int stripRead;
int center;

int biteSensor=0;    // capacitance data from bite sensor, for midi cc and threshold checks
byte portIsOn=0;     // keep track and make sure we send CC with 0 value when off threshold
int oldport=0;
int finalPortCC=0;
int lastBite=0;
byte biteJumper=0;
byte widiJumper=0;
int oldbitecc=0;
int oldlevercc=0;
int oldstripcc=0;

int cvPitch;
int cvPitchSum;
int targetPitch;

int exSensor=0;
int exSensor2=0;
int exSensorUse=0;
int exSensorIndicator=0;
byte extracIsOn=0;
int oldextrac=0;
int oldextrac2=0;

int harmonics = 0;
int brHarmonics = 0;

long pitchBend=8192;
int pbSend=8192;
int oldpb=8192;
int vibSignal=0;
int pbUp=0;
int pbDn=0;
byte vibLedOff = 0;
byte oldpkey = 0;

byte lap = 0;
byte rSum = 0;

static const float vibDepth[10] = {0,0.05,0.1,0.15,0.2,0.25,0.3,0.35,0.40,0.45}; // max pitch bend values (+/-) for the vibrato settings
static const short vibMaxBiteList[17] = {1600,1400,1200,1000,900,800,700,600,500,400,300,250,200,150,100,50,25};
static const short vibMaxList[12] = {300,275,250,225,200,175,150,125,100,75,50,25};
static const int timeDividerList[9] = {0, 222, 200, 181, 167, 152, 143, 130, 125}; // For CV vibrato - 222 is 4.5Hz, 200 is 5Hz, 181 is 5.5Hz 167 is 6Hz, 152 is 6.5Hz, 143 is 7Hz, 130 is 7.5Hz, 125 is 8Hz

static const unsigned short curveM4[] = {0,4300,7000,8700,9900,10950,11900,12600,13300,13900,14500,15000,15450,15700,16000,16250,16383};
static const unsigned short curveM3[] = {0,2900,5100,6650,8200,9500,10550,11500,12300,13100,13800,14450,14950,15350,15750,16150,16383};
static const unsigned short curveM2[] = {0,2000,3600,5000,6450,7850,9000,10100,11100,12100,12900,13700,14400,14950,15500,16000,16383};
static const unsigned short curveM1[] = {0,1400,2850,4100,5300,6450,7600,8700,9800,10750,11650,12600,13350,14150,14950,15650,16383};
const unsigned short curveIn[] = {0,1023,2047,3071,4095,5119,6143,7167,8191,9215,10239,11263,12287,13311,14335,15359,16383};
static const unsigned short curveP1[] = {0,600,1350,2150,2900,3800,4700,5600,6650,7700,8800,9900,11100,12300,13500,14850,16383};
static const unsigned short curveP2[] = {0,400,800,1300,2000,2650,3500,4300,5300,6250,7400,8500,9600,11050,12400,14100,16383};
static const unsigned short curveP3[] = {0,200,500,900,1300,1800,2350,3100,3800,4600,5550,6550,8000,9500,11250,13400,16383};
static const unsigned short curveP4[] = {0,100,200,400,700,1050,1500,1950,2550,3200,4000,4900,6050,7500,9300,12100,16383};
static const unsigned short curveS1[] = {0,600,1350,2150,2900,3800,4700,6000,8700,11000,12400,13400,14300,14950,15500,16000,16383};
static const unsigned short curveS2[] = {0,600,1350,2150,2900,4000,6100,9000,11000,12100,12900,13700,14400,14950,15500,16000,16383};
//static const unsigned short curveS3[] = {0,600,1350,2300,3800,6200,8700,10200,11100,12100,12900,13700,14400,14950,15500,16000,16383};
//static const unsigned short curveS4[] = {0,600,1700,4000,6600,8550,9700,10550,11400,12200,12900,13700,14400,14950,15500,16000,16383};

static const unsigned short curveZ1[] = {0,1400,2100,2900,3200,3900,4700,5600,6650,7700,8800,9900,11100,12300,13500,14850,16383};
static const unsigned short curveZ2[] = {0,2000,3200,3800,4096,4800,5100,5900,6650,7700,8800,9900,11100,12300,13500,14850,16383};

const unsigned short* const curves[] = {
   curveM4, curveM3, curveM2, curveM1, curveIn, curveP1, curveP2,
   curveP3, curveP4 , curveS1, curveS2, curveZ1, curveZ2
};

// NuRAD Sax fingering
// LH1, LHb, LH2, LH3, LHp1, -LHp2-, -RHs-, RH1, RH2, RH3, RHp1, -RHp2-, RHp3  -excluded- LHp2 always -1, RHs always +1, RHp2 disabled
// 0 = not touched, 1 = touched, 2 = whatever

const byte saxFingerMatch[16][10] =
{
  {1, 2, 1, 1, 0, 1, 1, 1, 2, 1}, // C (-13 semis)
  {1, 2, 1, 1, 1, 1, 1, 1, 2, 1}, // C# (-12 semis)
  {1, 2, 1, 1, 2, 1, 1, 1, 0, 0}, // D (-11 semis)
  {1, 2, 1, 1, 2, 1, 1, 1, 1, 0}, // D# (-10 semis)
  {1, 2, 1, 1, 2, 1, 1, 0, 2, 2}, // E (-9 semis)
  {1, 2, 1, 1, 2, 1, 0, 2, 2, 2}, // F (-8 semis)
  {1, 2, 1, 1, 2, 0, 1, 2, 2, 2}, // F# (-7 semis)
  {1, 2, 1, 1, 0, 0, 0, 2, 2, 2}, // G (-6 semis)
  {1, 2, 1, 1, 1, 0, 0, 2, 2, 2}, // G# (-5 semis)
  {1, 2, 1, 0, 2, 2, 2, 2, 2, 2}, // A (-4 semis)
  {1, 2, 0, 2, 2, 1, 2, 2, 2, 2}, // A# (-3 semis) RH1 for Bb
  {1, 2, 0, 2, 2, 2, 1, 2, 2, 2}, // A# (-3 semis) RH2 for Bb
  {1, 1, 0, 2, 2, 2, 2, 2, 2, 2}, // A# (-3 semis) bis for Bb
  {1, 0, 0, 2, 2, 0, 2, 2, 2, 2}, // B (-2 semis)
  {0, 2, 1, 2, 2, 2, 2, 2, 2, 2}, // C (-1 semis)
  {0, 2, 0, 2, 2, 2, 2, 2, 2, 2}, // C# (-0 semis)
};

static int waveformsTable[maxSamplesNum] = {
  // Sine wave
  0x7ff, 0x86a, 0x8d5, 0x93f, 0x9a9, 0xa11, 0xa78, 0xadd, 0xb40, 0xba1,
  0xbff, 0xc5a, 0xcb2, 0xd08, 0xd59, 0xda7, 0xdf1, 0xe36, 0xe77, 0xeb4,
  0xeec, 0xf1f, 0xf4d, 0xf77, 0xf9a, 0xfb9, 0xfd2, 0xfe5, 0xff3, 0xffc,
  0xfff, 0xffc, 0xff3, 0xfe5, 0xfd2, 0xfb9, 0xf9a, 0xf77, 0xf4d, 0xf1f,
  0xeec, 0xeb4, 0xe77, 0xe36, 0xdf1, 0xda7, 0xd59, 0xd08, 0xcb2, 0xc5a,
  0xbff, 0xba1, 0xb40, 0xadd, 0xa78, 0xa11, 0x9a9, 0x93f, 0x8d5, 0x86a,
  0x7ff, 0x794, 0x729, 0x6bf, 0x655, 0x5ed, 0x586, 0x521, 0x4be, 0x45d,
  0x3ff, 0x3a4, 0x34c, 0x2f6, 0x2a5, 0x257, 0x20d, 0x1c8, 0x187, 0x14a,
  0x112, 0xdf, 0xb1, 0x87, 0x64, 0x45, 0x2c, 0x19, 0xb, 0x2,
  0x0, 0x2, 0xb, 0x19, 0x2c, 0x45, 0x64, 0x87, 0xb1, 0xdf,
  0x112, 0x14a, 0x187, 0x1c8, 0x20d, 0x257, 0x2a5, 0x2f6, 0x34c, 0x3a4,
  0x3ff, 0x45d, 0x4be, 0x521, 0x586, 0x5ed, 0x655, 0x6bf, 0x729, 0x794
};

int saxFingerResult[16] =
{-13, -12, -11, -10, -9, -8, -7, -6, -5, -4, -3, -3, -3, -2, -1, 0};

byte saxFinger[10];
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
void loop() {

  //If in config mgmt loop, do that and nothing else
  if(configManagementMode) {
    configModeLoop();
    return;
  }

  breathFilter.input(analogRead(breathSensorPin));
  pressureSensor = constrain((int) breathFilter.output(), 0, 4095); // Get the filtered pressure sensor reading from analog pin A0, input from sensor MP3V5004GP
  readSwitches();
  if (mainState == NOTE_OFF) {
    if (activeMIDIchannel != MIDIchannel) {
      activeMIDIchannel = MIDIchannel; // only switch channel if no active note
      midiSetChannel(activeMIDIchannel);
    }
    if ((activePatch != patch) && doPatchUpdate) {
      activePatch = patch;
      midiSendProgramChange(activePatch);
      slurSustain = 0;
      parallelChord = 0;
      subOctaveDouble = 0;
      doPatchUpdate = 0;
    }
    if ((pressureSensor > breathThrVal) || gateOpen) {
      // Value has risen above threshold. Move to the RISE_WAIT
      // state. Record time and initial breath value.
      breath_on_time = millis();
      initial_breath_value = pressureSensor;
      mainState = RISE_WAIT; // Go to next state
    }
    if (legacy || legacyBrAct) {
      #if defined(LITE)
      bool patchKeyEVI = 0;
      bool lockGlideKey = 0;
      #elif defined(EVIR2)
      bool patchKeyEVI = patchKey;
      bool lockGlideKey = 0;
      #else
      bool patchKeyEVI = touchRead(patchPinEVI) > patchKeyThrEVI;
      bool lockGlideKey = touchRead(lockGlidePin) > lockGlideKeyThr;
      #endif
      bool bothPB = (pbUp > ((pitchbMaxVal + pitchbThrVal) / 2)) && (pbDn > ((pitchbMaxVal + pitchbThrVal) / 2));
      bool justPbDn = !(pbUp > ((pitchbMaxVal + pitchbThrVal) / 2)) && (pbDn > ((pitchbMaxVal + pitchbThrVal) / 2));
      bool justPbUp = (pbUp > ((pitchbMaxVal + pitchbThrVal) / 2)) && !(pbDn > ((pitchbMaxVal + pitchbThrVal) / 2));
      bool noPb = !(pbUp > ((pitchbMaxVal + pitchbThrVal) / 2)) && !(pbDn > ((pitchbMaxVal + pitchbThrVal) / 2));
      bool brSuck = analogRead(breathSensorPin) < (breathCalZero - 850);
      int pitchlatchForPatch = patchLimit(pitchlatch + 1);

        if (lockGlideKey != lastlockGlideKey) { //
          // reset the debouncing timer
          glideLockDeglitchTime = millis();
        }
        if ((millis() - glideLockDeglitchTime) > GLIDE_LOCK_DEGLITCH) {
          // whatever the reading is at, it's been there for longer
          // than the debounce delay, so take it as the actual current state
          if (!glideLockOnce && lockGlideKey){
            glideLockOn = !glideLockOn; // toggle glide lock
            glideLockOnce = 1;
          }
          if (!lockGlideKey) glideLockOnce = 0;
        }
        lastlockGlideKey = lockGlideKey;
      
      if (pcCombo1 && (pcCombo1 != lastpcc1)){ // latched note number to patch number, send with K1/K5 combo
        if (patch != pitchlatchForPatch) {
          patch = pitchlatchForPatch;
          doPatchUpdate = 1;
        }
      } else if (pcCombo2 && (pcCombo2 != lastpcc2)) { // hi and lo patch numbers, send with K2/K6 combo
        if (pitchlatch > 75) {
          if (patch != patchLimit(pitchlatchForPatch + 24)) {
            patch = patchLimit(pitchlatchForPatch + 24); // add 24 to get high numbers 108 to 127
            doPatchUpdate = 1;
          }
        } else {
          if (patch != patchLimit(pitchlatchForPatch - 36)) {
            patch = patchLimit(pitchlatchForPatch - 36); // subtract 36 to get low numbers 0 to 36
            doPatchUpdate = 1;
          }
        }
      }
      lastpcc1=pcCombo1;
      lastpcc2=pcCombo2;
      if (
          patchKey ||
          patchKeyEVI ||
          (bothPB && legacy) ||
          (brSuck && legacyBrAct && justPbUp) ||
          (brSuck && legacyBrAct && bcasMode && noPb)
          ) { // both pb pads touched or br suck


        int fingeredNoteUntransposedForPatch = patchLimit(fingeredNoteUntransposed + 1);
        if (exSensorUse >= ((extracThrVal + extracMaxVal) / 2)) { // instant midi setting
          if ((fingeredNoteUntransposedForPatch >= 73) && (fingeredNoteUntransposedForPatch <= 88)) {
            MIDIchannel = fingeredNoteUntransposedForPatch - 72; // Mid C and up
          }
        } else {
          if (!pinkyKey) { // note number to patch number
            if (patch != fingeredNoteUntransposedForPatch) {
              patch = fingeredNoteUntransposedForPatch;
              doPatchUpdate = 1;
            }
          } else { // hi and lo patch numbers
            if (fingeredNoteUntransposedForPatch > 75) {
              if (patch != patchLimit(fingeredNoteUntransposedForPatch + 24)) {
                patch = patchLimit(fingeredNoteUntransposedForPatch + 24); // add 24 to get high numbers 108 to 127
                doPatchUpdate = 1;
              }
            } else {
              if (patch != patchLimit(fingeredNoteUntransposedForPatch - 36)) {
                patch = patchLimit(fingeredNoteUntransposedForPatch - 36); // subtract 36 to get low numbers 0 to 36
                doPatchUpdate = 1;
              }
            }
          }
        }
      } else {
        if (justPbDn && legacyBrAct && brSuck && programonce == false) { // down bend for suck programming button
          programonce = true;

          if (octaveR == 0) { //lowest octave position

            if (K1 && K2 && !K3 && K4) { //  e28 send patch change -10
              patch = patch - 10;
              doPatchUpdate = 1;
            } else if (K1 && !K2 && !K3 && K4) { //f29 decrement and send patch change
              patch--;
              doPatchUpdate = 1;
            } else if (!K1 && K2 && !K3 && K4) { //f#30 send patch change +10
              patch = patch + 10;
              doPatchUpdate = 1;
            } else if (!K1 && !K2 && !K3 && K4) { //g31 increment and send patch change
              patch++;
              doPatchUpdate = 1;
            }

            if (!K1 && !K2 && K3 && !K4) { //send reverb pitchlatch value
              reverb = ((pitchlatch - 36) * 2);
              reverb = constrain(reverb, 0, 127);

              midiSendControlChange(91, reverb);
            }
          }

          if (octaveR == 3) { //middle octave position to set breath parameters
            // breathCC value is from cclist[] which assigns controller number
            if (K1) { //turn on midi volume
              breathCC = 3;
              midiSendControlChange(7, 0); //midi vol to 0
              midiSendControlChange(11, 127); //midi expression to 127
            }
            if (K3) { //turn on midi breath controller
              breathCC = 2;
              midiSendControlChange(7, 127); //midi vol to 127
              midiSendControlChange(11, 127); //midi expression to 127
            }
            if (K4) { //sb turn on midi expression
              breathCC = 4;
              midiSendControlChange(7, 127); //midi vol to 127
              midiSendControlChange(11, 0); //midi expression to 0
            }
            if (K2) { //2v turn on aftertouch
              breathAT = 1;
              midiSendControlChange(7, 127); //midi vol to 127
              midiSendControlChange(11, 127); //midi expression to 0
            } else {
              breathAT = 0;
            }
            if (K5) { //1tr turn on velocity
              velocity = 0;
              midiSendControlChange(7, 127); //midi vol to 127
              midiSendControlChange(11, 127); //midi expression to 0
            } else {
              velocity = 127;
            }
            if (!K1 && !K3 && !K4) {
              breathCC = 0;
              midiSendControlChange(7, 127); //midi vol to 127
              midiSendControlChange(11, 127); //midi expression to 127
            }
          }
        }
      }
    }
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

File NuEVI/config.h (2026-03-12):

#ifndef __CONFIG_H
#define __CONFIG_H


// Compile options, comment/uncomment to change

#define FIRMWARE_VERSION "1.6.7"    // FIRMWARE VERSION NUMBER HERE <<<<<<<<<<<<<<<<<<<<<<<

#define ON_Delay   20   // Set Delay after ON threshold before velocity is checked (wait for tounging peak)
#define CCN_Port 5      // Controller number for portamento level
#define CCN_PortOnOff 65// Controller number for portamento on/off
#define CCN_PortSE02 9  // Controller number for portamento type on Roland SE-02

// Send breath CC data no more than every CC_BREATH_INTERVAL 
// milliseconds
#define CC_BREATH_INTERVAL 5
#define SLOW_MIDI_ADD 7
#define CC_INTERVAL 9
#define CC_INTERVAL2 13
#define CC_INTERVAL3 37
#define CVP_INTERVAL 5
#define LVL_TIMER_INTERVAL 15
#define GLIDE_LOCK_DEGLITCH 40


#define maxSamplesNum 120

#define breathLoLimit   0
#define breathHiLimit   4095
#define portamLoLimit   700
#define portamHiLimit   4700
#define pitchbLoLimit   500
#define pitchbHiLimit   4000
#define extracLoLimit   500
#define extracHiLimit   4000
#define ctouchLoLimit   50
#define ctouchHiLimit   350
#define ttouchLoLimit   50
#define ttouchHiLimit   1900
#define leverLoLimit    1400
#define leverHiLimit    2000

#define hackyTouchOffset 500

#define MIN_LED_BRIGHTNESS    5   // lowest PWM value that still is visible
#define BREATH_LED_BRIGHTNESS 600 // up to 4095, PWM
#define PORTAM_LED_BRIGHTNESS 300 // up to 4095, PWM
#define EXTCON_LED_BRIGHTNESS 500 // up to 4095, PWM
#define SPCKEY_LED_BRIGHTNESS 3000 // up to 4095, PWM

#define ALK_BAT_FULL 2800 // about 4.6V
#define NMH_BAT_FULL 2380 // about 3.9V
#define LIP_BAT_FULL 2530 // about 4.2V
#define ALK_BAT_LOW 2300  // about 3.8V
#define NMH_BAT_LOW 2200  // about 3.6V
#define LIP_BAT_LOW 2250  // about 3.7V


#endif

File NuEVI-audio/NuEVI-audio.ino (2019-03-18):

#include <Wire.h>
#include <Adafruit_MPR121.h>
#include <SPI.h>
#include <EEPROM.h>
#include <Adafruit_GFX.h>
#include <Adafruit_SSD1306.h>
#include <Filters.h>  // for the breath signal LP filtering, https://github.com/edgar-bonet/Filters
#include <Audio.h>
#include <SD.h>
#include <SerialFlash.h>

/*
NAME:                 NuEVI
WRITTEN BY:           JOHAN BERGLUND
DATE:                 2018-04-19
FILE SAVED AS:        NuEVI.ino
FOR:                  PJRC Teensy 3.2 and a MPR121 capactive touch sensor board.
                      Uses an SSD1306 controlled OLED display communicating over I2C.
PROGRAMME FUNCTION:   EVI Wind Controller using the Freescale MP3V5004GP breath sensor
                      and capacitive touch keys. Output to both USB MIDI and DIN MIDI.  
  
*/

//_______________________________________________________________________________________________ DECLARATIONS

// Compile options, comment/uncomment to change

#define REVB


// Pin definitions

// Teensy pins

#define specialKeyPin 0       // SK or S2
#define halfPitchBendKeyPin 1 // PD or S1

#define bitePin 17
#define extraPin 16
#define pbUpPin 23
#define pbDnPin 22
#define vibratoPin 15

#define dPin 3
#define ePin 4
#define uPin 5
#define mPin 6

#define bLedPin 10
#define pLedPin 9 

#define vMeterPin A11

#define PBD 12

#if defined(REVB)

// MPR121 pins Rev B (angled pins at top edge for main keys and rollers)

#define R1Pin 0
#define R2Pin 2
#define R3Pin 4
#define R4Pin 6
#define R5Pin 8

#define K4Pin 10
#define K1Pin 1
#define K2Pin 3
#define K3Pin 5
#define K5Pin 7
#define K6Pin 9
#define K7Pin 11

/*
 *    PINOUT ON PCB vs PINS ON MPR121 - Rev. B
 * 
 *    (R1)  (R2) (R3/6) (R4)  (R5)  (K4)  <-> (00)  (02)  (04)  (06)  (08)  (10)
 * 
 *    (K1)  (K2)  (K3)  (K5)  (K6)  (K7)  <-> (01)  (03)  (05)  (07)  (09)  (11)
 * 
 */
 
# else

// MPR121 pins Rev A (upright pins below MPR121 for main keys and rollers)

#define R1Pin 10
#define R2Pin 11
#define R3Pin 8
#define R4Pin 9
#define R5Pin 6

#define K4Pin 7
#define K1Pin 4
#define K2Pin 5
#define K3Pin 2
#define K5Pin 3
#define K6Pin 0
#define K7Pin 1

/*
 *    PINOUT ON PCB vs PINS ON MPR121 - Rev. A
 * 
 *    (R2)  (R4)  (K4)  (K2)  (K5)  (K7)  <-> (11)  (09)  (07)  (05)  (03)  (01)
 * 
 *    (R1) (R3/6) (R5)  (K1)  (K3)  (K6)  <-> (10)  (08)  (06)  (04)  (02)  (00)
 * 
 */
 
#endif

#define ON_Delay   20   // Set Delay after ON threshold before velocity is checked (wait for tounging peak)
#define touch_Thr 1200  // sensitivity for Teensy touch sensors
#define CCN_Port 5      // Controller number for portamento level
#define CCN_PortOnOff 65// Controller number for portamento on/off


// Send CC data no more than every CC_INTERVAL
// milliseconds
#define CC_INTERVAL 5 


// The three states of our main state machine

// No note is sounding
#define NOTE_OFF 1

// We've observed a transition from below to above the
// threshold value. We wait a while to see how fast the
// breath velocity is increasing
#define RISE_WAIT 2

// A note is sounding
#define NOTE_ON 3


//display states
#define DISPLAYOFF_IDL 0
#define MAIN_MENU 1
#define PATCH_VIEW 2
#define BREATH_ADJ_IDL 10
#define BREATH_ADJ_THR 11
#define BREATH_ADJ_MAX 12
#define PORTAM_ADJ_IDL 20
#define PORTAM_ADJ_THR 21
#define PORTAM_ADJ_MAX 22
#define PITCHB_ADJ_IDL 30
#define PITCHB_ADJ_THR 31
#define PITCHB_ADJ_MAX 32
#define EXTRAC_ADJ_IDL 40
#define EXTRAC_ADJ_THR 41
#define EXTRAC_ADJ_MAX 42
#define VIBRAT_ADJ_IDL 50
#define VIBRAT_ADJ_THR 51
#define VIBRAT_ADJ_DPT 52
#define CTOUCH_ADJ_IDL 60
#define CTOUCH_ADJ_THR 61
#define SETUP_BR_MENU 80
#define SETUP_CT_MENU 90
#define ROTATOR_MENU 100
#define SYNTH_MENU 110

// EEPROM addresses for settings
#define VERSION_ADDR 0
#define BREATH_THR_ADDR 2
#define BREATH_MAX_ADDR 4
#define PORTAM_THR_ADDR 6
#define PORTAM_MAX_ADDR 8
#define PITCHB_THR_ADDR 10
#define PITCHB_MAX_ADDR 12
#define TRANSP_ADDR 14
#define MIDI_ADDR 16
#define BREATH_CC_ADDR 18
#define BREATH_AT_ADDR 20
#define VELOCITY_ADDR 22
#define PORTAM_ADDR 24
#define PB_ADDR 26
#define EXTRA_ADDR 28
#define VIBRATO_ADDR 30
#define DEGLITCH_ADDR 32
#define EXTRAC_THR_ADDR 34
#define EXTRAC_MAX_ADDR 36
#define PATCH_ADDR 38
#define OCTAVE_ADDR 40
#define CTOUCH_THR_ADDR 42
#define BREATHCURVE_ADDR 44
#define VEL_SMP_DL_ADDR 46
#define VEL_BIAS_ADDR 48
#define PINKY_KEY_ADDR 50
#define FP1_ADDR 52
#define FP2_ADDR 54
#define FP3_ADDR 56
#define FP4_ADDR 58
#define FP5_ADDR 60
#define FP6_ADDR 62
#define FP7_ADDR 64
#define DIPSW_BITS_ADDR 66
#define PARAL_ADDR 68
#define ROTN1_ADDR 70
#define ROTN2_ADDR 72
#define ROTN3_ADDR 74
#define ROTN4_ADDR 76
#define PRIO_ADDR 78

//"factory" values for settings
#define VERSION 28
#define BREATH_THR_FACTORY 1400
#define BREATH_MAX_FACTORY 4000
#define PORTAM_THR_FACTORY 2600
#define PORTAM_MAX_FACTORY 3300
#define PITCHB_THR_FACTORY 1400
#define PITCHB_MAX_FACTORY 2300
#define EXTRAC_THR_FACTORY 1200
#define EXTRAC_MAX_FACTORY 2400
#define TRANSP_FACTORY 12   // 12 is 0 transpose
#define MIDI_FACTORY 1      // 1-16
#define BREATH_CC_FACTORY 2 //thats CC#2, see ccList
#define BREATH_AT_FACTORY 0 //aftertouch default off
#define VELOCITY_FACTORY 0  // 0 is dynamic/breath controlled velocity
#define PORTAM_FACTORY 2    // 0 - OFF, 1 - ON, 2 - SW 
#define PB_FACTORY 1        // 0 - OFF, 1 - 12
#define EXTRA_FACTORY 2     // 0 - OFF, 1 - Modulation wheel, 2 - Foot pedal, 3 - Filter Cutoff, 4 - Sustain pedal
#define VIBRATO_FACTORY 4   // 0 - OFF, 1 - 9 depth
#define DEGLITCH_FACTORY 20 // 0 - OFF, 5 to 70 ms in steps of 5
#define PATCH_FACTORY 1     // MIDI program change 1-128
#define OCTAVE_FACTORY 3    // 3 is 0 octave change
#define CTOUCH_THR_FACTORY 125  // MPR121 touch threshold
#define BREATHCURVE_FACTORY 4 // 0 to 12 (-4 to +4, S1 to S4)
#define VEL_SMP_DL_FACTORY 20 // 0 to 30 ms in steps of 5
#define VEL_BIAS_FACTORY 0  // 0 to 9
#define PINKY_KEY_FACTORY 12 // 0 - 11 (QuickTranspose -12 to -1), 12 (pb/2), 13 - 22 (QuickTranspose +1 to +12)
#define DIPSW_BITS_FACTORY 0 // virtual dip switch settings for special modes (work in progress)
#define PARAL_FACTORY 31 // 7 (+ 24) Rotator parallel
#define ROTN1_FACTORY 19 // -5 (+24) Rotation 1
#define ROTN2_FACTORY 14 // -10 (+24) Rotation 2
#define ROTN3_FACTORY 17 // -7 (+24) Rotation 3
#define ROTN4_FACTORY 10 // -14 (+24) Rotation 4
#define PRIO_FACTORY 0 // Mono priority 0 - BAS(e note), 1 - ROT(ating note)

#define OLED_RESET 4
Adafruit_SSD1306 display(OLED_RESET);
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

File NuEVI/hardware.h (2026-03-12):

#ifndef __HARDWARE_H
#define __HARDWARE_H
#endif

#define REVB
//#define NURAD
//#define SEAMUS
//#define LITE
//#define EVIR2

//#define I2CSCANNER

#if defined(NURAD) //NuRAD <<<<<<<<<<<<<<<<<<<<<<<
#if defined(LITE)  //NuRAD lite

// Pin definitions

// Teensy pins

//Analog pressure sensors. Breath and optional bite
#define breathSensorPin A0
#define bitePressurePin A7

//Digital pins for menu buttons
#define dPin 3
#define ePin 4
#define uPin 5
#define mPin 6

//Output pins for LEDs (breath, power, status)
#define bLedPin 10
#define pLedPin 9
#define eLedPin 22
#define sLedPin 23
#define statusLedPin 13

//DAC outputs for analog and pwm
#define dacPin 1 // PWM on pin 1 for pitch CV

//Pins for WIDI board management
#define widiJumperPin 30
#define widiJumperGndPin 31
#define widiPowerPin 33

//Analog input for measuring voltage
#define vMeterPin A6

//Which serial port to use for MIDI
#define MIDI_SERIAL Serial2
#define WIDI_SERIAL Serial7

// MPR121 Rollers 0x5D

#define rPin1 0
#define rPin2 1
#define rPin3 2
#define rPin4 3
#define rPin5 4
#define rPin6 5

// Lite version replacement pins from roller board
#define extraPin 9
#define pbUpPin 10
#define pbDnPin 8
#define vibratoPin 7 // pad
#define extraPin2 11

#define bitePin 17

// MPR121 RH 0x5C

#define RHsPin 3
#define RH1Pin 4
#define RH2Pin 2
#define RH3Pin 1
#define RHp1Pin 0
#define RHp2Pin 8
#define RHp3Pin 7
#define spec1Pin 10
#define spec2Pin 9
#define patchPin 5

// MPR121 LH 0x5B

#define LHsPin 8
#define LH1Pin 7
#define LHbPin 1
#define LH2Pin 9
#define LH3Pin 10
#define LHp1Pin 11
#define LHp2Pin 3
#define LHp3Pin 4


#else //Regular NuRAD
// Pin definitions

// Teensy pins
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

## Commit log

2017-08-08 First commit. Arduino sketch plus devboard plans.
    [Open EVI.brd, Open EVI.sch]
2017-08-09 Adjustments in vibrato algorithm. Added bite sensor step-by-step pics.
    [NuEVI.ino]
2017-08-09 Added the option to have the vibrato go down first, then up.
    [NuEVI.ino]
2017-08-12 Added Eagle files and gerbers for Freescale pressure sensor breakout board.
    [mpx.brd, mpx.sch]
2017-08-23 Changed top octave roller to share pin with roller 3 like in the original. This allows for K4 pin to be on MPR121 like the other main controls, and leaves free a Teensy touch pin to use for the Extra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
2017-08-29 Bugfixes galore. Added sensor level indicators in sensor adjust settings. Added MIDI note range check with octave repeat.
2017-09-01 New version firmware tested and ready for first full prototypes. Eagle files for the new main pcb added.
    [NuEVI.brd, NuEVI.sch]
2017-09-09 Disabled baseline tracking for the MPR121. Added status LEDs for breath and bite (portamento).
2017-09-11 More work on the vibrato. Fixed sending program change to wrong channel on DIN MIDI. Pitchbend start value fix.
    [NuEVI.ino]
2017-09-16 Breath reading changed from 10 bit to 12 bit. Added hi res midi on cc#1 (mod) and an option to compile with breath CV output on DAC pin. Special key functions implemented (slur sustain, parallel chor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
    [NuEVI.ino]
2017-09-17 Bug fix in storing notes for parallel chord.
    [NuEVI.ino]
2017-09-23 Added: Compile options for Rev A and Rev B PCBs. Bug fixes: Slurred velocity had wrong variable set. Default breath cc was modulation, not breath.
    [NuEVI.ino]
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2017-10-05 Adjusted some curves where values were a bit off. Replaced the S-curves with less dramatic ones. Added a fourth one.
    [NuEVI.ino]
2017-10-25 Fix for initial velocity.
    [NuEVI.ino]
2018-01-09 Changed vibrato amount to follow pitch bend divider setting. Added version number display to splash screen.
    [NuEVI.ino]
2018-02-28 Added battery voltage meter (matched 10K resistors to A11 from AGND and VIN). Added CC#74 as option for extra controller. Added velocity sample delay setting and velocity bias setting. Removed midi p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
    [NuEVI.ino]
2018-03-01 Added BAT LOW display for any voltage below 3.7V. Send inital program change if enter is held during startup.
2018-03-31 Added LP filter for breath signal (instead of prev simple smoothing). More settings för vibrato. Pinky key settings added, now you can use pinky key for quick transpose instead of 1/2 pitch bend.
    [NuEVI.ino]
2018-04-19 Got the more advanced breath signal filtering working. (Still some commented out crap in there from testing/comparing. Just ignore it.) Fixed some errors in curves.
    [NuEVI.ino]
2018-05-18 * New FastPatch function (see user manual for instructions) enables you to store seven patch numbers for instant recall using trill key combos. * Changed the "all notes off" function to do it the rig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
    [NuEVI.ino]
2018-05-25 Added chord rotator function. Added setting for mono voice note during chord play. Minor enhancements in FastPatch functionality. Bug fix for storing AT setting.
    [NuEVI.ino]
2018-07-09 Final NuEVI PCBs, schematics and gerbers added. Improved vibrato (now goes below calibrated zero/dead zone too). Fix for AT breath on/off setting not saved. Added midi controller resets when changing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
    [Navboard2.brd, Navboard2.sch, NuEVI.brd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]
2018-07-31 Added Teensy touch sensors to touch adjustment settings (they had a fixed thr value before). Fix for newer teensyduino versions where pitchbend over USB is changed (compile option in start of code, #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
    [NuEVI.ino]
2018-08-27 New and improved vibrato. Added vibrato menu for setting depth, sensitivity and zero return speed. Added Gate Hold function. Added negative pressure trig for legacy instant settings functionality. Bu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
    [NuEVI.ino]
2018-08-27 Moved the vibrato zeroing to be after checking vibrato. Narrowed deadzone even more (put it in dz variable for easy changing). Removed vibrato menu emtpy items.
    [NuEVI.ino]
2018-09-01 Added item in vibrato menu for setting squelch level for vibrato sensor (noise filtering/dead zone). Added setting for vibrato direction.
    [NuEVI.ino]
2018-09-02 Fixed bug where it didn’t read back the saved settings. Increased number of vibrato sensitivity settings. Included 0 in vibrato return setting, for Nord-like behaviour (no auto zero return). Changed 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
    [NuEVI.ino]
2018-09-02 USB MIDI device name file added. Made breath CC update every CC_INTERVAL, while all others every other.
2018-09-03 Use defines instead of hardcoded pin numbers Also automatic "dangling whitespace" cleanup
2018-09-03 Invert meaning of teensyduino comment
    [NuEVI.ino]
2018-09-03 Refactor factory reset for clarity
    [NuEVI.ino]
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2018-10-23 Version 1.2.8
    Fixes:
    * Pinky latch for Nyle’s additions (missed that one in the merge)
    * Pitch bend adding/subtracting instead of one overriding when both sensors are touched
    * Added a mode for slow breath midi (half density). In MIDI menu, hold pinky key when pressing ENTER to activate.
    [NuEVI.ino]
2018-10-27 Version 1.2.9
    * Fix for pitch bend summing near zero.
    * Deglitch setting now in steps of 1ms
    * Velocity sample delay setting now in steps of 1ms
    [NuEVI.ino]
2018-12-18 Added CC#20 as option for breath CC (to work well with IK Multimedia UNO synth). Made compile option for Bruce Cassidy special version (third trill key +3 instead of +4). Bug fix, check for number of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
    [NuEVI.ino]
2018-12-28 Added anti-glitch for top roller when in bottom octave. Added individual note-offs efter All Notes Off at MIDI Panic (to work in Logic and other software not recognizing the regular All Notes Off).
    [NuEVI.ino]
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2019-03-04 Adjust parens to fix compiler warnings
    [NuEVI.ino]
2019-03-04 Move all source files to subdirectory to be less confusing for Arduino IDE
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2019-03-05 Let us not rename files right now.
    This reverts commit 347b6e5c71ea4c537caaec08537b96d3f825ece0.
    [midi.ino]
2019-03-21 Added way to enter regular menu instead of rotator menu (touch special key) if touch sensing is set too high. Added support for pneumatic bite sensing (add-on board). Experimental pitch CV out for bu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
    [NuEVI.ino, hardware.h]
2019-05-25 Support for CV box/CV board (compile option). Match idle CV from PWM breath CV on A6 to direct output idle voltage from breath sensor (so any of them can be used for CV box without need for recalibra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
    [NuEVI.ino]
2019-06-03 Renamed menu.ino to menu.cpp
    This change required lots of other changes to have it compile. I had to declare all variables from NuEVI.ino used by the menu as extern in a separate header file (globals.h).
    Also I moved all defines from NuEVI.ino to a config.h file. I think some of these could be moved back or even moved into menu.cpp.
    I declared many variables and functions in menu.cpp as static and moved them around to avoid forward declarations. For simplicity I did some forward declarations anyway.
    Some varibles only used in menu.cpp was moved from NuEVI.ino instead of having them as externals.
    [NuEVI.ino, config.h, menu.cpp]
2019-06-06 Avoid converting value to a double
    No need to convert a value to double when all we want is a two digits converted to string.
    This also avoids linking some math library, which saved almost 8K och program storage space.
    [menu.cpp]
2019-06-07 Fix problem where the V was still visible if battery low
    [menu.cpp]
2019-06-08 Move access to usbMIDI to midi.ino
    NuEVI.ino shouldn’t have to know about usbMIDI.
2019-06-09 Save memory by changing int arrays to const short arrays
    No need to have them in RAM since they are never changed, and their value was never higher than 14 bits, so using 32 was just a waste.
    [NuEVI.ino]
2019-06-13 Simple simulation code
    Builds a native program on MacOS that runs the NuEVI firmware compiled for x86_64.
    Only input is arrow keys for menu buttons for now. Only output is console and display.
    Copied some more library files into the simulation folder, and renamed the modified *.cpp files from the libraries to *_sim.cpp.
2019-06-21 Fake input and bug fixes
    * Press W in simulator to activate (pretty slow shit, do avoid unless compiling with optimisations)
    * Tiny improvement of the EEPROM simulation.
    * Fixed type typo for millis and micros
    [nuevisim.cpp]
2019-06-21 More inputs and outputs added in simulator
    * Set default value for battery sensor input
    * Show EEPROM values as unsigned.
    * Simulate K1 to K7 inputs (valve and trills++)
2019-06-21 More globals in UI + workaround for bug in firmware
    A bug in the current NuEVI.ino does not write all default values to EEPROM on the first boot, unless menu + enter buttons are pressed. I added a workaround to the simulator that fakes that the buttons are pressed when calling the setup function.
    [nuevisim.cpp]
2019-06-23 Write new factor constants even if old version was < 24
    This bug would probably never happen in real life, and could be fix by holding down menu and enter buttons at startup. But a bug is a bug.
    The only reason I found this bug is that the simulator didn’t initialise EEPROM to 0xff, and even after I did that it crashed, because a version of 0xffff wasn't handled.
    [NuEVI.ino]
2019-06-23 Press buttons 1-7 for valves and trills and left index input
    Also moved bug workaround code to be in the same function for simpler removal at later stage.
    [nuevisim.cpp]
2019-06-23 First iteration of menu cleanup
    * Broke up the code into more general functions instead of duplicating code
    * Made stuff const and removed variables no longer used
    * Use defines for menu button values
    * Changed the order or things to avoid forward declarations
    * Use array lookup instead of switch-case on some menu options
    * Adjust menu functionification
    * Cleaned up sensor rendering
    [NuEVI.ino, menu.cpp]
2019-06-23 Two unrelated changes
    * Move text print of submenu into function
    * No need to check if value changed since writeSettings uses EEPROM.update.
2019-06-23 Avoid calling display.display() twice in an update.
    Moved functions around to have a better overview of draw function. This will make it easier for me to continue with the next part, which probably will be a more generic handling of menus.
    [menu.cpp]
2019-06-23 Menu selection is now data driven
    Some major refactoring has been going on.
    Added simple structs of data containing info about what action to take when a menu item is selected.
    Finally removed all but one call to display.display() in menu-function. There might still be more than one call to it on a frame though, since some functions still calls it internally.
2019-06-23 Made the sensor adjust menu driven by data
    * Moved menu titles and option names into data structures.
    * Unified select menu option code
    * Also unified handling of menu selection, although main and rotator menus are still handled the old way.
    * Moved struct definitions to numenu.h
    * Grouped functions and variables together based on usage.
2019-06-23 Pass *currentPage to functions instead of the original page data
    This way it will be easier to break out even more functionality into more general functions.
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2019-06-23 Missed a few spots for sub menu redraw
    [menu.cpp]
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2019-06-23 Handle sub menus in a generic way and moved adjust menu logic to separate file
    This is a big one where I can finally reap what I sown. Sub menu entries now provide two functions, one to get the text for the current value and one to apply changes aka save to EEPROM. With this I can replace so much code in the menu() function that handles input, but was _almost_ identical. The process of converting the old menus are not completed, and I can probably remove about 200 lines more code.
    The question is still what to do with less general menus like the rotator and fast patch menu.
    One problem with the current implementation is that it is RAM heavy. It seems the const MenuEntry structs are placed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
    [adjustmenu.cpp, menu.cpp]
2019-06-23 Converted more of the sub menus to the new sub definitions
    Found out that it’s the lambda functions used for pointer that forces the structs to be in ram instead or rom.
2019-06-23 Removed code duplication
    Also fixed bug were I reset the active sub menu when then sleep timer kicks in.
    [menu.cpp]
2019-06-23 Moved over the rotation menu to new system
    Had to change how the values where stored in RAM from singed to unsigned to be able to use the generic menu features. Also had to add the MenuEntrySub as a parameter to the menu callback functions to be able fo display and store the correct values.
    Did some major cleanup now that the special case of rotator menu is gone together with all uses of the old version of the sub menu struct.
    [NuEVI.ino, menu.cpp]
2019-06-23 Tiny adjust menu redraw bug fix
    Had forgotten to redraw adjust menu after normal update, it was only redrawn when the sensor pixels were to be updated.
    As a bonus I cleaned up some code.
    [menu.cpp]
2019-06-23 Final push to unify all menu states
    All states are now handled by the new menu system, although some are flagged to have a custom handler that does everything by itself.
    I replaced most reference parameters to pointers to be able to typecast in a nicer way.
    Key input is not passed as a parameter to the menu functions instead of having global variables they all access. I think I broke one thing by doing this, since there is no way to propagate key input changes to the next frame.
    [adjustmenu.cpp, menu.cpp]
2019-06-23 Reduced code duplication and fixed adjust cursor bug
    [adjustmenu.cpp]
2019-06-23 Fixed text alignment for sub values with units
    [menu.cpp]
2019-06-24 Check for correct target platform and USB type
    [NuEVI.ino]
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2019-06-24 Fixed som redraw issues
    [menu.cpp]
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2019-06-26 Fixed regression bug for patch select
    After the menu refactoring, switching patch with up/down buttons when screen was off didn't work correctly. Now it should work like before i.e. switch patch on first press of button and not requiring a second press.
    [menu.cpp]
2019-06-26 Out of bounds check fix
    [NuEVI.ino]
2019-07-01 More correct display simulation
    enable/disable works more like the real thing, however not entirely correct. When enabling the display, it takes the current content of the screen buffer instead of the data that has been send to the display controller.
    [nuevisim.cpp]
2019-07-12 Deglitching on keys also for CV note pitch. CV note pitch now also changes immediately when new note is fingered in note off state, not waiting for new note on.
2019-07-15 Added secondary breath CC setting (free 1-127) with a rise multiplier to make this CC rise faster than primary CC, for example to get a fast rising VCA control together with a less steep VCF slope. C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
    [NuEVI.ino, adjustmenu.cpp, config.h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]
2019-07-17 Flush screen buffer when sub cursor is black
    Fixes issue #25
    [menu.cpp]
2019-07-18 Added possibility to use bite sensor for vibrato.
    [NuEVI.ino, menu.cpp, settings.h]
2019-07-18 Added portamento on vibrato lever when vibrato is controlled with bite
    [NuEVI.ino]
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2019-07-25 Force flags from dipSw to "nice 1-bit values" to prevent menus from locking up
    [settings.cpp]
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2019-07-26 Move all the LED things to a separate file, as mentioned in comments
2019-07-27 Init variables to avoid (incorrect) compiler warnings
    [NuEVI.ino]
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2019-07-29 Take exception to exceptions to handle argparser errors and help
    [nuevisim.cpp, settings.h]
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2019-08-05 Add functionality to use files as MIDI data to send to simulated device
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2019-08-09 Add "magic" CRC value that skips verification (for testing purposes)
    [settings.cpp, settings.h]
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2019-08-20 Adjust bite vibrato sensitivity range.
    [NuEVI.ino]
2019-08-21 Added secondary CC for extra controller and a Level CC control (stored), both with new settings for pinky key. New pinky settings: "EC2" sends on/off (127/0) for extra ctr CC2. "ECS" uses pinky key a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
2019-08-25 Fix for bite vibrato sensitivity. Added increased range of sensitivity settings. Added possibility to use both bite and lever for vibrato at the same time. Separate timing interval for breath (trying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
    [NuEVI.ino, config.h, menu.cpp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]
2019-09-11 Octave setting had stopped working. Corrected.
    [NuEVI.ino]
2019-09-17 Added latest NuEVI schematic, board and gerber files.
    [NuEVI.brd, NuEVI.sch]
2019-10-15 Found culprit in long lags issue in doorKnobCheck function. Reading keys again for that was not very clever... Fixed! Still want some more speed for main loop though. Now getting 6-7 ms. Had 5 ms bac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
    [NuEVI.ino, config.h, menu.cpp]
2019-10-16 Avoid floating-point math for vibrato calculations
    [NuEVI.ino]
2019-10-20 Changed LVL/GLD controls to K6 (increase) and K5 (decrease) to lessen risk of accidental change. LED indicator fix for pinky portamento.
    [NuEVI.ino]
2019-10-22 Fix for negative breath activated controls.
    [NuEVI.ino]
2019-10-22 Fix to get the new pitchlatched patch change the same values as the other legacy ones.
    [NuEVI.ino]
2019-12-11 Now it's also NuRAD firmware! Set define for compile option NURAD in hardware.h to switch. Added a new little thing for NuEVI too: releasing the rollers leaves octave in current one instead of going 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
    [NuEVI.ino, adjustmenu.cpp, config.h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]
2020-02-24 New settings for better portamento performance on Roland SE-02. SEL for switching between OFF and LIN, SEE for switching between OFF and EXP.
2020-03-17 Added fingerings for NuRAD - SAX, EVI, EVR and EWX. Added setting for extra pinky key (NuRAD). Fix for quickpatch function (NuEVI/NuRAD). Rotator menu moved to main menu (NuEVI/NuRAD). Activation of 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
    [NuEVI.ino, config.h, hardware.h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]
2020-03-24 Added hex files, user guides and fingering charts.
    [pla-pkey-nurad.scad]
2020-04-27 Added battery type setting and detailed battery info in ABOUT menu (support for NiMH and LiPo batteries). Added lip sensor activated harmonic series, with settings for range and series type. Added Nu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
2020-05-17 Quick fix... octave setting missing from fingered note calculation for NuRAD
    [NuEVI.ino]
2020-06-04 Fix for SAX fingering and updated fingering chart (NuRAD). Experimental fingerings using rollers for harmonic series (NuEVI). LED indication for extra controller sensor and startup LED check and also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
    [NuEVI.ino, config.h, led.cpp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]
2020-07-19 For NuRAD: Fix for SAX fingering (LH2+RH2 now plays Bb). Added Gate Hold functionality from NuEVI, using thumb folded in over R2 through R5 in place of the "doorknob" grip on the EVI. For NuRAD and N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
    [NuEVI.ino, menu.cpp, settings.cpp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]
2020-07-22 NuEVI and NuRAD: Timing and speed issue solved - SSD1306 display library needed editing to prevent it from lowering I2C bus speed. Added setting to enable/disable the on the fly key switching. NuRAD: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
    [NuEVI.ino, adjustmenu.cpp, config.h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]
2020-07-23 Added automatic sensor calibration performed at factory reset. Changed some default values for settings.
    [NuEVI.ino, config.h, settings.h]
2020-08-19 * Adjustment setting for thumb lever (for optimizing thumb portamento control). By setting THR (level of push force to activate) and MAX (level of push force to achieve maximum set portamento) values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
    * Glide setting SWO, SWitching Only, sending only Glide on/off (CC#65) for use with synths where glide rate CC#5 is used in non standard ways, for example some DSI/Sequential synths like the Prophet 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
2020-08-21 * AUTOCAL is available for each ADJUST menu page. With cursor on THR or MAX bar, press UP and DOWN buttons at the same time (and keep off the sensors being calibrated). AUTOCAL will be displayed for 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
    [removed for now - needs work] * Experimental breath controlled harmonic series (BRTH HARM and BR HM SEL settings). Like the lip sensor harmonics function, this shifts the fingered note up the harmonic series. For improved switching speed, try turning down the key deglitch time. (If this function is to be kept, I will probably need to tweak it quite a bit. Tongueing into higher notes and releasing them does not work well currently.)
    [NuEVI.ino, adjustmenu.cpp, config.h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]
2020-09-04 Added compile option to include a MPR121 board adress scanning function for troubleshooting (MENU button at startup). Changed the destination setup for bite and lever to be less confusing and more po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
    BITE CTL and LEVER CTL can both be set to any of these destinations:
    OFF - no destination active for this controller
    VIB - vibrato
    GLD - glide/portamento (defined by GLIDE MOD and GLIDE LMT settings)
    CC - custom CC output (defined in GLIDE CC and LEVER CC settings)
    Settings in GLIDE CC and LEVER CC are only used when correspond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
    [NuEVI.ino, config.h, hardware.h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]
2020-10-10 * Changed names for ADJUST page titles (to shorten) and added numerical value readouts for THR and MAX settings. * Corrected start position for rotators and added reset to first position when activat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
    [NuEVI.ino, adjustmenu.cpp, config.h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]
2021-01-01 Adjusted default breath cal offset value. Added inverted octave rollers option for NuEVI (EVR in fingering menu). Support for CME WIDI chip connected to Teensy underside pads. Alternate Serial2 TX pa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
    [NuEVI.ino, adjustmenu.cpp, config.h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]
2021-01-01 Editing SSD1306 library for I2C speed no longer neccessary.
    [menu.cpp]
2021-01-28 Bug fixes. Lipo full value adjustment. ECB setting for pinky key disabled extra controller.
    [NuEVI.ino, config.h]
2021-02-20 * Added three new settings in EXTRAS MENU – CV TUNE, CV SCALE and CV EC LFO. The first two allow for software tuning of the CV output for 1V/Oct when using NuEVI CV, NuEVI Plus or NuEVI/NuRAD with ex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
    [NuEVI.ino, config.h, menu.cpp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]
2021-02-26 Small fix for CV LFO vibrato.
    [NuEVI.ino]
2021-02-26 Bug fix. CV portamento in combination with pitch bend would make the pitch bend range be all over the place.
    [NuEVI.ino]
2021-03-20 Small tweak to CC intervals (mainly for pitch bend message interval update as a slight steppiness could be detected in some situations)
2021-07-09 * New quarter tone setting for Pinky Key (NuEVI) and Mod Key (NuRAD) – QTN. This makes the Pinky/Mod key a key for playing one quarter tone down using pitchbend (MIDI) or directly affecting the built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
    * Changes to extra controller harmonics settings (experimental). Reverse direction options (ending with an ‘R’) available following the ones goin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
    [NuEVI.ino, config.h, menu.cpp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]
2021-07-29 Use enum naming convention
    The same naming convention for enum as was used in menu should also apply to new enum.
    Fixed some compiler warnings in menu.
    Moved enum and struct in globals.h away from the middle of #define block.
    [NuEVI.ino, menu.cpp, settings.cpp]
2023-05-03 Fix compilation error for NuRAD
    There was a compilation error introduced for NuRAD builds after the rotator refactoring.
    Unless SEAMUS was also defined, there was still a reference to the old define for Rotator settings.
    [NuEVI.ino]
2023-05-03 Avoid buffer overrun
    Make sure string buffer also have space for `\0` char.
    Casted 8 to `size_t` to avoid compilation warnings.
    [settings.cpp]
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2024-03-06 Fix for CV glide and vibrato in combination
    [NuEVI.ino]
2025-07-24 Added sure y/n for factory reset.
    [NuEVI.ino, menu.cpp, settings.cpp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]
2026-01-13 Fixes: bug when cv vibrato was off, aux ctl menu bug, ex led now only active when ex has destination set
    [NuEVI.ino, config.h, led.cpp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]
2026-03-12 Replace preprocessor "or" with "||" everywhere
    [NuEVI.ino, adjustmenu.cpp, menu.cpp]
2026-03-13 Stupid tricks to avoid compiler warning
    [NuEVI.ino]
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2026-03-13 Include lever settings among "skippable items"
    [settings.cpp]

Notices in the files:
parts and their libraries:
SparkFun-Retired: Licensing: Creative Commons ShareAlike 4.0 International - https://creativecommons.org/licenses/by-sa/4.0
